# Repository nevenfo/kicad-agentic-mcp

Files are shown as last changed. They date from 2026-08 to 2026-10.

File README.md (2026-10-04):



<div align="center">

KiCad Agentic MCP logo

# KiCad Agentic MCP

</div>

**KiCad Agentic MCP is an MCP server and an agentic control layer for KiCad 10.**
An MCP client — Claude Desktop, Claude Code, or anything else that speaks the
[Model Context Protocol](https://modelcontextprotocol.io) — can place and wire
schematic symbols, place and route footprints in the running PCB editor, run ERC
and DRC, search parts, and produce manufacturing output.

What sits between the model and your design files is the reason this project
exists. A model states an intent; a typed plan is compiled and reference-checked
*before* anything is written; execution is deterministic code run as a
transaction with revision checks and rollback; and the verdict on whether a
change is correct comes from KiCad — `kicad-cli` ERC/DRC, or the design read back
— never from the model's own account of what it did. Task state, evidence and
diffs are held server-side, outside any model's context.

The model is asked to reason where reasoning helps: turning a vague request into
a plan. Everything that has to be exact is code.

**Status: v1.2.0**, AGPL-3.0. The server binary is called `konnect`. Every figure
below traces to [docs/benchmark.md](docs/benchmark.md) or to the document named
beside it; what was missed is stated as missed. Issues and PRs are welcome —
[CONTRIBUTING.md](CONTRIBUTING.md), [naming conventions](docs/NAMING_CONVENTIONS.md).

## The control model

```
User intent
    │
    ▼
LLM planning                      where reasoning is useful
    │
    ▼
Plan IR                           typed, reference-checked
    │
    ▼
Deterministic compile + refusal   a plan that cannot finish never starts
    │
    ▼
Transactional execution           revisions, idempotency, rollback
    │
    ▼
KiCad
    │
    ▼
Independent validation + evidence  kicad-cli, and the design read back
```

The bottom half runs whether or not a model was involved: a client that calls
tools directly gets the same compilation, transaction and validation path.

KiCad 10 offers three access routes, and the layer uses each for what it can
actually do — this is fixed by KiCad, not chosen by preference:

```
                          ┌── Schematic ──→ S-expression engine (atomic writes, no running KiCad)
Agentic control layer ────┼── PCB ────────→ KiCad IPC API (NNG + protobuf, KiCad must be running)
                          └── Verify /
                              export ─────→ kicad-cli (ERC, DRC, Gerber, drill, BOM, PDF, 3D)
```

Schematic IPC is empty on KiCad 10 — `schematic_commands.proto` declares no
commands — so the S-expression engine is the only path that exists, not a
workaround. Details and the KiCad-11 re-evaluation are in
[RELEASE_NOTES.md](RELEASE_NOTES.md#kicad-10-status).

### AI where useful, determinism where required

| Responsibility | Owner |
|---|---|
| Turn an ambiguous or high-level request into a plan | An LLM — your client's model, or an opt-in local model |
| Resolve the current project state | Deterministic — an indexed project graph built from the files and the board |
| Check that a plan's references exist and resolve | Deterministic — the plan compiler refuses before the first mutation |
| Compute coordinates | Deterministic — every coordinate the op library emits is grid-snapped |
| Apply the mutation | Deterministic tool handlers |
| Concurrency, idempotency, rollback | Deterministic — revisions, an idempotency ledger, a snapshot journal |
| ERC / DRC | KiCad, through `kicad-cli` |
| Decide whether the operation succeeded | Validators and evidence records, not model prose |

The LLM row is the only one a model owns, and it is optional: by default the
planning model is whatever your MCP client runs. Nothing in the server calls a
model unless you ask it to.

## What one prompt does

<table>
<tr><th width="50%">Before</th><th width="50%">After</th></tr>
<tr>
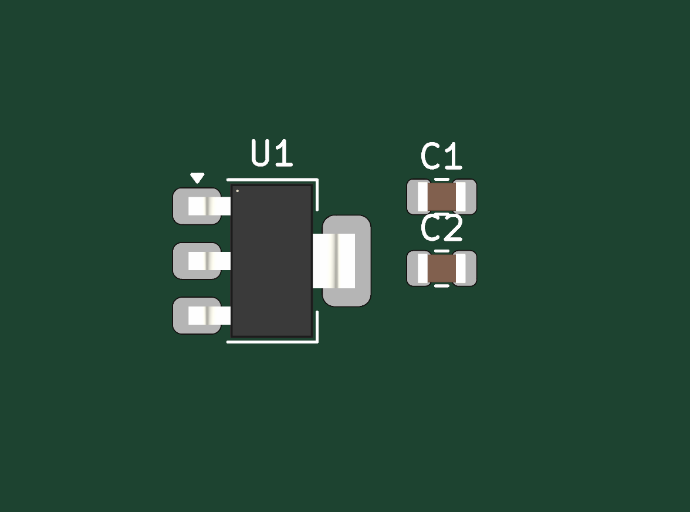
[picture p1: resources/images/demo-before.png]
Three footprints on the board, two capacitors sitting away from the regulator, no copper
<td></td>
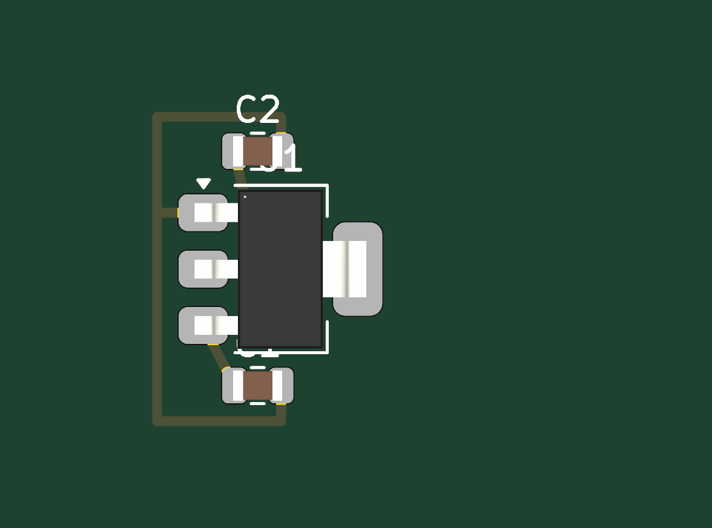
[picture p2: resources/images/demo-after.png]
The two capacitors placed either side of the regulator, three nets closed in copper
<td></td>
</tr>
</table>

One prompt, on the starting board committed in [`examples/demo/`](examples/demo/)
— reproducible from the same files, not an illustration. The prompt asks for the
two capacitors to be placed within 5 mm of the regulator, three nets routed, and
DRC run.

**The verdict is KiCad's:** `kicad-cli pcb drc` reports **5** unconnected items
on the pre-state and **0** afterwards, with 11 track segments and no errors. Run
twice from the same state, it produced the same circuit both times at different
coordinates. Board edits arrive through KiCad's IPC API, so Ctrl+Z walks them
back like any manual edit.

**Two numbers, because they measure two different things:** the board changes
land in **under a second** (0.686 s and 0.773 s of server time), while the prompt
around them takes **6 to 7 minutes**, because the model routes one segment per
turn. Both runs, call by call, are in [`demo-run-2.md`](docs/launch/demo-run-2.md)
and [`demo-run-3.md`](docs/launch/demo-run-3.md); they were run against the
published v1.1.0 binary.

## How execution is controlled

| Mechanism | What it does |
|---|---|
| Plan IR (`preview_plan` / `apply_plan`) | One operation expands into many tool calls, and a later one may reference an earlier one's output. A reference that does not resolve is refused before the first mutation; `preview_plan` returns the exact calls and changes nothing. |
| Gateway (`kicad_describe` / `kicad_invoke`) | Calls any tool by name without adding it to `tools/list`, so the client is never forced to re-fetch the catalogue. `kicad_invoke` takes a batch, stops at the first failure by default, and reports `failed_at` and `not_run`. |
| Transactions and rollback | A batch runs against a directory snapshot; a partial failure restores the before-images. Every mutation leaves an entry in an append-only run journal. |
| Optimistic concurrency and idempotency | `base_revisions` are content-addressed, so an edit made in another window is detected instead of overwritten; an `operation_id` ledger returns the first result on a retry. `changes_since` reports what happened after a revision token. |
| Editor-lock refusal | A `.kicad_sch` KiCad has open is refused (`error_kind: conflict`), re-checked immediately before the commit, leaving the file byte-identical. |
| Semantic diff and evidence handles | Changes are reported by stable item key; snapshots and diffs are addressable MCP resources (`kicad://snapshot/N`, 64 entries). Validator findings carry stable ids, so a fix is an id that disappeared. |
| Task state outside the context | Objective, constraints, verified facts, failed attempts and evidence live server-side and survive a context compaction or a model swap. |
| Project graph | An indexed world model with filtered lookups and spatial neighbours, so a query replaces dumping a whole design. |
| Operating modes | `ReadOnly`, `Write` (default), `Manufacturing`, `Experimental`, enforced before a handler runs so a refusal has nothing to roll back. |
| Structured refusal | A check that could not run is reported as an error, never as a check that passed. |

Architecture, crate by crate, is in [DEV.md](DEV.md#the-agent-layer).

## Measured results

**Against current upstream, on live PCB work:** see
[docs/benchmark-pcb-live-v2.md](docs/benchmark-pcb-live-v2.md) — five live PCB
workflows (schematic → PCB sync, live ≠ saved, zone + net change, flip + via,
schematic parity), the same intention given to this fork and to Konnect
**v0.13.0**, judged by KiCad 10.0.6 alone. That document, not the table below,
is the basis for any comparison with Konnect as it stands today.

**What the table below measured** (token and call cost at the fork point, not
live PCB correctness, and not today's upstream). Seven scripted tasks (schematic authoring, hierarchical
sheets, a template, exports, inspection, and a recovery task where five wrong
inputs must each fail loudly), each starting from an empty directory, five
repeats. Run on 2026-08-24 on one machine — Windows 11, Ryzen 7 9800X3D, KiCad
10.0.3 — against **mixelpixx/Konnect v0.2.2 at commit `5cd6454`**, unmodified,
driven by the same scripted oracle. Success is decided by `kicad-cli` ERC and by
reading the design back, never by a model's prose. Full method, artefacts and
the reproduction commands: [docs/benchmark.md](docs/benchmark.md).

| | Konnect v0.2.2 baseline | This fork, gateway route |
|---|---|---|
| runs passed | 35/35 | 35/35 |
| MCP calls, median per task | 11 | 4 |
| external tokens, median per task | 14 337 | 2 249 |
| wall clock, P50 | 77 ms | 86 ms |

"External tokens" is tool output plus the `tools/list` refreshes the server
forces on the client — a cost the caller cannot decline, and the reason the two
columns differ so much: the gateway route adds nothing to `tools/list`.

**What the same run missed, unmoved:**

- **Wall clock is worse**: 86 ms against 77 ms. The fork loses where it
  guarantees something — the recovery task, which exercises the journal, the
  snapshot manifest and the evidence store, costs +109 ms — and wins where there
  is nothing to guarantee (inspection, 14 → 6 ms).
- **External tokens missed their own target** (≤ 2 000, measured 2 249), and
  **startup `tools/list` missed its target** (≤ ~1 000, measured 2 831 tokens for
  21 tools).
- **Success rate is equal, not ahead.** A scripted route succeeds by construction
  on both servers; what this measures is what the route costs.
- The baseline column was run with one extra toolset loaded, because this fork
  moved `export_bom` between toolsets. Without that, upstream fails the export
  task outright on a taxonomy difference rather than a missing capability; both
  runs are in the benchmark document.

**What this does not measure.** One machine, one KiCad version, scripted routes,
and schematic and export paths only — the golden suite contains no PCB task,
because PCB work needs a running KiCad. It says what a surface costs on that
suite. It does not predict success on an arbitrary KiCad project, and it is not a
statement about Konnect as it stands today.

**The local-model runtime** (`kicad_agent`) is the opt-in path where the server
itself calls a model on loopback: the caller states an objective, the model
writes a Plan IR, and the server compiles, applies and verifies it, with
`kicad-cli` returning the verdict. It has built two of the benchmark designs end
to end, one run each — **no success rate is claimed from that**. Where it was
measured with a sample big enough to carry a number, `gpt-oss-20b` at medium
reasoning wrote a fully correct plan on 16 of 60 one-shot attempts and a
compilable one on 53 of 60. Treat it as working and early, not as a hands-off
autopilot.

## Capabilities

| Area | What it covers |
|---|---|
| Schematic | Symbols, wires, junctions, net labels, power symbols, buses; pin-to-pin connection by name; hierarchical sheets and sheet pins; batch edits |
| PCB | Footprint placement, alignment and duplication; traces, vias, copper pours, net classes, differential pairs; outline, layers, zones, mounting holes, silkscreen |
| Inspection | Net connectivity, pin queries, trace paths, overlap and orphan detection, project-graph queries |
| Validation | ERC and DRC through `kicad-cli`; decoupling, connection, power-rail, DFM and BOM-health audits |
| Fabrication | Gerber, drill, pick-and-place, BOM, netlist, PDF, SVG, 3D, DXF/GenCAD/IPC-2581/ODB++; a fab package with cost estimation and fab-house validation |
| Parts and libraries | Library search and registration, footprint creation and graphics editing, a local JLCPCB parts cache, datasheet lookup, Freerouting autoroute |
| Reference circuits | USB-C, LDO, buck converter, STM32, I2C and LED templates with verified values |
| Bundled for the client | 6 skills and 2 agents carrying KiCad conventions |

**Surface, as a technical fact rather than a headline:** 205 domain tools across
22 toolsets, plus 13 always-visible meta-tools — 217 served in total. The client
does not see them all: startup exposes a **21-tool** starter kit, toolsets load on
demand, and the gateway calls anything by name without listing it at all. Every
tool, with its source file, is in [tool-directory.md](tool-directory.md).

Of the 186 tools inherited from Konnect v0.2.2, 65 (34.9 %) clear the proof
their transport requires; the baseline itself clears 13, scored by the same
scanner. A tool that only edits a document is not counted until KiCAD has
reloaded what it wrote, and one whose whole effect is on the running editor is
not counted until a live session has been asked what it holds — because three
tools were reporting success while writing keys KiCAD does not have, and no
test made only of our own code could see it. The number was 73.7 % under the
older rule, which asked merely that *a* test run. That matrix is generated from
the source and a test fails if it has drifted —
[docs/capability-matrix.md](docs/capability-matrix.md).

## Quick start

Five steps from the release page to a change KiCad itself confirms. Walked on a
machine that had never had this plugin installed; the record, including what went
wrong, is [docs/launch/first-run-walk.md](docs/launch/first-run-walk.md). That
walk measured about nine clicks and dialogs, two KiCad restarts, and a first task
that came back in 108 ms.

**Before you start** you need KiCad 10 and an MCP client. Nothing else: no Node,
no Python, no package tree. Windows is the platform with the most live testing —
see [Known limitations](#known-limitations).

**1 — Download the plugin package.** From
[Releases](https://github.com/nevenfo/kicad-agentic-mcp/releases), take
`konnect-pcm-v<version>-windows.zip` (or `-macos.zip` / `-linux.zip`). The
`konnect-pcm-*` assets are the KiCad plugin packages; the other archives are
standalone server binaries you do not need for this path.

**2 — Install it.** KiCad 10 → **Plugin and Content Manager** → **Install from
File…** → pick the zip. It installs the moment you select the file — the *Apply
Pending Changes* button stays greyed out and there is nothing further to confirm.
Restart KiCad.

**3 — Turn on the KiCad API.** *Preferences → Plugins* → check **Enable KiCad
API**, then restart KiCad. KiCad ships this **off**, and every PCB tool here
talks to KiCad through it. Schematic editing and exports work without it; live
board editing does not. After the restart the same page should read
`Listening on ipc://…`.

**4 — Point your MCP client at the server.** After a PCM install the binary lives
in your KiCad documents folder:

```
C:\Users\<YOU>\Documents\KiCad\10.0\3rdparty\plugins\com_github_mixelpixx_konnect\bin\konnect.exe
```

Put that path in your client's MCP config — `%APPDATA%\Claude\claude_desktop_config.json`
for Claude Desktop, a `.mcp.json` in your project root for Claude Code:

```json
{
  "mcpServers": {
    "konnect": {
      "command": "C:\\Users\\<YOU>\\Documents\\KiCad\\10.0\\3rdparty\\plugins\\com_github_mixelpixx_konnect\\bin\\konnect.exe"
    }
  }
}
```

Copy-paste versions of both files are in [examples/](examples/). Restart the
client; the server should report **21 tools** at startup — the starter kit. The
rest of the catalogue loads on demand, or is called through the gateway without
ever appearing in `tools/list`. **No settings file is required** for a standard
KiCad 10 install: the server discovers `kicad-cli`, the KiCad GUI binary and the
IPC address. Explicit settings remain available for unusual or portable
installations.

**5 — Give it something to do**, with a KiCad project open. For example:

> *Add a 3.3 V LDO regulator subcircuit to my schematic and run ERC on it.*

The reply should name the parts it placed — a regulator, its input and output
capacitors — and carry an ERC result that came from `kicad-cli`, not from the
model. Open the schematic in KiCad: the symbols are there.

**Check the install itself** at any point: open a project (KiCad's PCB editor
refuses to open without one), then **PCB Editor → Tools → External Plugins**,
where you should see **Konnect**.

**If any of those five steps did not work for you**, that is the thing worth
reporting: [file a first-run report](https://github.com/nevenfo/kicad-agentic-mcp/issues/new?template=first-run.yml).
It takes about two minutes and it is the only way any of this gets measured on a
machine that is not the maintainer's.

### Requirements

- **KiCad 10.** Built and measured against 10.0.3; the live schematic and PCB
  suites of v1.2.0 were also run against 10.0.6. Other 10.0.x releases are
  untested here rather than known-bad.
- **`kicad-cli`**, which ships with KiCad and is used for exports, ERC and DRC.
  KiCad's installer does not put it on `PATH`; the server searches the usual
  install locations and logs which one answered, and you can name it explicitly.
- **For PCB tools: KiCad running** with the target board open and the KiCad API
  switched on (*Preferences → Plugins → Enable KiCad API*, which ships off).

### Build from source

```bash
# protoc is required (protobuf code generation), and cmake (the nng crate
# compiles the NNG C library with it).
# Windows: choco install protoc cmake
# macOS:   brew install protobuf cmake
# Linux:   apt install protobuf-compiler cmake
cargo build --release -p konnect
```

The resulting `target/release/konnect` is the MCP server. The published v1.1.0
Windows binary measured 23.7 MB, unstripped; there is no `[profile.release]`
override, so a local build is the same shape.

### macOS

The PCM package bundles a universal binary; the standalone archives ship
Apple Silicon (`aarch64-apple-darwin`) and Intel (`x86_64-apple-darwin`) builds.
**They are not code-signed or notarised**, so Gatekeeper refuses them on first
launch — clear the quarantine attribute:

```bash
xattr -dr com.apple.quarantine ./konnect   # or the folder KiCad installed it into
```

KiCad on macOS keeps its tools inside the app bundle and off `PATH`; the server
searches the standard bundle and uses KiCad's default IPC address. Only an
unusual or renamed install needs overrides in
`~/Library/Application Support/konnect/config.toml`:

```toml
kicad_cli = "/Applications/KiCad/KiCad.app/Contents/MacOS/kicad-cli"
kicad_binary = "/Applications/KiCad/KiCad.app/Contents/MacOS/kicad"
# Optional override; the default is ipc:///tmp/kicad/api.sock.
ipc_address = "ipc:///tmp/kicad/api.sock"
```

Claude Desktop's config lives at
`~/Library/Application Support/Claude/claude_desktop_config.json` and takes the
same `mcpServers` snippet with a Unix path.

### Schematic viewer

A standalone viewer that auto-refreshes as the schematic file changes:

```bash
schematic-viewer.exe path\to\your\root_schematic.kicad_sch
```

Point it at the root sheet of a hierarchical design and every sub-sheet is
rendered too, with a depth-indented selector. Only the sheets that changed
re-render, against temp-folder snapshots, so the viewer never blocks KiCad from
saving. The AI can launch it via `open_schematic_viewer`. Needs the WebView2
runtime (pre-installed on Windows 10/11) and `kicad-cli`; built separately from
the main workspace — see [DEV.md](DEV.md).

### Transport

MCP JSON-RPC over stdio by default. Streamable HTTP is available with
`transport = "http"` (or `"both"`): POST and GET/SSE on a single `/mcp`
endpoint, with Origin validation and a `/health` probe.

## Known limitations

Stated as four different things, because they are:

**Tested — Windows.** The first-run walk, the demo runs, the benchmark and the
live schematic and PCB suites all ran on Windows 11 with KiCad 10.0.3 (and 10.0.6
for the live suites of this release).

**Supported but less tested — macOS and Linux.** macOS works from the release
binaries or a source build and is not signed or notarised. Linux compiles and
passes CI but has had **no per-platform QA against a running KiCad**. Both are on
the [roadmap](ROADMAP.md).

**Experimental — the local-model runtime.** It works, and its measured plan
quality is the figure quoted above (16/60 fully correct one-shot). It is not a
hands-off autopilot, and no success rate is claimed for it on real projects.

**Not yet built, or not possible here:**

- **PCB tools need a running KiCad** with the API on and the board open. pcbnew
  has no headless mode, so there is no headless PCB path. A desktop session is
  required; a human watching it is not.
- **Symbols and footprints are placed, not authored from scratch.** Footprints
  can be created and their graphics edited; authoring new library symbols is on
  the [roadmap](ROADMAP.md).
- **Schematic editing does not go through IPC** because KiCad 10 exposes no
  schematic IPC commands. This is re-evaluated at KiCad 11, not before.
- **A schematic open in Eeschema is refused, not merged.** Close the editor, or
  work on a copy.
- The benchmark covers a controlled seven-task suite on one machine. It does not
  generalise to arbitrary projects.
- The evidence store holds 64 entries; older handles age out and report
  differently from handles that never existed.

**No telemetry.** The binary reports nothing, anywhere, ever. Everything known
about how it behaves on other people's machines came from someone choosing to
write it down; the tally is [docs/adoption.md](docs/adoption.md).

## Troubleshooting

- **Plugin doesn't appear** — install via the Plugin and Content Manager, not a
  manual copy, then restart KiCad. The entry is under *Tools → External Plugins*
  in the **PCB editor**, which will not open until a project is open.
- **"IPC connect failed"** — two things must both be true: *Enable KiCad API* is
  checked, and KiCad is running with the board open. The API page reads
  `Listening on ipc://…` after a restart.
- **"Failed to spawn kicad-cli"** — the server tries your config value, `PATH`,
  the known install prefixes (including the per-user
  `%LOCALAPPDATA%\Programs\KiCad\<ver>\bin`), then the registry, and logs which
  one answered.
- **A validator reports an error instead of zero findings** — deliberate. A check
  that could not run is never reported as a check that passed.

Longer walkthroughs: [docs/TROUBLESHOOTING.md](docs/TROUBLESHOOTING.md).

## Architecture and references

- [DEV.md](DEV.md) — architecture, the agent layer crate by crate, build steps
- [tool-directory.md](tool-directory.md) — every tool, generated from the source
- [docs/benchmark.md](docs/benchmark.md) — method, artefacts, every number and
  every missed target
- [docs/capability-matrix.md](docs/capability-matrix.md) — what has a test that
  runs, generated and gate-checked
- [docs/local-agents.md](docs/local-agents.md) — the local-model seam, and how it
  was measured
- [RELEASE_NOTES.md](RELEASE_NOTES.md) · [ROADMAP.md](ROADMAP.md) ·
  [CONTRIBUTING.md](CONTRIBUTING.md) ·
  [docs/TROUBLESHOOTING.md](docs/TROUBLESHOOTING.md)

## Relationship to Konnect

```
KiCAD-MCP-Server        Python/TypeScript, MIT, still open and maintained
       │
       ▼
    Konnect             Rust rewrite: one binary, KiCad 10 IPC, toolset router
       │
       ▼ forked from v0.2.2 (commit 5cd6454)
KiCad Agentic MCP       this repository
```

**What comes from upstream:** the Rust single-binary architecture, the KiCad 10
IPC path for the PCB, the S-expression schematic engine, `kicad-cli` for exports
and checks, and the toolset router — the client loads toolsets and calls tools by
name. All of that still works here, unchanged.

**What this fork adds:** the gateway (`kicad_describe` / `kicad_invoke`), the Plan
IR and its deterministic executor, transactions with rollback and a run journal,
revisions and an idempotency ledger, semantic diffs and evidence handles, task
state held outside any model's context, the indexed project graph, tool
capability annotations, and the opt-in local-model runtime. These are the `kam-*`
crates, clean-room and `MIT OR Apache-2.0` in their own manifests, with
KiCad-side adapters in `konnect-core`.

The benchmark above compares this fork against **Konnect v0.2.2 at commit
`5cd6454`**, the exact point it was forked from. It says nothing about Konnect as
it stands today, and no claim of superiority over the current upstream is made or
intended. Upstream remains a separate project under the same AGPL-3.0 licence.

The binary is still called `konnect` and the plugin identifier is still
`com.github.mixelpixx.konnect`, so an existing MCP client configuration keeps
working.

## License

AGPL-3.0-only, workspace-wide — see [LICENSE](LICENSE). Hobbyists, students,
freelancers and open-source projects can use it freely. For a business, the AGPL
requires that anything built on or around it — including software provided over a
network — be open-sourced under the same licence; if that does not work for you,
commercial licences are available: [COMMERCIAL.md](COMMERCIAL.md).

The generic `kam-*` crates (state, evidence, plan, graph, context, llm, runtime)
are clean-room and `MIT OR Apache-2.0` in their own manifests.

## Support

- **Tried it for the first time?**
  [File a first-run report](https://github.com/nevenfo/kicad-agentic-mcp/issues/new?template=first-run.yml)
  — six questions, most of them one click. A report from someone who **gave up**
  is worth more than one from someone who succeeded.
- Bugs and feature requests: [GitHub Issues](https://github.com/nevenfo/kicad-agentic-mcp/issues)
- Installation or IPC problems: [docs/TROUBLESHOOTING.md](docs/TROUBLESHOOTING.md)

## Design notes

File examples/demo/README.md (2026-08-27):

# The canonical demo

One task, and the result appears **in KiCad's own canvas** — not in a terminal.
The AI arranges a subcircuit on the open board and routes it; pcbnew redraws as
it happens, and the changes land in KiCad's undo stack like any manual edit.
The board changes take under a second of Konnect time; the model conversation
around them takes six to seven minutes.

This is the demo the project's launch material shows. It is committed here so
anyone can repeat it from the same starting point and get the same end state.

## Starting point

A real project, not a blank file:

| File | What is in it |
|---|---|
| `konnect-demo.kicad_sch` | `U1` AP1117-33 regulator, `C1` and `C2` 10 µF, footprints assigned, nets `VIN`, `VOUT`, `GND`, two `PWR_FLAG`s. **ERC: 0 errors, 0 warnings** |
| `konnect-demo.kicad_pcb` | a 60 × 45 mm board carrying the three footprints **imported from that schematic and left in a heap**, with their nets. **DRC: 5 missing connections**, 1 silkscreen-clearance warning |
| `konnect-demo.kicad_pro` | the project that ties them together |

The five missing connections are the point. They are what the demo closes.

**Why a schematic ships with a PCB demo:** a KiCad board has nets only because a
schematic gave it some. Routing addresses nets, so a board that never came from
a schematic cannot be routed — by Konnect or by anything else. This is not a
detail of the demo; it is how KiCad works, and pretending otherwise produces a
demo that cannot finish.

Do not edit these files in place. Copy the folder somewhere else and run the demo
on the copy, so the committed pre-state stays the pre-state.

## Setup, once, off the clock

1. Install Konnect and point your MCP client at it — the
   [Quick start](../../README.md#quick-start) has the five steps.
2. In KiCad: *Preferences → Plugins* → **Enable KiCad API**, then restart KiCad.
   PCB tools talk to a running KiCad through that socket; without it there is
   nothing to watch.
3. Open your copy of `konnect-demo.kicad_pro` in KiCad and open its **PCB
   editor**. Leave it on screen — this is what the demo shows.

The setup is outside the measured prompt time.

**On v1.1.1, a standard KiCad 10 install needs no Konnect settings file.**
Konnect discovers `kicad-cli`, the KiCad GUI binary and the IPC address. Use an
explicit override only for an unusual or portable installation; see
[Troubleshooting](../../docs/TROUBLESHOOTING.md).

## The prompt

Ask for it in one turn, exactly this:

> These three footprints were just imported from the schematic and are sitting
> in a heap. Place C1 and C2 within 5 mm of the regulator U1, route VIN, VOUT
> and GND, and run DRC when you are done.

## What you should see

In the KiCad window, without touching it:

- the two capacitors move out of the heap and settle beside the regulator;
- copper traces appear between them, on the nets the schematic named;
- KiCad's undo (Ctrl+Z) walks the changes back, because they arrived through
  KiCad's own API rather than by rewriting the file underneath it.

And in the reply: a DRC result that came from `kicad-cli`, not from the model.
A check that could not run is reported as an error, never as a clean board.

The committed pair — [`before`](../../resources/images/demo-before.png),
[`after`](../../resources/images/demo-after.png) — is what run 2 produced, and
both images come from the board files themselves, same frame and same zoom:

```bash
kicad-cli pcb render --side top --zoom 2.8 --pivot "0.2,0.25,0"   -w 1200 -h 900 --background opaque -o before.png konnect-demo.kicad_pcb
```

Run the same command on the board after the prompt for the other half. Your run
will not match pixel for pixel — a model does not place a capacitor at identical
coordinates twice — and it does not need to: what has to match is the circuit.

## Verifying it afterwards

From the folder you ran the demo in:

```bash
kicad-cli pcb drc --format json -o drc.json konnect-demo.kicad_pcb
```

The pre-state reports **5 missing connections**. A finished run reports **0**.
KiCad, not Konnect and not the model, decides that.

## Reproducing

Start again from the committed files and issue the same prompt. What has to match
is the circuit, not the pixels: same three parts, same three nets connected, same
DRC verdict. A model will not place a capacitor at identical coordinates twice.

It has been run twice this way — `docs/launch/demo-run-2.md` and
`demo-run-3.md`. Both closed the three nets with 11 segments and left KiCad
reporting 0 unconnected items and no errors; both placed the capacitors within
5 mm of `U1`, at coordinates 0.6 mm apart, and run 3 rotated `C2` where run 2
did not.

## How long it takes, and what that measures

Two numbers, because they measure two different things:

- **The board changes land in under a second.** Every call that alters the board
  — the placements, the rotation, the eleven traces, the saves — totalled
  **0.686 s** in run 2 and **0.773 s** in run 3, the slowest single write 0.07 s.
  Including `run_drc`, which is KiCad doing its own check, all Konnect calls came
  to 2.3 s and 4.7 s.
- **The prompt takes 6 to 7 minutes** end to end — 377 s over 47 turns, 424 s
  over 52. That is the model looking, deciding, and routing one segment per turn;
  there is no batch *route this net* call to collapse it into one.

The 40 s figure this demo was first written against measured neither: it was
chosen before anything had been run. It is published here as the two measured
numbers instead, because a demo whose claims survive checking is worth more than
a fast one.

## If you rebuild the pre-state yourself

The board was produced by KiCad's own *Update PCB from Schematic*, which is
available **only when the PCB editor was launched from the KiCad project
manager**. Started standalone, pcbnew refuses with *cannot update the PCB because
the PCB editor is open in standalone mode*. Konnect has no equivalent tool, which
is why this step is setup rather than part of the demo.

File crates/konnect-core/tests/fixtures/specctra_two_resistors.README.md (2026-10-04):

# Specctra two-resistor board fixture

`specctra_two_resistors.kicad_pcb` is a deliberately small two-layer board used
to test the first fail-closed Specctra export profile. It was derived from the
repository's existing PCB integration fixture, assigned stable test UUIDs and a
closed rectangular outline, then opened and re-saved by KiCad 10.0.5 with:

```text
kicad-cli pcb upgrade --force specctra_two_resistors.kicad_pcb
```

That final KiCad-authored serialization is intentional. In particular, it
captures KiCad 10's direct `(net "NAME")` pad syntax rather than relying on a
hand-written approximation of the board format.

`specctra_two_resistors.native-kicad-10.dsn` was exported from that board by
KiCad 10.0.5's real `pcbnew.ExportSpecctraDSN(board, path)` binding. Only the
environment-specific absolute output path in the root `(pcb ...)` identifier
was normalized to `board.dsn`; structure, placement, library, network, rules,
and wiring content remain KiCad-authored. It is the differential fixture for
the optional KiCad 10 ActionPlugin bridge.

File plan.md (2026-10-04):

# PLAN — KiCad Agentic MCP

Strategic source of truth: final target, invariants, full roadmap, dependencies
and validation criteria. Operational state lives in `progress.md`; measurements
live in `docs/benchmark.md`, `docs/local-agents.md`, `docs/capability-matrix.md`
and `bench/results/`; history lives in Git.

**Identifier convention.** Phase letters (`A`…`M`) are the historical phase
names. Lots and tasks are dotted — `D.4`, `H.5.3` — so they never collide with
this project's decision records (`D31`) and defect records (`E24`), which are a
separate namespace referenced from code comments, commit messages and `docs/`.
Look a task up with `rg "H\.5\.3" plan.md`; do not read this file whole.

## Objectif final

Turn the `mixelpixx/Konnect` fork into a KiCad **agentic control layer**: a large
internal capability surface, a small external MCP surface, local LLM agents that
absorb operational work, a deterministic engine for everything that does not need
generative reasoning, task state and evidence held outside any model's context,
and verification that comes from KiCad rather than from an agent's own opinion.

```
WORKSPACE  C:\Users\FlowUP\kicad-agentic-mcp\konnect-agentic   branch agentic/main
BASE       mixelpixx/Konnect @ 5cd6454 (v0.2.2), AGPL-3.0-only, workspace-wide
KICAD      10.0.3, C:\Users\FlowUP\AppData\Local\Programs\KiCad\10.0\bin\kicad-cli.exe
HARDWARE   RTX 5080 16 303 MiB VRAM · Ryzen 7 9800X3D · 32 GiB RAM · LM Studio
```

16 GB VRAM is the hard budget for any local model: it must hold the model, the
KV cache and whatever KiCad's GUI is using.

## Invariants

Rules that survive every phase. Breaking one is a defect, not a trade-off.

- **INV1 — the verdict is KiCad's.** A design is declared sound by `kicad-cli`
  ERC/DRC, never by Konnect's own analysis and never by a model. A validator that
  could not run is a failure, never zero findings.
- **INV2 — generic subsystems stay re-licensable.** New `kam-*` crates are
  clean-room, `MIT OR Apache-2.0`, and depend on no `konnect-*` type. The KiCAD
  half of each lives in `konnect-core::<same name>`. AGPL never flows into them;
  absorbed MIT code travels with its notice.
- **INV3 — no mutation without an audit record**, and every change carries its
  own proof (semantic diff on by default, evidence handles, call log).
- **INV4 — refuse before the first mutation.** Compile-time reference checking,
  `base_revisions`, unknown validator names and unrecognised `verify` values are
  all rejected before anything is written. A caller who believes a check ran when
  it did not is the worst failure mode this project has shipped.
- **INV5 — one grid, one place.** Every electrically meaningful `(at x y)` goes
  through the single snapping helper over `SCHEMATIC_GRID_MM` (1.27 mm). A
  guarantee that holds *usually* is the bug it is meant to prevent.
- **INV6 — a target that is missed is recorded as missed**, never moved to match
  the result, and no win is netted off against it. A number that cannot be
  reproduced from the repository is not a result.
- **INV7 — advisory analysis says so at the call site**, in the tool description
  an agent actually reads, not only in a generated document.
- **INV8 — accept what a model writes only when it has exactly one meaning.**
  Genuine ambiguity stays refused; a widened acceptance must never turn a
  previously compiling input into a failure.
- **INV9 — the local inference backend is loopback-only** unless a named
  constructor says otherwise. Exposing it to the network must be something
  somebody typed.
- **INV10 — the KiCad access strategy is fixed by KiCad 10, not by preference:**
  PCB over IPC, schematic over the S-expression engine, validation and export
  over `kicad-cli`. Do not fork KiCad; re-evaluate at KiCad 11 (Phase I).
- **INV11 — a checkbox in this file means proof**, not intention: targeted tests,
  integration, gate, or a benchmark run whose artefact is committed.

## Plateforme : KiCad 10 ground truth

Verified against KiCad sources, 2026-08-10. These are constraints, not opinions.

| Fact | Consequence |
|---|---|
| IPC = NNG REQ/REP + protobuf envelope, `KICAD_API_SOCKET` / `KICAD_API_TOKEN`, API disabled by default | `doctor` must check and say so |
| No protocol version, only `GetVersion` | capability probing is behavioural |
| **No async events, no pub/sub** | the event journal is ours: revisions + targeted diffing + file watching. Never advertise push notifications |
| Server is single-threaded on the UI thread | serialise IPC, own timeout/retry, expect `AS_BUSY` |
| `BeginCommit` / `EndCommit` exist on PCB **and** SCH handlers | the real transaction primitive for the IPC path |
| PCB coverage complete over IPC | PCB path = IPC |
| **Schematic IPC is empty on 10.0** (`schematic_commands.proto` has no commands, `getItemFromDocument()` returns `nullopt`) | schematic path = S-expression engine |
| `kicad-python` 0.8.0 + `kicad-cli api-server` target **KiCad 11** | headless schematic IPC is upstream work; do not fork KiCad 10 |
| S-expr versions on 10.0: board `20260206`, schematic `20260306`, symbol lib `20251024` | parser/writer compat matrix |

## Architecture cible

```
harness (Claude Code / Codex)
        │  EXECUTION PATH: delegate            AUDIT PATH: query / verify / evidence
        ▼
┌──────────────────────────┐
│ MCP GATEWAY (small)      │  kicad_describe + kicad_invoke                SHIPPED
├──────────────────────────┤
│ TASK STATE MANAGER       │  objective / constraints / facts / failures   SHIPPED
├──────────────────────────┤
│ CONTEXT + ATTENTION MGR  │  anchor · budgets · compaction · retrieval       SHIPPED
├──────────────────────────┤
│ AGENT ROUTER             │  NO_LLM | LOCAL | ESCALATE (fitted, H.6.2)        SHIPPED
├──────────────────────────┤
│ LOCAL AGENT RUNTIME      │  supervisor / schematic / pcb / verification      SHIPPED
├──────────────────────────┤
│ PLAN COMPILER + PLAN IR  │  typed, reference-checked, batched            SHIPPED
├──────────────────────────┤
│ DETERMINISTIC ENGINE     │  ~190 capabilities + revisions + transactions SHIPPED
├──────────────────────────┤
│ KiCad: IPC (PCB) · S-expr (SCH) · kicad-cli (validate/export)
├──────────────────────────┤
│ VALIDATION + EVIDENCE    │  ERC/DRC, semantic diff, evidence packs       SHIPPED
└──────────────────────────┘
```

Crates (new ones obey INV2):

```
crates/konnect-*      existing, AGPL, refactored in place
crates/kam-state      revisions, idempotency, snapshots, Task State + anchor      SHIPPED
crates/kam-evidence   semantic diff over an abstract ItemSet, handle store,
                      findings with stable ids                                    SHIPPED
crates/kam-plan       Plan IR, compiler, reference resolution, execution FSM      SHIPPED
crates/kam-graph      indexed store + query/neighbour language                    SHIPPED
crates/kam-llm        local provider abstraction (+ router, not built)            PARTIAL
crates/kam-context    budgets, compaction, retrieval                              SHIPPED
crates/kam-bench      benchmark runner + metrics schema                           NOT BUILT (Python harness in bench/ does the job today)
```

## Critères globaux de réussite (V1)

Current values: `docs/benchmark.md`. Targets are never moved (INV6).

- [x] `SUCCESS_RATE` ≥ baseline — **35/35 against the baseline's 35/35** (M.1,
      seven tasks × 5, both servers measured back to back on 2026-08-24). Equal,
      which is what `≥` asks; a scripted route succeeds by construction on both
      sides, and the fork's margin is in what the route costs and in what
      happens when nobody scripts it
- [x] median `MCP_CALLS` per task ≤ 5 — **4**
- [ ] `WALL_CLOCK_P50` ≤ baseline — **86 ms against 77 ms, missed by 9 ms**
      (M.1). The recorded pair was 65 against 70. The mechanism is per-task and
      visible: the fork loses where it guarantees something — `recovery`
      +109 ms, the task built to exercise the transaction journal, the snapshot
      manifest and the evidence store — and wins where there is nothing to
      guarantee (`sch_inspection`, 14 → 6 ms). The direction is stable and the
      magnitude is not: an earlier `--repeat 3` pair the same day reads 69
      against 87, the fork slower by 18 rather than by 9. Recorded as missed
      (INV6); nothing was tuned to recover it
- [x] silent corruption / silent stale-state write = **0** — refused by `base_revisions`
- [x] mutations without an audit record = **0**
- [ ] external tokens/task ≤ 2 000 — **2 249**, missed by 249 in deliberate
      trades (diff on by default, task filing, verification, and D.5's snapshot
      handle at +18); recorded as missed, never netted off against a win.
      M.1 re-measured it and found +68 since `k12-gateway.json` (2026-08-17):
      F.5.7's descriptions and K.2's annotations both ride inside
      `kicad_describe` results, so both are paid per task and not only on the
      startup surface. K.2's +342 at startup was measured when it landed; this
      is its per-task share, measured now
- [ ] `tools/list` at startup ≤ ~1 000 — **2 831**, missed; only reachable by
      retiring the toolset-loading path, which would break every shipped skill.
      Re-measured at `91b9911` before touching anything: the recorded 2 034 was
      stale — the surface had already drifted to **2 489** as descriptions grew.
      K.2's annotations then cost **+342** (2 489 → 2 831, +13.7 %; full catalog
      29 399 → 33 183). Paid deliberately: a surface a headless client will not
      call is worth no tokens at all. The cheaper shape was measured, not
      assumed — dropping `openWorldHint` from read tools saves 78 of the 342
      and was rejected, because omitting it asserts the MCP default of
      *open world* about every read tool to save 2.8 %
- [x] retrieval precision @8 ≥ 60 % — **62.0 %** (recall @8 **100 %**) — F.5
- [ ] `LLM_CALLS_PER_SUCCESSFUL_TASK` materially below baseline — measured
      **15 → 5.5** inside the model-fit harness, but **no baseline for this
      metric was ever measured**, so the criterion is not claimed met
- [x] `CAPABILITY_COVERAGE` > baseline — **72.6 % against the baseline's
      22.6 %**, on a frozen denominator of 186, with no regression. Defined in
      J.2.1 and rendered in `docs/capability-matrix.md` under
      *V1 comparison target*: the 187 tools the baseline registers at `5cd6454`
      (this fork still registers all of them), minus what KiCAD gives no API
      for, scored on both sides by the same scanner. The headline number is
      the whole-surface number and is deliberately not the criterion — its
      denominator grows with every tool added; it stands at **72.6 %** too after
      J.2.3. Nothing this fork adds can enter the frozen denominator, so that
      percentage moves only when a test that runs starts proving a tool

---

# Phase A — Bootstrap — DONE

## A.1 — Base selection (Gate 0)

### Objectif
Choose the base repository on measured evidence and record the licence posture.

### Dépendances
None.

### Tâches
- [x] A.1.1 Compare `Konnect` / `kicad-mcp-pro` / legacy `KiCAD-MCP-Server`
- [x] A.1.2 Verify licences and choose officially → Konnect, AGPL-3.0-only
- [x] A.1.3 Clone into a clean workspace, branch `agentic/main`

### Validation
`cargo test --workspace --lib --tests` → 469 passed on the untouched fork.
Full comparison and rationale: `git show HEAD:plan.md` (Gate 0 sections, before
this file was migrated) and decisions D1/D2.

**Why not `kicad-mcp-pro` as the base** (still the reason not to migrate): its
schematic writer depends on `kicad-sch-api`, which drops `global_label` nodes on
save, so its own mitigation refuses the write; profiles are boot-time only; three
build systems; 251 Python modules force deferred registration. Its *ideas* were
adopted clean-room and are tracked as tasks (D.6, D.7, D.8, D.9, J.5, M.1).

## A.2 — Build, tests, real MCP session — DONE

### Tâches
- [x] A.2.1 Build and test the fork on this machine (`protoc` provisioned, E1)
- [x] A.2.2 Run the server against a real harness over stdio
- [x] A.2.3 `gate.ps1` mirrors the upstream CI gate

### Validation
`gate.ps1` green; per-user KiCad installs discovered (E3).

---

# Phase B — Cartography — DONE

## B.1 — Map the base

### Tâches
- [x] B.1.1 Map transport, registry, IPC, S-expression engine, validation, errors
- [x] B.1.2 Verify the KiCad 10 ground truth against KiCad's own sources

### Validation
The ground-truth table above; every claim traced to a KiCad source file.

---

# Phase C — Baseline benchmark — DONE

## C.1 — Golden suite and metrics

### Objectif
Measure the untouched base before any refactor, so every later claim has a floor.

### Dépendances
A.2.

### Tâches
- [x] C.1.1 Golden projects + task set (6 tasks × 3 load modes = 18)
- [x] C.1.2 Metrics schema: tokens, calls, latency, success
- [x] C.1.3 Baseline recorded

### Validation
`docs/benchmark.md`, `bench/results/*baseline*.json`: 12 373 external tokens/task,
11 MCP calls, 18/18.

---

# Phase F — Compact MCP surface — DONE

## F.1 — Capability index and tool-granular loading

### Tâches
- [x] F.1.1 `find_capabilities` + `load_tools` beside `list_toolboxes` / `load_toolset`
- [x] F.1.2 Keep both loading paths (D5: removing one breaks every shipped skill)

### Validation
Retrieval recall @8 = 100 %; measured in `docs/benchmark.md`.

## F.2 — Schema compression and starter kit

### Tâches
- [x] F.2.1 Compress heavy inlined schemas — no `$defs`/`$ref` (D7: client chain
      mangles them; several upstream issues recommend inlining instead)
- [x] F.2.2 Shrink the starter kit — `config` leaves, two tools re-admitted
      individually (D8), checked against `find_capabilities` on their own intents

### Validation
3 698 → 3 197 tk/task, startup 1 958 → 1 454 at the time.

## F.3 — The gateway

### Objectif
A catalogue that never has to be refreshed: `CATALOG_TOKENS` → 0.

### Tâches
- [x] F.3.1 `kicad_describe` + `kicad_invoke` — **two** verbs, not seven (D9)
- [x] F.3.2 Batch semantics: `stop_on_error`, and `atomic` follows it unless set
      explicitly (D10 — found by the benchmark, not by review)

### Validation
1 995 tk/task, 4 MCP calls, `CATALOG_TOKENS` 0, 18/18.

## F.4 — Capability matrix

### Tâches
- [x] F.4.1 `docs/capability-matrix.md` generated from `konnect-core::capability`
- [x] F.4.2 `SUPPORTED` is discovered from tests and golden tasks, never declared
      (D26); `#[ignore]`d tests read `gated`; what KiCad has no API for leaves the
      denominator
- [x] F.4.3 Three tests: manifest names every registered tool, names no tool that
      does not exist, committed markdown equals what the code renders

### Validation
`KAM_UPDATE_MATRIX=1` regenerates; the equality test fails if it drifts. First
render 27.3 %, now 28.6 %. Note: `bench/probes` counts as evidence as well as
`bench/tasks`, so adding a probe can move the number.

## F.5 — Retrieval precision — MET

### Objectif
22.4 % precision @8 at the recall needed to succeed. The gateway made each wrong
guess cheap; it did not make the guess right.

**Closed at 62.0 % precision / 100.0 % recall** (b3a1572), measured by
`bench/runner.py --load-mode search`. The suite's success rate in that mode
went 6/7 to 7/7 and external tokens per task 10 446 → 5 205.

### Dépendances
None. Plural stemming was implemented, measured and **rejected** (D6): recall
100 % → 98.2 % at 8 results. Do not re-attempt it.

### Tâches
- [x] F.5.1 Find a retrieval change that raises precision without costing recall
      — four of them, in F.5.4 through F.5.6: IDF weighting, clause splitting,
      a relative cutoff per clause, and one tool per family. Recall went up
      rather than down (97.1 % → 100 %).
- [x] F.5.2 Answer whether a compiled plan moves precision at all. **It does
      not**, and it fails in both directions at once, measured by
      `bench/plan_retrieval.py` at limit 8 on one build against the direct
      shape of `01_sch_divider` read from the task file: not one of four
      goal-stated queries returns `apply_plan`, at rank 8 or at rank 30 —
      "build a resistive voltage divider" returns `audit_power_rails` — because
      the description is about the mechanism of calling and shares no
      vocabulary with a query saying what to build; and for a caller who does
      name the mechanism, retrieval finds it at rank 1-2 while precision falls
      to 11.1 %, since the plan collapses |needed| from 5 to 1 without
      collapsing what search returns. The plan path is entered by prior
      knowledge, never by search, and precision @8 is the wrong instrument for
      it — its measured win is schema tokens (G.3: -48.4 % / -61.1 %)
- [x] F.5.3 Reverse prefix: the one-sided form of what D6 rejected. A query
      term that is the longer, plural side of a corpus term of at least three
      characters scores a fallback +4/+1, and only when nothing stronger
      already matched — purely additive, so D6's failure mode cannot recur,
      and its negative control is now a pinned test. Measured: recall on the
      seventh task 94.3 % → 97.1 %, hist6 recall unchanged at 100 %, precision
      22.5 % → 22.2 %. It buys recall, not precision; F.5.1 stays open.
- [x] F.5.4 The precision ceiling is *how many* results come back, not their
      order: every intent returns a full `limit`, so the union is ~33.8 tools
      per task against ~7.5 needed. A relative score threshold cuts the union
      to 12 and lifts precision to 65 %, but drops recall to 94 %, and every
      tool it drops is one whose intent is **composite** — a single intent
      asking for two or three tools, lexically dominated by one of them
      (`apply_template` behind `search_templates`, `generate_netlist` behind
      `export_netlist`). 8 of the 34 golden intents are composite. Measure
      clause splitting (search each clause of an intent separately, threshold
      per clause, merge by ratio-to-clause-best) against the threshold alone.
      **Measured**: precision 22.5 % → 58.7 % at unchanged 100 % recall on the
      historical perimeter, union 33.8 → 13.5. `apply_template` and
      `generate_netlist` both recovered. It does nothing for the two tools left
      in `07_sch_inspection`, whose intents are single-clause.
- [x] F.5.5 The two stragglers are a vocabulary problem, not a ranking one, and
      the fix is two levers that only work together: `where` → position /
      coordinates / locations recovers `get_schematic_pin_locations`, and a
      description that names the concept in the domain's own words —
      `get_schematic_component` says neither "component" nor "reference"
      anywhere but in its own name — recovers `get_schematic_component`. Two
      other levers were measured and are not shipping (D64). All seven tasks
      now reach 100 % recall, at 54.9 % precision.
- [x] F.5.6 Close the remaining ~5 precision points and port the winning
      configuration into `capability_search`. The cap is no longer
      `07_sch_inspection`: it is dilution on the two widest tasks, where a
      one-word clause spends three slots on near-ties. **The budget per clause
      was a dead end** — measured at zero, its apparent gain being a true
      positive lost rather than noise removed. What paid was one tool per
      family: three spellings of "place a component" spent three of the
      caller's eight slots, and capping the family removed 14 tools on the
      golden suite of which 14 were tools no task needed. Ported with a
      family key that keeps the terms of a name **in order**, because
      `get_component_nets` and `get_net_components` are different tools —
      pinned by a test, since the golden suite never asks for both.
- [x] F.5.7 Decide whether `apply_plan` / `preview_plan` should name the design
      actions their operation library covers — place, power, label, wire,
      connect, decouple — which is exactly the lever that recovered
      `get_schematic_component` in F.5.5. Opened by F.5.2's finding, and
      deliberately not taken with it: a description that ranks for "place
      resistor symbols" puts `apply_plan` in competition with
      `batch_place_components` on every direct task, and the suite's 62.0 % is
      what would pay for it. Measure both sides on all seven tasks — plan
      reachability from a goal query, and precision on the direct suite —
      before shipping either answer.
      **Answer: no — the description names the *goal*, not the actions**, and
      the two candidates were measured against the same baseline on one build
      (62.0 % precision / 100.0 % recall, plan-by-goal 0 of 4 queries).
      *Naming the actions* ("create a project, place component symbols, add
      power and ground symbols for supply rails, label nets, draw wires,
      connect pins, decouple a rail with capacitors") costs 62.0 % → 60.3 %
      precision on the direct suite and, more legibly, **+140 catalog tokens on
      3 of the 7 tasks** — `sch_divider`, `manufacturing_exports` and
      `recovery` each load `apply_plan`'s schema for a task that never needs
      it. *Naming the goal* ("Use it to build a whole schematic design in one
      call") buys the identical reachability — `apply_plan` at rank 2 on
      "build a resistive voltage divider", 0 of 4 goal queries → 1 of 4 — at
      62.0 % precision unchanged and not one catalog token moved on any task.
      The three goal queries still missing are the long ones: clause splitting
      decides per clause, and `apply_plan` is the best answer to none of
      "supply rails", "a wire between them", "a labelled output". So D68 stands
      as measured — the plan path is not *retrievable* from a stated design
      goal — but its edge is now one query wide instead of zero. Shipped: the
      goal sentence, on both tools

### Validation
Precision @8 ≥ 60 % with recall @8 ≥ 98 %, measured by the existing retrieval
probe, before/after on the same build. `bench/runner.py --load-mode search` is
the probe of record — `examples/retrieval_probe.rs` explores offline and
asserts it matches production `search()`, but a config only lands once the
server-side run confirms it.

---

# Phase D — Domain stabilisation — DONE except D.5.3, which is conditional by design

## D.1 — Revisions and optimistic concurrency — DONE

### Tâches
- [x] D.1.1 Content-addressed revisions in `kam-state`
- [x] D.1.2 `base_revisions` refuses a batch whose document moved

### Validation
Silent stale-state write: possible → **refused**, asserted by test.

## D.2 — Transactions, rollback, idempotency — DONE

### Tâches
- [x] D.2.1 `kicad_invoke` batches: snapshot, rollback, idempotency key
- [x] D.2.2 Rollback is file-level, not KiCad's undo stack (D12) — complete for
      the S-expression path, **not** an undo for anything applied over IPC to a
      running KiCad; the IPC path needs `BeginCommit`/`EndCommit` (see D.9)

### Validation
2 033 tk/task, 18/18, partial batch on failure: yes → **rolled back**.

## D.3 — Error catalog — DONE (first pass)

### Tâches
- [x] D.3.1 `TransientClass` (`none`/`network`/`timeout`/`lock`/`state`) +
      `retry_after_ms` instead of a bare `retryable` flag
- [x] D.3.2 Stable io codes, locale-independent messages (E9)
- [x] D.3.3 Structured errors are serialised, not `Debug`-formatted (E11)

### Validation
Error-shape tests; E9 and E11 stay closed.

## D.4 — Stable IDs — DONE

### Objectif
Address items by UUID rather than by path + coordinates, so a reference survives
a move and two agents cannot mean different things by the same address.

### Dépendances
D.1 (revisions). The graph already keys on KiCad's own UUIDs, so the extraction
side exists (`konnect-core::graph`).

### Tâches
- [x] D.4.1 UUID-addressed item handles across the schematic tools
  - [x] D.4.1.1 One resolver, not three. `konnect-sexp::command` already holds
        the real index (`ItemId`, `document_items`, both private); it exposes a
        lookup by UUID, and `tools/mod.rs` carries the handle layer beside
        `find_symbol_instance_block`. The three textual
        `content.find(r#"(uuid "…")"#)` sites — `delete_wire`,
        `batch_delete_wire`, `delete_schematic_items` — move onto it without
        changing what they accept or what they protect.
        Done for the two wire sites; the third (`batch_delete`) stays on the
        textual search *because* of the second clause — it has always accepted
        a UUID nested inside the item it deletes (a sheet pin's own), which the
        direct-child index answers `NotFound` for. That acceptance is now a
        test (`batch_delete_accepts_a_uuid_nested_inside_the_deleted_item`), so
        the next reader migrates it only by deciding to drop the input
  - [x] D.4.1.2 `sch_components`: `uuid` accepted wherever `reference` is —
        the nine tools that take one `reference`. Two resolvers, because the
        file has two worlds: `tools::resolve_component` (byte range, for the
        handlers holding the document text) and a thin
        `resolve_component_reference` that returns `reference` without reading
        anything and only pays for a read on the `uuid` path (INV8)
  - [x] D.4.1.7 A `uuid` that names unit 2 of a multi-unit symbol now edits
        unit 2. `resolve_component_reference` became
        `resolve_component_target`, which resolves to the symbol's *position* —
        in the loaded schematic, among the parsed instances, or as a byte range
        — and nothing redescends by designator afterwards (D81). No
        `by_uuid`/`by_uuid_mut` was added to `cse`: position is what the
        handlers need, and only `remove_at` was missing
  - [x] D.4.1.3 `sch_hierarchy`: `uuid` accepted wherever `sheet_name` is —
        eight tools, plus `source_uuid` beside `duplicate_sheet`'s
        `source_sheet_name`. Cleaner than D.4.1.2 because `cse` already
        addresses sheets by uuid (`by_uuid`, `by_uuid_mut`, `remove_by_uuid`),
        so no address is ever translated into a name — which matters, since
        sheet names are not unique and a test now pins that
  - [x] D.4.1.4 `sch_wiring` / `sch_buses`: `uuid` accepted wherever a point or
        a segment addresses an item; `extract_junctions` starts carrying the
        uuid it currently drops. Four tools take one
        (`split_wire_at_point`, `delete_schematic_net_label`,
        `rotate_schematic_label`, `delete_no_connect`); `sch_buses` has none to
        take one — every tool there creates or reads. The half that makes the
        address usable ships with it: `list_schematic_labels` publishes uuids,
        `add_no_connect` reports the one it created
  - [x] D.4.1.8 No reading tool listed junctions or no-connects, so a
        no-connect's uuid was only ever published by the call that *created*
        it. Resolved by extending a reader rather than adding a tool:
        `get_schematic_layout` takes `include_junctions` and
        `include_no_connects`, both defaulting to false so the summary costs
        what it always did, and reads both through `cse`, which already models
        them with their identity. Its labels now carry uuids too — wires
        already did, and the asymmetry was a trap
  - [x] D.4.1.5 D.4's own validation — the move test — and the docs.
        `crates/konnect-core/tests/uuid_addressing.rs` runs the loop a caller
        actually runs, against `bench/fixtures/divider.kicad_sch` rather than a
        hand-written fixture: list, edit through the published uuid, resolve it
        again. It covers the rename, which is where the two address forms part
        company, and that an edit rewrites no identity but its own.
        `list_schematic_components` had to start publishing uuids for that loop
        to exist at one call (D82). The model is written down in DEV.md,
        including both known gaps
  - [x] D.4.1.6 The plural address forms, left out of D.4.1.2 to keep it one
        unit. Seven tools, and the shape follows each tool's own rather than
        one uniform rule: an address that is an array of strings gets a
        parallel `uuids` array (`batch_get_schematic_pin_locations`,
        `group_components`, `bulk_move_schematic_components`,
        `batch_delete_schematic_components`), and an address that is already an
        object entry gets a `uuid` field inside it
        (`batch_edit_schematic_components`, `batch_rotate_labels`,
        `batch_delete_no_connect`). Both arrays together are the union, an item
        named twice acted on once. `move_labels_by_offset` is deliberately out:
        its `net` selects every label on a net — a selector, not an address
- [x] D.4.2 Keep the existing path+coordinate forms accepted (INV8) — by
      construction rather than by promise: the historical form is evaluated
      first and reads nothing extra, and every migrated tool has a test that
      runs the same operation both ways and compares the documents

### Validation
A tool call that names a UUID still resolves after the item moved; targeted tests
plus one probe on a real project.

## D.5 — Snapshots as first-class handles — DONE

### Objectif
`kicad://snapshot/N` beside `kicad://diff/N` and `kicad://evidence/N`.

### Dépendances
D.2 (snapshots exist internally), E.2 (the handle store and its resource route).

### Tâches
- [x] D.5.1 Issue a handle per snapshot, resolvable over MCP `resources/read`.
      Emitted only when `Snapshot::capture` succeeds — a handle answering for no
      snapshot would be worse than none — and the batch reply gains
      `snapshot_evidence` without renaming a field, since the gateway tests and
      the bench read that shape. The body is a **manifest**, never the
      before-images: roots, file count, and per file its path relative to its
      root, its revision and its size. Rollback stays internal (D12); this is an
      audit artefact (INV3), not a capability, and a relative path keeps the
      caller's filesystem layout out of something a model reads
- [x] D.5.2 An expired handle is not an unknown one (D16), same discrimination as
      the evidence store — literally the same store: `Entry::uri` already builds
      `{scheme}://{kind}/{id}`, so `put("snapshot", …)` produces
      `kicad://snapshot/N` and `high_water` separates evicted from never-issued
      with no change to `kam-evidence` and none to the `resources/*` routes
- [ ] D.5.3 Reconsider the evidence store's 64-entry capacity if a session ever
      needs deeper history. A capturing batch now stores two artefacts instead
      of one, so those entries span half as many batches. Not a defect and not
      worth changing on speculation: the byte budget is nowhere near binding (a
      400-file snapshot is ~44 KiB of manifest against 4 MiB), and no measured
      workload has wanted more than 32 batches of history

### Validation
Round-trip over `resources/read` and presence in `resources/list`, proven
through the stdio protocol (`crates/konnect/tests/protocol_stdio.rs::
a_captured_snapshot_is_a_resolvable_handle`), not by calling the store directly.
Eviction returns the expired shape **on this kind**, not only on the store's own
`diff` fixture: `an_evicted_snapshot_handle_is_expired_not_unknown` fills a
capacity-2 store with three captures and asserts `evidence_expired` for the
first, `unknown_handle` for an id never issued. A failed capture emits nothing.
Gate green including the benchmark; the +18 tokens/task it costs are recorded in
`docs/benchmark.md` and in the V1 criterion above.

## D.6 — Error-catalog completeness, retries, recovery policy — DONE

### Dépendances
D.3.

### Tâches
- [x] D.6.1 Cover the remaining error paths with catalogued codes, by zone,
      lowering D.6.4's ceiling each time. A big-bang conversion of 150-odd
      hand-written messages would be unreviewable, so it went by zone, ranked
      by D.6.4 rather than estimated: **152 → 2**. The 2 left are not a to-do
      list — one condition (`TaskError::ListFull`) reached from two call sites,
      where no catalogued kind is true and inventing one would be a false
      classification. The ceiling comment says so, so a later reader does not
      read the floor as unfinished work.
      - [x] `sch_hierarchy.rs` — 28/28, ceiling 152 → 124. No new kind was
            needed: `InvalidArgument` ×14, `NotFound` ×12, `FileNotFound` ×5.
            That is the useful finding for the rest of D.6.1 — the work is
            classification, not catalogue design. Message text is never
            reworded, only classified: rewriting prose in bulk would drown the
            review and lose detail written by someone who knew the case
      - [x] `pcb_components.rs` — 20 of 25, ceiling 124 → 104, and the five it
            did **not** take are the point. They were first converted to
            `HandlerError`, the variant documented as the catch-all for what
            has not been migrated, which made the count fall while making the
            contract worse: `HandlerError` asserts `TransientClass::None`, and
            these sites include "KiCAD must be running", where starting KiCAD
            and retrying is precisely the fix. Plain text promised nothing;
            the catch-all promises something false. They are back to plain
            text with the obstacle written at each site — `with_ipc` folds an
            unreachable transport, a board mismatch and a business rejection
            into one `String`, so the type that would decide is already gone.
            The scanner now counts a literal `ToolErrorKind::HandlerError` as
            debt too, so the metric cannot be satisfied by moving text into the
            catch-all; `from_anyhow` is not counted, since it classifies from
            the error chain at runtime and reaches the catch-all only when the
            chain carries nothing better
      - [x] `library.rs` + `sch_wiring.rs` — 22 of 31, ceiling 104 → 82, no new
            kind. The 9 left in plain text all give the same reason, which is
            the finding: a helper stringified the error before the call site
            could classify it (`read_lib_table_checked`,
            `resolve_footprint_path`, `resolve_symbol_lib_path`, and the two
            batch paths whose `errors` string mixes "not found" with "not
            parseable"). One genuine exception: duplicate labels at one
            position in `sch_wiring.rs` — valid input, ambiguous world, neither
            an invalid argument nor a missing item, and a new kind for a single
            site was rightly not invented
      - [x] `meta_tools.rs` — 16 of 18, ceiling 71 → 55, no new kind.
            Fifteen are `InvalidArgument` behind one local helper, so the
            file's argument refusals cannot drift into as many shapes as it
            has call sites. Two of them were D.6.5's signature problem in
            miniature — `agent_u32` and `agent_retrieval` answered
            `Result<_, String>`, and now answer `Result<_, CallToolResult>`
            and classify where the field name is still in scope. The task
            errors classify from `kam_state::TaskError`, not from its
            `Display`. The 2 left are one condition reached twice:
            `TaskError::ListFull` is neither a missing item nor a malformed
            argument — the input is well-formed and the task's own state
            refuses it — so `task_error_kind` returns `Option` and that `None`
            is the statement (D76)
      - [x] `sch_components.rs` — 13/13, ceiling 55 → 41. Five of them were
            one sentence in two spellings, so the classification moved into one
            helper and the prose stayed at each site. The zone also paid a
            *catalogue* debt: **D77** adds `MalformedDocument { path, detail }`
            — the gap between four kinds that each nearly fit (`Io`: the read
            succeeded; `FileNotFound`: the file is there; `InvalidArgument`:
            the call is well-formed; `NotFound`: the addressed item is present
            and the document around it is not usable). Added once six sites
            across four files had converged on the shape, which is the bar
      - [x] `integration.rs` — 12/12, ceiling 41 → 29. Seven of them had no
            true kind either: **D78** adds `UpstreamFailed { service, code,
            detail }`. Nothing in a failed JLCPCB download is the caller's
            fault, the filesystem's or KiCAD's, and `code` separates the two
            failures prose cannot — `unreachable` / `server_error` are
            `Network` (waiting is the recovery), `client_error` /
            `unexpected_response` are `None`. 429 files with the 5xx: it is the
            one 4xx that says "later"
      - [x] the smaller files — `sch_batch.rs`, `pcb_board.rs`,
            `pcb_routing.rs`, `sch_wiring.rs`, `project.rs`, `templates.rs`,
            `sch_analysis.rs`, `config.rs`, `verification.rs`,
            `tools/mod.rs` — 27 sites, ceiling 29 → 2. Three things came out of
            it beyond the count: D77 reached the duplicate-label site zone 3
            had left in prose for want of a kind; the two batch paths D.6.5
            named and did not reach are now typed by *counting* their failure
            causes rather than by re-reading their own joined prose, and a
            batch that deleted nothing is classified by the worst failure it
            collected; and `NotFound` gained `candidates` (serialized only when
            non-empty) so `lib_symbol_not_found_error` could stop paying
            `HandlerError` for one structured field
      - [x] D.6.5 Stop throwing the type away at the boundary — done in two
            commits, ceiling 82 → 77 → 71.
            - The IPC half: four toolsets carried a byte-identical `with_ipc`
              returning `Result<T, String>`. It is now typed and catalogued
              once in `tools/ipc_boundary.rs`, and upstream the markers carry
              what the message used to — `TransportUnreachable` splits into
              `NotConfigured` / `DialFailed`, and `BoardNotOpen` is a marker in
              the anyhow chain rather than a bail. Three kinds, each with the
              transient class that is true of it: `IpcUnavailable` is `Network`
              when a dial failed (starting KiCAD makes the same call work) and
              `None` when nothing is configured (D75's false transient),
              `IpcRejected` is `None`, `BoardNotOpen` is `State`. `from_io`
              falls out of it, and `from_anyhow` delegates to it so the two
              cannot disagree on a code
            - The library half: `read_lib_table_checked` →
              `LibTableUnreadable` (keeps the `io::Error`, not its message),
              `resolve_footprint_path` → `FootprintPathError` (four variants;
              the three `NotFound` ones are told apart by `item_kind` —
              "library uri" is fixed in the environment, "library" by
              `register_footprint_library`, "footprint" by naming another),
              `resolve_symbol_lib_path` → `SymbolLibPathError` instead of
              `Option`, which is the one behavioural change: "not registered"
              and "URI does not expand" were both `None`, so the message had to
              name both and the caller could act on neither
            - One site keeps its prose on purpose:
              `board_footprint_sexp`'s malformed `.kicad_mod` — not IO, not a
              missing item, not a malformed argument. `kind()` returns
              `Option<ToolErrorKind>` and that `None` is the statement
- [x] D.6.2 Retry policy driven by `TransientClass` (`state` means reconcile
      first — a blind retry is useless). `mcp::retry::decide` is the single
      rule; `State` and `None` return no retry *and no wait*, so a call site
      cannot ask the policy for a delay it should not honour. The server
      deliberately does not retry on the caller's behalf — what was missing was
      one named rule, not a loop. Audited every retry site in the crate: the
      only real one is `integration.rs::get_with_backoff` (HTTP), which now
      consults the policy before looping; nothing retried a forbidden class
- [x] D.6.3 `FailureMode` on verdicts (`design` / `environment` /
      `configuration` / `manual_review`) + `MANUAL_STEP_REQUIRED` naming the
      exact GUI step — a broken environment and a broken design must drive
      opposite agent loops. **`COULD_NOT_RUN` can never be `design`**, and not
      by convention: the private constructor for that path has no `Design`
      variant to hand, which is INV1's rule expressed in the type system. An
      agent reading `design` on a broken environment would go repair a
      schematic that has nothing wrong with it. `MANUAL_STEP_REQUIRED` is a
      catalogued `ToolErrorKind::ManualStepRequired { tool, step }` — a code an
      agent loop can match on, not a prefix in prose — and `step` is read from
      the capability's own `Limitation::GuiOnlyNoApi` reason, the same string
      the matrix renders, so the two cannot drift. `manual_review` is declared
      and reserved: nothing in `verify()` has grounds to produce it today, and
      the code says so rather than leaving a reader to guess
- [x] D.6.4 Make the debt visible and non-regressive instead of estimated.
      `tests/error_catalog_debt.rs` scans for plain-text error sites, ranks
      them by file, and fails in **both** directions: a new uncatalogued site
      is refused, and a drop demands the ceiling come down — which is how the
      ceiling went 153 → 152 in this very lot

### Validation
Failure-injection cases resolve to the right class and the right agent loop:
missing validator → `environment`, unsupported document type →
`configuration`, real findings → `design`, `PASS` → no mode at all, plus an
exhaustive test that no `could_not_run` path can convert to `design`. Retry
policy is table-driven over all five `TransientClass` values. Gate green
including the benchmark; gateway tokens 2 204 → 2 207, inside the run-to-run
noise (the `toolsets` mode moved −9 with nothing of its own changed).

## D.7 — Event journal / deltas — DONE

### Objectif
`changes_since(rev)`. KiCad has no pub/sub, so this is ours to build.

### Dépendances
D.1 (revisions), E.1 (semantic diff).

### Tâches
- [x] D.7.1 Append-only JSONL run journal with `pre_snapshot_path`,
      `post_snapshot_path`, `rollback_token` per entry. Paths are relative to
      the journal directory and only the files the batch *changed* are imaged —
      the two together are what keep the cost proportional to the change and
      the file free of the caller's filesystem layout (D72). Nothing from the
      journal enters an MCP reply: a `rollback_token` a client could read would
      be an address no tool accepts (D82 read the other way round), and D12
      keeps rollback inside the batch
- [x] D.7.2 `changes_since(rev)` as a **meta-tool**, not a MANIFEST tool: it
      answers about the server's own record, and a domain tool would move
      `CAPABILITY_COVERAGE`'s frozen denominator (D44). `rev` is a revision
      token `kicad_invoke` already publishes (D82). Three answers it must tell
      apart — the document is at `rev` still; it moved and the journal says
      which batches moved it; it moved and *we* did not write it, which is the
      foreign-edit case the revision comparison detects on the spot
- [x] D.7.3 Never advertise push notifications over MCP, pinned by a test
      rather than by nobody having added one: `resources` already ships
      `subscribe: false` / `listChanged: false` (`mcp/server.rs`), and
      `tools.listChanged` stays `true` because it is real and fires — it
      describes *session* state, which is not a disk mutation (D60)

### Validation
A journal replay reconstructs the same semantic diff the batch reported.

**Deliberate substitution, recorded rather than silent:** D.7.2 says "targeted
diffing + file watching" and ships the diffing without the watcher. A watcher
is a background daemon that has to survive a restart to be worth anything, and
the one question it would answer — has this document moved since `rev` — is
already answered on demand by D.1's content-addressed revision, with no state
to keep in sync. D.7.3 is the other half of the argument: a watcher whose
findings may never be pushed has no consumer but the poll that exists anyway.

## D.8 — Operating mode, orthogonal to discovery — DONE

### Objectif
Profile controls *discovery*; mode (`READONLY` / `WRITE` / `MANUFACTURING` /
`EXPERIMENTAL`) controls *execution risk*. Loading a toolset must not grant
permission to mutate.

### Dépendances
F.3 (gateway), `kam-state`.

### Tâches
- [x] D.8.1 Mode held in `kam-state`, enforced at the gateway.
      `kam_state::OperatingMode` (`ReadOnly | Write | Manufacturing |
      Experimental`) + `ModeGuard`, clean-room per INV2: the crate has no idea
      what a tool or an effect is, and the mapping onto "may this call run"
      lives in `konnect-core::capability::mode_allows`, which needs `Effect`.
      Set once at startup from `KONNECT_MODE`; an unrecognised value is a
      startup failure, never a silent fall back to the unrestricted default.
      **D69** — never elevable in-session: the guard's only public mutator is
      `restrict_to`, whose more-restrictive-wins rule makes a less restrictive
      argument a no-op, so no meta-tool exposed to a model can widen what the
      process may do, because no such call exists. Deliberately
      `#[serde(skip)]` on `Config`: a stale `mode: "read-only"` left in a saved
      settings file must not lock a server the operator meant to run writable
- [x] D.8.2 A `read_only` context refuses *any* write tool, by capability class
      rather than by a listed set — the gate reads `capability::tool_effect` /
      `meta_tool_effect`, so a tool added tomorrow is covered by the same
      classification the matrix already renders. Enforced at both execution
      points and nowhere else: `mcp::handler::dispatch_tool` (direct calls and
      meta-tools) and `handle_kicad_invoke` (once per batch entry).
      `kicad_invoke` itself is exempt at the outer dispatch on purpose — its
      `Write` label in `META_TOOL_EFFECTS` is a coverage-audit artefact, not a
      bound on its entries, and enforcing it there would refuse an all-reads
      batch a `ReadOnly` caller is allowed to run. `kicad_agent` is `Write`, so
      the agent loop is never reached under `ReadOnly` and `apply_plan`'s
      internal path needs no second gate. New `ToolErrorKind::
      WriteRefusedByMode`, `TransientClass::None`: retrying the identical call
      can never help
- [x] D.8.3 `MANUFACTURING` is a **design freeze**, and `EXPERIMENTAL` is an
      alias of `WRITE` that says so (user decision, 2026-08-20). The rule is
      implementable because a fabrication output *does* write to disk — the
      distinction is not whether a call writes but *what* it writes, so a
      `WriteTarget { DesignDocument, Derived }` sits orthogonal to `Effect`
      rather than replacing it. `Manufacturing` refuses a `Write` whose target
      is a source document and allows a derived one, which makes the scale
      linear at last: `ReadOnly < Manufacturing < Write`, with `restrict_to`
      still unable to elevate (D69). The fail-safe is `DesignDocument`, the
      mirror of D58's `Write` fail-safe: a tool added tomorrow is refused under
      `Manufacturing` rather than allowed by accident. `EXPERIMENTAL` is given
      no rule on purpose — no use case for one exists anywhere in the repo, and
      inventing one to justify a name reads the rule backwards — so it is
      documented as a deliberate alias and pinned by a test rather than left as
      a promise (D89)

### Validation
D.8.3 is proved in the same shape, through `McpHandler::handle_message`: under
`MANUFACTURING` a design-document write is refused with the working directory's
bytes identical before and after, a `Derived` write succeeds (the positive
control, without which the refusal proves nothing), a `kicad_invoke` entry is
gated exactly like a direct call, and `EXPERIMENTAL` runs the very tool
`MANUFACTURING` refused. Table-driven in `capability::tests`: no `export_*` tool
is a `DesignDocument` write and no name in the derived list is dead. The
matrix's `effect` column is deliberately untouched — `bench/capabilities.py`
keeps only exact `read`/`write` values, so the new fact went into a column of
its own; the bench's table is unchanged at 215 entries.

A write tool called under `READONLY` is refused before the first mutation (INV4)
— proven end to end through `McpHandler::handle_message`, not by calling a
handler directly, with the work directory's bytes identical before and after the
refusal, and a positive control in `Write` mode asserting the same call *does*
mutate the file (otherwise the refusal would prove nothing).
`crates/konnect-core/tests/mode_gate.rs`, plus table-driven coverage of every
`MANIFEST` and `META_TOOL_EFFECTS` entry in `capability::tests`. Gate green
including the benchmark: gateway 21/21, `MCP_CALLS` median 4, 2 186 external
tokens, retrieval 62.0 % / 100 % — unchanged, which is what a `Write` default
has to mean.

## D.9 — Serialised IPC command queue — DONE

### Objectif
KiCad's API server is single-threaded on the UI thread. The lock matters less
than the guarantee that a retry never double-applies.

### Dépendances
D.3 (idempotency keys already exist), PCB path only. No longer gated on J.3:
J.3.4 answered the GUI-session question and the `live-ipc` job is green on a
GitHub runner, so this lot's validation has somewhere to run.

### Tâches
- [x] D.9.1 A FIFO queue per IPC address, each behind its own worker thread
      (`tools/ipc_queue.rs`), with `with_ipc` submitting **synchronously** so the
      order is the order callers were invoked and not the order their futures
      were polled. Neither a retry nor a timeout was added, and both refusals are
      the decision rather than an omission (D87). The concrete failure it closes
      is `place_footprint`'s four-command read-modify-write, whose "does this
      reference already exist" check two concurrent callers could both pass
- [x] D.9.2 Atomicity on the IPC path, by two remedies rather than one (D88).
      Of the three multi-mutation sites, only `modify_track` needed a commit —
      `replace_track` wraps its `delete_track` + create in `run_commit`, because
      a delete and a create cannot be merged and a failing second half destroyed
      a track and put nothing back. The L-bend and the differential pair are
      mutations of the *same* nature, so `add_tracks(&[TrackSpec])` sends them as
      one `CreateItems` — atomic by construction, one `get_nets` for the batch
      instead of one per track, and an unknown net name fails before anything is
      sent. Every other IPC site sends exactly one mutation and was deliberately
      left alone

### Validation
Concurrent callers cannot interleave: proved by `ipc_queue`'s own tests — eight
concurrent jobs observe a maximum concurrency of 1, jobs run in submission
order, a panicking job does not wedge the queue, and two distinct addresses do
reach 2. A replayed idempotency key applying once stays D.3's ledger's job;
D.9.1 deliberately adds no second mechanism for it (D87). Atomicity is proved
against the mock KiCAD by the sequence of commands actually sent:
`BeginCommit → DeleteItems → CreateItems → EndCommit(CmaCommit)` for a
replacement, `CmaDrop` and never `CmaCommit` when the create half fails, one
`CreateItems` and one `GetNets` for a two-track batch, and no `CreateItems` at
all when one of the batch's net names is unknown.

---

# Phase E — World model, task state, evidence — DONE

## E.1 — Semantic diff — DONE

### Tâches
- [x] E.1.1 `kam-evidence::diff` matches items by stable key, format-agnostic on
      purpose (D15) — a second document format costs an extractor, not an engine
- [x] E.1.2 KiCAD extractors in `konnect-core::evidence`, keyed on KiCad's UUIDs
- [x] E.1.3 A document is itself an item, so a creation reads `document +3`
      instead of "no design change" (D14)

### Validation
`bench/probes/semantic_diff.yaml` on a real project; 2 158 tk/task.

**Recorded limit:** the diff reports objects, not connectivity. A schematic has
no netlist in the document, and deriving one would re-implement the connectivity
that E7 already shows disagreeing with `kicad-cli`.

## E.2 — Handles, resources, evidence packs — DONE

### Tâches
- [x] E.2.1 Bounded handle store; `kicad://diff/N` and `kicad://evidence/N`
- [x] E.2.2 Resolve over MCP `resources/read`
- [x] E.2.3 An expired handle is distinguished from an unknown one (D16)

### Validation
Round-trip over `resources/read`; +14 tk/task, +0 startup.

## E.3 — Independent verification — DONE

### Tâches
- [x] E.3.1 `kicad_invoke(verify:)` runs `kicad-cli` ERC/DRC (INV1)
- [x] E.3.2 Findings identified by `validator + rule + location` hashed to a
      12-hex id, never by prose (D19); identical findings get an ordinal
- [x] E.3.3 Verdicts cached against the content revision they describe (D18); the
      first verification of a session reports `baseline: "unknown"` rather than
      implying zero
- [x] E.3.4 `verify` is opt-in and a typo is refused (D17) — 7 ms against
      ~1 100 ms per batch is why it is opt-in, and silence is why a misspelling
      cannot be tolerated

### Validation
`bench/probes/validators.yaml`: batch 1 `errors: 4, baseline: unknown`, batch 2
`errors: 2, fixed: 2`.

**Recorded limit:** `verify` only checks documents the batch changed. A read-only
batch gets no verdict; a bare check is still `run_erc`.

## E.4 — Task State Manager — DONE

### Tâches
- [x] E.4.1 `kam-state::task`: objective, constraints, verified facts, failed
      attempts, evidence handles, held outside any model's context
- [x] E.4.2 The ACTIVE TASK anchor is **rendered** from the record on every read,
      never stored (D21) — a cached anchor could disagree with what it describes
- [x] E.4.3 Hard constraints are refused at the bound rather than evicted
- [x] E.4.4 Four tools as a toolset, not gateway verbs (D20) — **0** startup
      tokens, asserted by a stdio test on both halves
- [x] E.4.5 `kicad_invoke(task_id=…)` files revisions, evidence and failures by
      itself; an unknown `task_id` does not fail an already-applied batch

### Validation
2 175 tk/task, 18/18; startup +36, all of it the `task_id` property.

## E.5 — ProjectGraph — DONE

### Tâches
- [x] E.5.1 `kam-graph`: indexed store + filter/neighbour/count query language
- [x] E.5.2 `konnect-core::graph`: KiCAD extractors + a cache keyed on the
      content revision, so a query on an unmoved document rebuilds nothing
- [x] E.5.3 `graph_query` / `graph_neighbors` / `graph_stats` as a toolset — 0
      startup tokens, asserted
- [x] E.5.4 `fields` projection (`compact` default) — unfiltered 525 → 340 tk

### Validation
18/18 at 2 174 tk/task, startup unchanged, 752 tests at the time.

**Recorded limit (D30):** an unfiltered `graph_query` still costs 340 tk against
310 for the plain dump. The graph wins on filtering (109 tk against 310) and on
adjacency, not on serialisation, and its description says so. Shortening the key
was rejected: the key is the address `graph_neighbors` takes.

## E.6 — Context Manager — DONE

### Objectif
`crates/kam-context`: budgets, compaction, retrieval. The attention half already
exists as the anchor (E.4.2); the budget half does not exist at all.

### Dépendances
E.4, and the local-token accounting from H.2 (`Usage`, reasoning split).

### Tâches
- [x] E.6.1 Token budgets per context, measured against real local runs
- [x] E.6.2 Compaction that preserves the objective (already true of the anchor)
      and the verified facts
- [x] E.6.3 Retrieval into the context, budget-aware

### Validation
A compaction cycle on a real session loses no hard constraint and no verified
fact; measured against a local run rather than asserted.

---

# Phase G — Plan IR and deterministic executor — DONE

## G.1 — The IR and the compiler

### Tâches
- [x] G.1.1 `kam-plan`: `ir`, `refs` (`${op.field}`), `compile`, `execute` as a
      state machine the async host drives (no runtime in the crate)
- [x] G.1.2 A plan is refused at compile time, never discovered at step 4 (D22);
      unknown and forward references are separate errors because one is fixed by
      renaming and the other by reordering
- [x] G.1.3 What the compiler deliberately does not check: whether a referenced
      *field* will exist at run time — that stays a step failure with the
      reference named

### Validation
46 tests in `kam-plan`.

## G.2 — The KiCAD operation library

### Tâches
- [x] G.2.1 `call`, `place`, `power`, `label`, `wire`, `connect`, `decouple`
- [x] G.2.2 Every emitted coordinate is snapped before it reaches a tool, which
      makes E6 unreachable inside a plan
- [x] G.2.3 A coordinate must be a number, never a `${ref}` (D23) — the snap
      happens at compile time and the reference resolves at run time
- [x] G.2.4 `decouple` places and wires; it has no opinion on whether the design
      is right, and says so in its own documentation (D24)

### Validation
E2E against real `kicad-cli`: the off-grid input that produced six ERC errors
produces none.

## G.3 — The plan toolset

### Tâches
- [x] G.3.1 `preview_plan` (compile, list, change nothing) and `apply_plan`
- [x] G.3.2 Runs **inside** `kicad_invoke` (D25), inheriting snapshot, rollback,
      `base_revisions`, diff, `verify` and task filing; each inner step is written
      to the call log by hand, since `apply_plan` cannot use the `tool!` macro

### Validation
`bench/plan_cost.py`, same design built both ways, void unless the semantic diff
and the ERC verdict match: divider 2 180 → **1 124** tk (−48.4 %), decoupling bank
2 265 → **882** tk (−61.1 %). Golden suite unchanged, 0 startup tokens.

## G.4 — Plan-owned postconditions

### Tâches
- [x] G.4.1 `erc` / `drc` = no new finding by stable id; `erc_clean` / `drc_clean`
      = zero errors, absolutely (D29 — one name would have been ambiguous)
- [x] G.4.2 An unrecognised validator name is refused in `build()` (INV4)
- [x] G.4.3 A failed postcondition returns `is_error`, so the atomic
      `kicad_invoke` rolls the plan back (D28); the plan never chooses what clean
      means — the verdict is `kicad-cli`'s
- [x] G.4.4 `Postcondition` lives in `konnect-core::evidence::validators`, keeping
      `kam-plan` ignorant of KiCAD (INV2)

### Validation
Measured on the divider: no validators 48 ms, `erc_clean` 1 114 ms, `erc`
2 182 ms; the reply is byte-identical, so a passing postcondition costs no tokens.
E2E run against real `kicad-cli`, not merely written (E12's rule).

---

# Phase H — Local AI runtime — DONE

## H.1 — Backend and shortlist — DONE

### Objectif
Answer the backend question from primary sources and refuse to pick a model by
reputation.

### Tâches
- [x] H.1.1 Backend = OpenAI-compatible HTTP (D31). `vLLM` has no native Windows
      support; `llama.cpp` needs a source build for Blackwell `sm_120`; LM Studio
      wraps `llama.cpp` and exposes tools + `response_format: json_schema`
- [x] H.1.2 Shortlist `Qwen3.5-9B` and `openai/gpt-oss-20b`, both Apache-2.0 with
      documented tool calling; `Qwen3.5-27B` ruled out at ~16.5 GB before KV cache
- [x] H.1.3 Recorded so it is not re-asked: **there is no EDA-specialised
      open-weight model.** The electronics competence stays in the deterministic
      engine and the validators

### Validation
`docs/local-agents.md`; every claim traced to a primary source.

## H.2 — The seam, `crates/kam-llm` — DONE

### Tâches
- [x] H.2.1 `provider::Provider` — one `async fn complete`, object-safe so the
      router can hold `Box<dyn Provider>` and a backend swap is a config change
- [x] H.2.2 Vocabulary shaped like MCP's own tool definitions, so a tool catalogue
      crosses untranslated
- [x] H.2.3 `openai_compat` refuses a non-loopback base URL in `new`; the override
      is a separate named constructor (INV9)
- [x] H.2.4 `usage::Usage` so the local-token KPIs are a field at the call site;
      a backend reporting no counts leaves them at 0 rather than estimating
- [x] H.2.5 `hardware::probe` never panics and never guesses — `nvidia-smi` first,
      a Windows fallback that reports names and **not** VRAM
      (`Win32_VideoController.AdapterRAM` misreports modern cards), a backend
      probe that checks `PATH` and opens no socket
- [x] H.2.6 `ReasoningEffort` on `CompletionRequest`, unset = absent field

### Validation
19 tests in the crate; it ranks, chooses and routes nothing.

## H.3 — The oracle, `bench/model_fit.py` — DONE

### Objectif
Grade a local model's plan by compiling it through the real server, never by
reading it.

### Dépendances
G.3 (`apply_plan`), C.1 (`runner.py`).

### Tâches
- [x] H.3.1 0–3 ladder: 0 not schema-valid JSON, 1 `preview_plan` refuses,
      2 applies but breaks an invariant or the ERC budget, 3 applies clean
- [x] H.3.2 `check_assertion` and `GatewayClient` **imported** from
      `bench/runner.py`, never reimplemented — a harness with its own compiler
      would refuse a plan for a reason it invented
- [x] H.3.3 Prompt = four blocks in fixed order; the schema and operation-library
      blocks are pulled from `kicad_describe(["apply_plan"])` against the running
      server, so a copied schema cannot drift
- [x] H.3.4 Four tasks: `01_divider`, `02_ldo`, `03_decoupling_bank`,
      `04_reference_heavy`
- [x] H.3.5 `--repair N`: a repair round gets its own previous plan and the
      server's **verbatim** refusal, nothing else (D34); the work directory is
      emptied between rounds and the paths stay the same
- [x] H.3.6 `select_best_round` — a repair that lowers the grade is discarded, not
      recorded; ties keep the earlier round; tokens and `llm_calls` stay summed
      over every round performed

### Validation
Selftest, 8 rungs, three of them proving round selection with no model involved.
The stable prefix is byte-identical across all tasks and hint levels — the
property a prefix cache needs.

## H.4 — Make the measurement measure the model, not the harness — DONE

### Objectif
Every run in this phase first measured one of our own defects. Walk the ladder
from the bottom until the residue is the model's.

### Dépendances
H.3.

### Tâches
- [x] H.4.1 Item shapes documented in the operation library (E14)
- [x] H.4.2 A failed plan must not report success, and the oracle must not read a
      failed check as a passing one (E15)
- [x] H.4.3 One placeholder notation, not two a character apart (E16)
- [x] H.4.4 Every scalar carries a type; `create{path,name}` is an operation
      because three independent failure shapes asked for it (E17, D32)
- [x] H.4.5 Accept the reference spellings that have exactly one meaning
      (E18, E19 — the source of INV8)
- [x] H.4.6 A symbol error names candidates (E21)
- [x] H.4.7 `finish_reason` + `reasoning_tokens` recorded; `truncated` is a sixth
      outcome beside the ladder, never a renumbered grade (E20)
- [x] H.4.8 `reasoning_effort` recorded on both sides — a setting the benchmark
      can select and the runtime cannot send makes the measurement unusable (E22)
- [x] H.4.9 `loaded_context_length` recorded per run, after a `high` run graded
      0/60 inside an 8 192-token window it overran 51 times (E23)
- [x] H.4.10 Optional `rollback_policy` spellings that name the absence of a
      choice, and a `schematic` inferred when exactly one candidate exists (E24)
- [x] H.4.11 Cache the symbol library index — a failed lookup cost 7.2 s and
      nothing cached it (E26)

### Validation
Compile rate 6/60 → 54/60 across the run; E24 alone 34/60 → 54/60 at Fisher exact
**p = 0.0001**, `LLM_CALLS_PER_SUCCESSFUL_TASK` 10.0 → 5.5. E26: failed lookup
7.2 s → 43 ms warm / 1 642 ms cold, suite `WALL_CLOCK_P95` back to 890 ms.
`gate.ps1 -Bench`: 815 tests, 18/18, startup unchanged.

**The general result is D37, and it governs the rest of the phase: before
attributing a number to a model, check that the failures are not ours.** The
cheapest place to look is the failure histogram — one refusal string repeated is
ours, a spread across many is the model's.

## H.5 — Measurement runs — DONE

### Objectif
Two models with valid numbers, measured on the same build in the same declared
window, before any threshold is fitted to either.

### Dépendances
H.4 (a run before its defects are fixed measures us, not the model).

### Tâches
- [x] H.5.1 `qwen3.5-9b` measured across the E14–E21 ladder
- [x] H.5.2 `gpt-oss-20b` measured at effort unset / `medium` / `high`, contexts
      8k and 32k, and again on the E24 build
- [x] H.5.3 Re-measure `qwen3.5-9b` on the current build in a **declared 32 768
      window**. Its E24-build run is confounded — its baseline ran in a window
      nothing recorded, and the model's behaviour moved with the window (output
      tokens 122 600 → 460 054). The two are not a before/after pair. Done on the
      E26 build, and `gpt-oss-20b` `medium` re-run beside it so the pair sits on
      one build rather than straddling E24 and E26
- [x] H.5.4 Re-run the `--strict-json` comparison, now that `finish_reason` can
      state the mechanism instead of leaving it inferred (D33 decided the setting
      on outcome counts alone; it stays **off** until a run says otherwise). Run
      on the chosen model on the E26 build: no difference anywhere it could
      matter, `invalid_json` 0/60 both ways, `finish_reason: stop` on all 120
      attempts. It stays off

### Validation
A committed `bench/results/model-fit-*.json` per run carrying
`loaded_context_length` and `reasoning_effort`, compared on the compile rate and
on grade 3 with Fisher exact. Headline table: `docs/benchmark.md` § Model fit.

**Standing results** (detail in `docs/benchmark.md`, do not restate elsewhere):
the chosen local model is `gpt-oss-20b`, `medium`, ctx 32 768, one-shot — 16/60 at
grade 3, 53/60 compiling, 3.75 LLM calls per success on the E27 build (12/60,
54/60 and 5.0 on the E26 build the model choice was made on). `high` is
dominated by `medium` at 2.8× the cost. Deliberation is 92–97 % of local output
tokens, so any budget reading only the answer is wrong by more than 10×. Against
`qwen3.5-9b` measured on the same build in the same window, the 20B reaches grade
3 four times as often (12/60 vs 3/60, p = 0.0246) at half the output tokens; the
compile-rate difference is not significant (54/60 vs 49/60, p = 0.295). The
earlier verdict — no success difference, 9B compiling better — came from a pair
that straddled two builds.

## H.6 — The router — DONE

### Objectif
`NO_LLM | SMALL | MEDIUM | LARGE | ESCALATE`, with thresholds fitted to measured
data rather than to n = 60 noise. The fitting was done (H.6.2) and the data
answered with three tiers: `NO_LLM | LOCAL | ESCALATE`. The middle rungs are not
postponed, they are unmeasurable — no second local model is cheaper per success
and no self-repair round converts a failure.

### Dépendances
H.5.3 — done, and it removes one of the two tiers: on one build the 9B costs more
per success than the 20B (D38), so there is no cheap tier to route *to*. What is
left is D37's point: routing between *no LLM* and an LLM buys the whole call.

### Tâches
- [x] H.6.1 **NO_LLM first** — extend the deterministic operation library wherever
      a measurement shows an LLM call can be removed entirely. The candidate came
      from E26's own residue as required (E25 had already exhausted the refusal
      strings): 16 of 60 attempts failed to apply on a `lib_id` that named
      exactly one installed symbol through a library that does not exist.
      `canonical_lib_id` rewrites those two shapes — invented library, power
      polarity sign — and only when the installed index admits exactly one
      answer. E27: `not_applied` 16/60 → 5/60 (p = 0.0148),
      `LLM_CALLS_PER_SUCCESSFUL_TASK` 5.0 → 3.75
- [x] H.6.2 Tiers and escalation thresholds, each traceable to a measured number.
      The answer the measurements give is **three tiers, not five**:
      `NO_LLM` (H.6.1: `not_applied` 16/60 → 5/60, p = 0.0148),
      one local model (`gpt-oss-20b` at `medium`, D38: 12/60 vs the 9B's 3/60,
      p = 0.0246, at half the output tokens), then `ESCALATE` on the first
      failure of any kind (D35: one repair round converted 0 of 58 and pushed 11
      down the ladder, so no rung sits between the local model and escalation).
      `SMALL`/`MEDIUM`/`LARGE` collapse because no second local model is cheaper
      per success. E27's residue was replayed violation by violation
      (`bench/erc_residue.py`, 39 attempts, all reproducing their graded count)
      and holds no further `NO_LLM` candidate: 139 violations in three classes,
      largest single-rule ceiling 2/60 (p ≈ 0.5)
- [x] H.6.3 Direct mode / Agent mode split at the gateway is an explicit caller
      choice, not a heuristic or server-wide mode. Direct is the existing
      `kicad_describe` / `kicad_invoke` path and never starts an LLM. H.7.1 owns
      a distinct Agent entry point; its `ESCALATE` result returns failure and
      evidence to the caller and never silently contacts an external model
- [x] H.6.4 Evaluate `connect` naming a single-pin symbol while omitting `pin1`.
      Decision: do not build it from E27's 2/60 signal, which is at the noise
      floor. Reopen only if a later run raises it, or alongside a change already
      touching that path
- [x] H.6.5 Fit the geometry contract before adding an agent that composes
      prompts. E28 kept only pin offsets and derived coordinates: 3/20 grade 3,
      all on the decoupling macro, indistinguishable from E27's 7/40 without
      full hints (two-sided p = 1.0) and below `full`'s 9/20 in the pre-declared
      direction (one-sided p = 0.0412; two-sided p = 0.0824). The router must
      retrieve task-specific electrical and Plan IR constraints with geometry;
      the small sample does not identify one sentence as the mechanism

### Validation
`LLM_CALLS_PER_SUCCESSFUL_TASK` and success rate measured with the router on and
off, same tasks, same build, same declared window. For H.6.2 the on/off pair is
E26 vs E27 for the `NO_LLM` boundary; the other two tier decisions are settled by
D38 and D35, each a measured comparison rather than a router setting. H.6.5 is
E28's `geometry` arm against E27's same-model, same-window prompt arms.

## H.7 — Local agent runtime — DONE

### Objectif
Supervisor / schematic / pcb / verification agents over the router.

### Dépendances
H.6, E.6 (budgets), E.4 (task state).

### Tâches
- [x] H.7.1 Supervisor loop driven by task state, not by conversation
- [x] H.7.2 Verification agent whose verdict is `kicad-cli`'s (INV1)
- [x] H.7.3 End-to-end Agent task on the fitted local profile, with no external
      model call and deterministic verification evidence. The `model_divider`
      golden task completed on its first recorded attempt: 8/8 deterministic
      steps, ERC PASS with 0 errors/0 warnings, one local call and zero external
      calls (`agent-e2e-gpt-oss-20b-medium-h7.3b.json`)

### Validation
An end-to-end task completed with no external model call, measured against the
same golden tasks.

---

# Phase I — Custom KiCad gate — TODO (default: NO)

## I.1 — Re-evaluate at KiCad 11

### Objectif
The one blocker that would justify forking KiCad — live schematic IPC — is being
solved upstream for KiCad 11. Default position stays **do not fork** (D3).

### Dépendances
KiCad 11 / `kicad-python` 0.8.0 / `kicad-cli api-server` being available here.

### Tâches
- [ ] I.1.1 Re-run the ground-truth check against KiCad 11 sources
- [ ] I.1.2 Decide: keep the S-expression engine, or move the schematic path to
      IPC. Only a measured blocker that survives KiCad 11 reopens the fork option

### Validation
A written decision with the same evidence standard as D3, or the gate stays shut.

---

# Phase J — Scope expansion — DONE

## J.1 — Close E7 — DONE

### Objectif
Konnect's in-process connectivity analysis disagrees with `kicad-cli` ERC — it
has returned `single_pin_net_count: 0` while `kicad-cli` found six unconnected
pins. The **disclosure** is closed (fifteen tools carry the advisory suffix at the
call site, from the same manifest the matrix renders, INV7); the defect is not.

### Dépendances
None.

### Tâches
- [x] J.1.1 Reproduce the disagreement as a committed probe. Three isolated
      `Device:R` symbols produce 0 in-process single-pin nets versus 6
      `pin_not_connected` findings from KiCad 10.0.3 ERC; the ignored probe
      re-runs both sources when `KICAD_CLI` is set
- [x] J.1.2 Replace label-frequency counting with pin-aware analysis and narrow
      the public claim to pins with no wire/label and no explicit `no_connect`
- [x] J.1.3 Keep the advisory suffix: the reproduced case is now 6 == 6, but
      the implementation remains intentionally `PARTIAL`; the generated matrix
      and suffix/manifest equality test pass

### Validation
The probe's in-process answer equals `kicad-cli`'s on the case that fails today,
and the suffix/manifest equality test still passes.

## J.2 — Raise capability coverage — DONE

### Dépendances
F.4 (the matrix is the instrument).

### Tâches
- [x] J.2.1 Define the coverage comparison target the V1 criterion needs — the
      187 tools the baseline registers at `5cd6454`, frozen in
      `capability::baseline`, scored on both sides by the same scanner; met only
      when strictly ahead *and* nothing the baseline proved is lost. Measured
      **22.6 % → 29.6 %** on a denominator of 186, 0 regressions, re-derived
      from `git archive` in the default gate
- [x] J.2.2 Fill the highest-value gaps — `MISSING` names buses, a standalone
      drill export, IPC-D-356, and the stackup write KiCad 10 declares and does
      not implement
  - [x] J.2.2.1 The two `kicad-cli` gaps: `export_drill` exposes format, units,
        origin, separate PTH/NPTH and the map; `export_netlist(format: "ipc")`
        routes to `pcb export ipcd356` instead of sending an invalid
        `sch export netlist --format`. Both `MISSING` rows are gone. The live
        probe also fixed a real defect: `--output` is a directory, and the two
        existing callers passed `<dir>/drill.drl`, so KiCAD made a *directory*
        of that name — `export_manufacturing_package` reported a file path that
        was not a file
  - [x] J.2.2.2 Buses — `sch_buses` models bus segments, entries and aliases in
        the engine and exposes `add_bus`, `add_bus_entry`, `add_bus_alias`,
        `list_buses`, `expand_bus`. KiCAD's netlist confirms the vector
        expansion (`bus_live`). The probe also found a defect that predates
        buses: KiCAD 10 refuses a label whose `at` has no angle, and the engine
        wrote `(at x y)` — every label type was affected, and the tools only
        escaped it by calling `set_rotation` afterwards
  - [x] J.2.2.3 Stackup write — confirmed and pinned rather than written down:
        KiCad 10's vendored board protos mark `UpdateBoardStackup`
        '**not yet implemented**', and `konnect-ipc`'s
        `stackup_write_is_unimplemented` test fails if that ever changes. Stays
        `GUI_ONLY_NO_API` and out of the denominator
- [x] J.2.3 Prove the tools that have no test that runs. 126 of 202 at the last
      regeneration; 19 `ipc`, 3 `process` and 4 `ipc→sexpr` of those need a live
      KiCAD and stay `gated` until J.3 answers the GUI-session question, so the
      reachable target is the ~100 that run against files, `kicad-cli` or
      nothing. Ordered by size, largest first — each is one commit. **Done: 126
      untested became 26**, and the 26 are the `ipc`/`process` tools waiting on
      J.3 plus the handful whose only honest proof is `gated`
  - [x] J.2.3.1 `nets` and `wires` — `tests/nets_and_wires.rs` builds a circuit
        with the writers and questions every reader about it, through the
        router by name. `get_nets_list` stays `NOT_TESTED`: it is `ipc`, and
        proving it by its own "KiCAD must be running" error would be the claim
        the matrix exists to prevent. `tests/harness/` is the shared rig
  - [x] J.2.3.2 `symbols` and `schematic` — `tests/symbols_and_schematic.rs`.
        `annotate_schematic` and `get_schematic_view` are `cli` and wait for
        J.2.3.7. Three defects found by writing the tests, two fixed here:
        `edit_schematic_component` applied `new_reference` first, which made the
        symbol unfindable and failed every other field in the same call; and a
        rename never reached the `instances` block, so `kicad-cli` kept
        exporting the old designator while the tool reported success (live
        probe). The third, `move_connected` not stretching wires, is recorded
        below rather than hidden
  - [x] J.2.3.3 `config` and `rules` — `tests/config_and_rules.rs`. The
        user-scoped config is a real file in the user's profile, so `APPDATA` /
        `HOME` is redirected into a tempdir under a mutex; the tests assert the
        behaviour that matters at two scopes — the project scope wins the merge,
        and a project rule does not leak into another project
  - [x] J.2.3.4 `review` — `tests/design_review.rs`. Each audit is checked for
        the contrast that makes it worth anything: it finds what it exists to
        find, and stays quiet when there is nothing. The advice itself is never
        asserted. The coverage percentage does not move and should not: all six
        are `HEURISTIC`, so they read `PARTIAL` rather than `SUPPORTED` however
        well tested they are — 78 untested tools became 72
  - [x] J.2.3.5 `footprints` and `libraries` — `tests/libraries_and_footprints.rs`
        builds its own `.pretty` and `.kicad_sym` with `create_footprint` /
        `create_symbol` and then registers, lists, reads and edits *that*, so no
        installed KiCAD is needed. `search_footprints` searches the installed
        libraries by design and stays `#[ignore]`d/`gated` rather than faked
  - [x] J.2.3.6 `labels`, `stackup`, `zones`, `pcb` and `templates` —
        `tests/board_and_labels.rs`. The four `ipc→sexpr` board tools fall back
        to the file engine with no KiCAD listening, so they are testable; the
        `ipc` `refill_zones` is not and waits for J.3. Found and fixed:
        `get_layer_list` searched `find_all("")` for entries whose head is the
        layer id, so it returned an empty list on every board, and `add_layer`
        picked a free id from that same empty set
  - [x] J.2.3.7 the thirteen `cli` tools — `tests/cli_tools.rs` covers each
        twice: a test that runs everywhere pins what the server decides before
        spawning (required arguments, rejected formats, a closed severity set,
        the clamped render size), and an `#[ignore]`d live probe checks the file
        `kicad-cli` actually writes. The live probes use a blank board, not
        `test.kicad_pcb`: that fixture is a KiCad 8 file and KiCad 10 refuses to
        load it
  - [x] J.2.3.8 `sourcing`, `datasheet`, cost/DFM and the last file-engine
        strays — `tests/sourcing_and_manufacturing.rs`. A third party is not a
        test dependency, so what is asserted is what each tool does when it is
        absent: "no database" must never read as "nothing found". The download
        and the `kicad-cli` snapshot are `#[ignore]`d

### Validation
`docs/capability-matrix.md` regenerated; the percentage moves for the right
reason (a test that runs, not a denominator change).

## J.2.4 — Defects the coverage work surfaced — DONE

### Objectif
Writing the tests for J.2.3 turned up tools that work differently from what
they promise. The promises are corrected as they are found; these are the ones
whose fix is real work.

### Dépendances
None.

### Tâches
- [x] J.2.4.1 `edit_schematic_component` could not set a field the symbol has no
      property for — `footprint` on a symbol without one came back "'R2' has no
      'Footprint' property", which is the commonest edit after placement. A
      missing property is now created, in the same shape
      `add_component_annotation` writes, and setting it again edits it rather
      than adding a second
- [x] J.2.4.2 `move_connected` drags the wire ends that were on the moved pins,
      matched per pin number so a rotation still lands each wire on its own pin.
      Reports `wire_ends_dragged`; the `PARTIAL` limitation is retired and the
      description says what it now does
- [x] J.2.4.3 `download_jlcpcb_database` could not fetch anything: its source,
      `https://bouni.github.io/kicad-jlcpcb-tools/jlcpcb_parts.db`, returned HTTP
      404 (checked 2026-08-17). The host had not moved — the *shape* of the
      artifact had: upstream publishes each library as one deflate archive split
      into 80 MB chunks, `<name>.db.zip.001` upwards, with a plain-text manifest
      holding the chunk count. Four libraries exist, from `basic-preferred`
      (~2 MB) to `all-parts` (several GB), so `library` selects one and the
      default is the small one. The tool now reads the manifest, concatenates the
      chunks, inflates, proves the result is really the parts database, and only
      then renames it into place; a failure at any step leaves nothing behind.
      The `GAP` is retired
- [x] J.2.4.4 the JLCPCB query tools were querying a schema no published
      database has ever had — `SELECT LCSC, MFR_Part, ... FROM components` with a
      numeric `Price` — while the published file holds an FTS5 `parts` table with
      quoted column names (`"LCSC Part"`, `"MFR.Part"`, `"Library Type"`,
      `"First Category"`), a `Price` that is a tier *string*
      (`1-199:0.018,200-:0.015`) and a text `Stock`. Nothing caught it because the
      only fixture was one that invented the `components` schema, and every other
      probe asserted the absent-database path. All four tools now speak the
      published schema; `price` is the parsed quantity-1 unit price with the raw
      tiers alongside, cheapest-first ordering and `max_price_usd` are applied to
      that parsed price rather than to a string, and `category` filters the two
      columns that actually carry it. `download_jlcpcb_database` records which
      library it fetched, so a search that finds nothing can say whether it
      searched 1 600 parts or the whole catalogue

### Validation
Each fix lands with the test that proved the defect, and the `PARTIAL` row it
retires disappears from the generated matrix. For J.2.4.3/J.2.4.4 the fixture is
the published DDL verbatim and the archive is served from a loopback server, so
the download path and the schema are proved without a third party; one
`#[ignore]`d probe fetches the real `basic-preferred` library and is the check to
run when a download starts failing.

## J.3 — PCB E2E without a GUI session — DONE, and green in CI

### Objectif
Open question, and it currently blocks PCB benchmark coverage entirely: does
KiCad 10.0.3 on Windows expose `KICAD_API_SOCKET` reliably enough for unattended
E2E, or does the PCB path need a live GUI session?

### Dépendances
None. Blocks D.9's validation and most of J.2's PCB half.

### Tâches
- [x] J.3.1 Determine it by experiment, not by reading — done, and the answer is
      *both*: an unattended PCB E2E is possible, and a desktop session is still
      required. `KICAD_API_SOCKET` is never handed to a process KiCad did not
      spawn, but it does not have to be: the server listens on the deterministic
      `%LOCALAPPDATA%\Temp\kicad\api.sock`, exposed as a named pipe, with an
      empty `KICAD_API_TOKEN` accepted. `scripts/live-pcb-e2e.ps1` is the
      experiment made repeatable — it starts pcbnew, runs both live suites and
      stops pcbnew, with no window ever touched. Three cold runs, 3/3 tests, exit 0.
- [x] J.3.2 If a GUI session is required, record it as a platform constraint and
      keep the `#[ignore]`d tests reading `gated` in the matrix (D26) — a
      *desktop session* is required (pcbnew has no headless mode) while a human
      is not. Recorded in DEV.md, "Driving the PCB path unattended", with the
      three findings that cost a run each: `api.enable_server` must be true
      before KiCad starts and cannot be set over IPC; PowerShell's `Test-Path`
      is blind to the live pipe; the pipe appears before KiCad will answer on
      it. The tests keep their `#[ignore]` and stay `gated` — D26 is unchanged,
      since the matrix scores what the default suite proves.
- [x] J.3.3 Give the answer a gate: `live-ipc` job in `.github/workflows/e2e-kicad.yml`,
      separate from `e2e` so an IPC failure and a kicad-cli failure stay
      distinguishable. The runner-shaped risk — a KiCad profile that has never
      been written — was rehearsed locally by pointing `APPDATA` at an empty
      directory: the script writes the minimal `kicad_common.json`, KiCad
      accepts it, and the suites pass 3/3, exit 0. What no local run can settle
      is whether `windows-latest` gives pcbnew a usable window station.
- [x] J.3.4 Make the gate actually run on a GitHub runner. It does, and it is
      green: run 32026731031, `live-ipc` 3/3, exit 0. `windows-latest` gives
      pcbnew a usable window station after all — the answer to J.3.3's open
      question is yes. Six failures stood between the job existing and the job
      passing, and every one was named by a measurement rather than guessed:
      Actions had never registered the workflows (no push had ever touched
      `.github/workflows/`); KiCad opened its pipe under the 8.3 short name
      (`RUNNER~1`) while the harness waited for the long spelling, and a pipe name
      is a literal with no path resolution; then three modal dialogs, each served
      *before* the API and so indistinguishable from a hung KiCad — no OpenGL 2.1
      on the runner, the first-run wizard's library page, and its Updates &
      Privacy page; and finally a genuine test failure, because
      `live_ipc.kicad_pcb`'s named net had never been committed. The harness now
      matches the pipe by shape and exports the name that exists, writes the three
      library tables and answers the privacy prompts in profiles it creates, asks
      for software rendering there, and — when it does give up — enumerates
      pcbnew's windows and their child controls, which is what turned each of
      those dialogs from a timeout into a sentence

### Validation
Either an unattended PCB E2E in the gate, or a written constraint with evidence.
Both, as it turned out — and the gate is green on a runner, not only locally.

## J.4 — Adapter matrix — DONE

### Objectif
For each capability, which concrete backend actually runs (`ipc` / `cli` /
`sexpr-file`), so fallbacks are observable instead of implicit.

### Dépendances
F.4.

### Tâches
- [x] J.4.1 Generate it from the same manifest the capability matrix uses —
      it is *in* `docs/capability-matrix.md` rather than beside it: an `adapter`
      column on every tool row, an Adapters summary counting them and saying
      which need a running KiCAD, and the same equality test guarding both. A
      separate document would be a second thing to drift.
- [x] J.4.2 Make the fallback observable at run time too, not only in the
      document: an `ipc→sexpr` tool reports which backend answered
      (`"source": "file"` with no KiCAD listening), pinned by
      `board_and_labels.rs`

### Validation
Generated, committed, and equality-tested like the capability matrix.

---

# Phase K — Multi-harness — DONE

## K.1 — Claude Code and Codex (AGY dropped, D70) — DONE

### Objectif
The handoff must be harness-agnostic: another agent, notably Codex, resumes from
`plan.md`, `progress.md`, Git and the tests without any Claude transcript.

### Dépendances
F.3 (the gateway is the whole external surface).
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

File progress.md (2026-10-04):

# PROGRESS

## Phase actuelle

**Z — Benchmark PCB live V2 contre Konnect v0.13.0 : terminée**, mergée dans
`agentic/main` (`bc3a815`, PR #22). Y4 (reprise Hi-Fi, autre dépôt) reste la
seule unité ouverte.

## Tâche actuelle

Aucune dans ce dépôt.

## Dernière tâche validée

**Z6 — rejeu, docs, PR.**

Validation :
- `bench/results/pcb_live_v2-after-z7-20261004.json` : fork A–E fonctionnels
  3/3, 0 faux succès ; upstream v0.13.0 : A, B, D, E 3/3, C refus à tort 3/3.
- CI PR #22 verte (fmt, clippy, tests 3 OS, PCM) ; `gate.ps1` PASSED sur Z5.
- Rapport : `docs/benchmark-pcb-live-v2.md` ; README et `docs/benchmark.md` ne
  présentent plus v0.2.2 comme comparaison avec l'upstream actuel.

## Décisions actives

- La comparaison fork/upstream se fonde sur `docs/benchmark-pcb-live-v2.md`
  (KiCad 10.0.6, upstream tag `v0.13.0`), jamais sur le benchmark v0.2.2.
- Arbitres du bench : `kipy` 0.8.0 (venv `../_bench-venv`) et `kicad-cli` ; un
  succès MCP n'est jamais une preuve ; tout oracle a deux contrôles.
- Upstream = réservoir de primitives, import sélectif seulement sur cellule
  mesurée perdante. Restent volontairement non importés : `FlipItems` live (D :
  état final déjà correct, coût = un redémarrage éditeur).
- `update_pcb_from_schematic` est `UNPROVEN` dans la matrice : la règle exige un
  test live Rust (`kicad_reads_back`) ; le bench Python ne compte pas.
- Le flake `kam-llm openai_compat::absent_backend_is_unreachable_not_a_panic`
  (port éphémère) peut arrêter `gate.ps1` ; il passe isolé.
- `scripts/*.ps1` et `gate.ps1` se lancent avec `pwsh`.
- Convention : une branche `ai/<phase>`, une PR par phase, merge commit.

## Blocage actif

Aucun.

## Fichiers / zones utiles

- Bench : `bench/pcb_live_v2/{run.py,kicad_session.py,report.py,fixtures/}` ;
  lancer `../_bench-venv/Scripts/python.exe bench/pcb_live_v2/run.py
  --scenario A B C D E --runs 3` (upstream : worktree `../_upstream-v0.13.0`,
  binaire `../_upstream-target/release/konnect.exe`).
- Sync : `crates/konnect-core/src/tools/pcb_sync.rs` (`record_zone_nets` = #779).
- Projet Hi-Fi : `~/Documents/Etabli/Projets/Chaine Hifi`.

## Préconditions de tout test live

1. Aucune autre instance KiCad ouverte (le harness refuse sinon).
2. Aucun dialogue modal (profil dédié, `pcb upgrade` des copies).
3. Toolsets opt-in : `load_toolset` avant l'appel.

## NEXT ACTION

Y4.1 — sur le projet Hi-Fi (dépôt et continuité distincts), reprendre sa
`NEXT ACTION` F1.2-b1 avec un binaire contenant Z (`route_pad_to_pad` live,
parité réelle, sync) ; une release v1.3.0 préalable relève d'une décision de
l'utilisateur.

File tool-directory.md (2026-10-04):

# Konnect — Tool Directory

Canonical reference for every MCP tool exposed by Konnect. Generated from the Rust source (not from hand-maintained prose), so it reflects what the binary actually serves.

**Source of truth**
- Toolset metadata + declared counts: `crates/konnect-core/src/router/registry.rs` (`ALL_TOOLSETS`)
- Meta-tool definitions: `crates/konnect-core/src/router/meta_tools.rs` (`meta_tool_descriptions()`)
- Per-tool names + descriptions: `crates/konnect-core/src/tools/<toolset>.rs` (each `tool!(…)` in the `tools()` vec)

## Overview

- **22 toolsets** organized into 13 categories
- **205 registered tools** + **13 always-visible meta-tools** = **218 total**
- **Four ways to reach a tool**, cheapest last:
  1. **Toolset loading** — `list_toolboxes` → `load_toolset(name)` exposes a whole domain in `tools/list`; `unload_toolset(name)` prunes it. Coarse, and every load makes the client re-fetch the entire catalogue.
  2. **Tool loading** — `find_capabilities(intent)` → `load_tools([names])` exposes exactly the tools named. Same refresh, far less of it.
  3. **The gateway** — `kicad_describe([names])` → `kicad_invoke([calls])` calls tools *without* exposing them at all. The catalogue never changes, so no refresh happens, and a whole sequence fits in one round trip. Measured on the golden suite at Phase F: 2 171 external tokens per task and 4 MCP calls, against 3 770 / 10 for path 2 and 10 912 / 11 for path 1 — the three routes of this same server, which is what that comparison isolates. The gateway route has since drifted to **2 249** as tool descriptions and MCP annotations grew (M.1, 2026-08-24); `docs/benchmark.md` records where the +78 went.
  4. **A plan** — `kicad_invoke([{tool: "apply_plan", …}])` describes the change once instead of enumerating it, and one operation may expand to many calls. Measured on the same divider: 1 124 external tokens against the batch's 2 180; on a four-capacitor decoupling bank, 882 against 2 265. See `docs/benchmark.md`, "Phase G".
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

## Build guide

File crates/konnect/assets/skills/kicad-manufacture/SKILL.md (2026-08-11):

---
name: kicad-manufacture
description: |
  Manufacturing and fabrication workflow for KiCAD projects via MCP tools. Triggers on: "send to fab",
  "order boards", "gerbers", "JLCPCB", "manufacturing", "export for production", "pick and place",
  "assembly files", "generate fabrication outputs", "BOM for fab", "production files", "fab house".
argument-hint: "[fab house or export task]"
---

# KiCAD Manufacturing & Fabrication Workflow

This skill guides Claude through preparing a KiCAD design for manufacturing using Konnect MCP tools.
ALL modifications go through MCP tools — never edit project files directly.

---

## Toolset Loading

Before any manufacturing work, load the required toolsets:

```
load_toolset('pcb_export')       # export_gerber, export_position_file, get_drc_violations
load_toolset('sch_export')       # export_bom (reads the schematic, not the board)
load_toolset('manufacturing')    # export_manufacturing_package, validate_for_manufacturing, estimate_cost
```

Load additional toolsets as needed:

```
load_toolset('sch_analysis')     # inspect nets, verify footprints assigned
load_toolset('integration')      # search_jlcpcb_parts, suggest_jlcpcb_alternatives
load_toolset('pcb_export')       # export_3d for visual verification
```

Always call `get_active_toolsets()` first to see what is already loaded.

---

## Pre-Flight Checklist

Run these checks BEFORE generating any manufacturing outputs. Stop and fix issues at each stage.

### 1. DRC — Zero Errors Required

```
get_drc_violations()
```

- All errors must be resolved. Warnings should be reviewed but may be waived.
- Common blockers: unrouted nets, clearance violations, minimum width violations.
- Do NOT proceed to export if any DRC errors remain.

### 2. Manufacturing Validation

```
validate_for_manufacturing()
```

- Checks board outline is closed
- Checks all pads have copper
- Checks drill sizes are within fabrication limits
- Checks silkscreen does not overlap pads

### 3. Verify Footprints Assigned

Every schematic symbol must have a footprint assigned. Check for:
- Missing footprint assignments (shows as empty Footprint field)
- Mismatched footprints (wrong pad count for the symbol)
- Non-existent footprint references (library not found)

---

## Export Workflow

### One-Shot Export (Recommended)

```
export_manufacturing_package(output_dir, format)
```

Generates all manufacturing files in one call:
- Gerbers (all copper layers + mask + silkscreen + edge cuts)
- Drill files (Excellon format)
- BOM (CSV)
- Pick-and-place / component position file (CPL)
- Job file (optional, fab-house specific)

### Manual Export (When You Need Control)

Use individual tools when you need specific settings per file:

#### Step 1: Gerbers

```
export_gerber(output_dir, layers, options)
```

Standard layers to export:
- F.Cu, B.Cu (and inner layers if present)
- F.Mask, B.Mask
- F.SilkS, B.SilkS
- F.Paste, B.Paste (for stencils)
- Edge.Cuts (board outline)

#### Step 2: Bill of Materials

```
export_bom(output_path, format, fields)
```

Include fields: Reference, Value, Footprint, LCSC (if targeting JLCPCB).

#### Step 3: Component Position File

```
export_position_file(output_path, format, side)
```

Required for SMT assembly. Contains X/Y/Rotation for each component.
Export separately for top and bottom if double-sided assembly.

---

## JLCPCB-Specific Guidance

### Part Sourcing

```
search_jlcpcb_parts(query)           # Find LCSC part numbers
suggest_jlcpcb_alternatives(lcsc_no) # Find alternatives for OOS parts
```

### Part Categories

| Category | Description | Extra Cost |
|---|---|---|
| **Basic** | ~700 common parts, pre-loaded on machine | None |
| **Preferred Ext.** | Popular extended parts | No feeder loading fee  |
| **Extended** | 300k+ parts, loaded on demand | $3 per unique part |

**Strategy**: Use basic parts wherever possible. Every extended part adds $3 to assembly cost.
Search with `search_jlcpcb_parts` and filter by `basic: true` when looking for alternatives.

### Minimum Design Rules (JLCPCB Standard Process)

| Parameter | Minimum Value |
|---|---|
| Trace width | 0.127mm (5mil)  |
| Trace spacing | 0.127mm (5mil)  |
| Via drill | 0.3mm |
| Via annular ring | 0.15mm (6mil) |
| Min hole size | 0.3mm |
| Pad-to-pad clearance | 0.254mm (10mil) |
| Silkscreen line width  | 0.15mm |
| Board thickness | 0.8-2.0mm (1.6 default) |
| Min board size | 10x10mm |

Use `add_design_rule` or `list_design_rules` to configure project rules to match.

### JLCPCB BOM Requirements

- Column headers must be exactly: `Designator`, `Comment`, `Footprint`, `LCSC Part #`
- LCSC Part # format: `Cxxxxxx` (e.g., C14663)
- Group identical parts on one row with comma-separated designators

### JLCPCB CPL (Position File) Requirements

- Columns: `Designator`, `Mid X`, `Mid Y`, `Layer`, `Rotation`
- Coordinates in millimeters
- Rotation in degrees (0-360)
- Layer values: `Top` or `Bottom`

---

## Cost Estimation

```
estimate_cost(quantity, fab_options)
```

Factors that increase cost:
- Layer count (2 vs 4 vs 6+)
- Board size
- Number of unique extended parts
- Double-sided assembly
- Special finishes (ENIG vs HASL)
- Tight tolerances below standard minimums
- Expedited turnaround

---

## 3D Verification

Before submitting to fab, always generate a 3D view:

```
export_3d(output_path, format)
```

Visual checks:
- Component clearance (tall parts near board edges)
- Connector accessibility and orientation
- Mounting hole alignment
- Heatsink/thermal pad clearance
- Enclosure fit (if applicable)

---

## Common Mistakes

1. **Exporting with DRC errors** — Always run DRC first. A clearance violation can short traces on the fab board.
2. **Wrong drill file format** — JLCPCB expects Excellon format. PTH and NPTH in separate files.
3. **Missing board outline** — Edge.Cuts layer must be a closed polygon. Open outlines cause fab rejection.
4. **Silkscreen on pads** — Silkscreen ink on exposed copper pads prevents soldering. Remove overlaps.
5. **Wrong position file origin** — CPL origin must match board origin. Use board center or bottom-left corner consistently.
6. **Forgetting paste layer** — If ordering stencils, F.Paste/B.Paste must be exported.
7. **Out-of-stock parts in BOM** — Always verify availability with `search_jlcpcb_parts` before ordering.
8. **Rotation offsets** — JLCPCB may apply rotation corrections. Review their orientation guide for ICs and polarized components.
9. **Panelization not accounted for** — If panelizing, export from the panel file, not the individual board.
10. **Missing fiducials** — SMT assembly with fine-pitch parts requires at least 2 fiducial marks on each assembly side.

---

## Rules

1. **Never export without passing DRC** — zero errors required
2. **Never skip validate_for_manufacturing** — catches issues DRC misses
3. **Always verify part availability** before finalizing BOM for assembly
4. **Export 3D model** before submitting order — visual sanity check
5. **Save project before export** — ensures exported files match current state
6. **Load toolsets first** — check `get_active_toolsets()` and load what you need
7. **Use one-shot export when possible** — `export_manufacturing_package` ensures consistency
8. **Double-check fab house requirements** — each house has slightly different file format expectations

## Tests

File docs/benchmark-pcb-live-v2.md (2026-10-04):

# PCB live benchmark V2 — fork against Konnect v0.13.0

Five live PCB workflows, the same intention given to both servers, **KiCad as the
referee**. It replaces the August comparison against Konnect v0.2.2 as the basis
for any claim about this fork versus upstream: that one measured token cost on
scripted schematic tasks, at the fork point, and contains no live PCB workload.

Harness: `bench/pcb_live_v2/` (`run.py`, `kicad_session.py`, `report.py`,
fixtures and their generators). Raw results: `bench/results/pcb_live_v2-*.json`.

## Environment

| | |
|---|---|
| KiCad | 10.0.6 (latest stable on 2026-10-04; 10.0.7 is at RC2) |
| OS | Windows 11 Pro 26200 |
| fork | branch `ai/pcb-live-bench-v2`; baseline binary built from v1.2.0 sources (`48465f1`), later runs from the changes below; SHA-256 of each binary is in every result file |
| upstream | `mixelpixx/Konnect` tag **v0.13.0**, commit `6bbe3e4f890ba1d37c0e5d5f38ccd03d90958c9e` (release 2026-10-02), built unmodified |
| live oracle | `kicad-python` (`kipy`) 0.8.0 — KiCad's official IPC binding, shared with neither server |
| saved oracle | `kicad-cli` 10.0.6 (`pcb drc`, `--schematic-parity`), plus the board file as KiCad wrote it |

Upstream `main` moved after the tag (`3ad01f8`, 2026-10-04: e.g. #805 closing
#791, project-file writers vs a running KiCad). None of those commits touches
the five workflows below; the baseline stays the tag.

## Method

* Each run copies a fixture into a fresh directory, starts `pcbnew` on it with a
  private profile, lets **one** server carry out the intention by whatever calls
  it needs, then judges the final KiCad state. Servers may use different call
  sequences; what is compared is *intention → observable KiCad state*.
* Edits that stand in for a GUI user (a footprint moved and not saved, a value
  changed) are made by the oracle side through `kipy`, never by the server.
* `success: true` is never evidence. A run is **functional** only if the live
  read-back and the saved-file checks agree with the intention. A server that
  claimed success on a non-functional run scores a **false success**; one that
  refused, or has no tool for the intention, made no claim.
* **Every oracle has two controls**, injected by the oracle side: the correct
  end state (must pass) and a known-wrong one (must fail). A scenario whose
  controls do not separate is reported invalid and not scored. All five
  separated on every run.
* 3 runs per scenario per implementation.

| | Intention | Oracle | Wrong-result control |
|---|---|---|---|
| A | schematic changed (R2 10k→4.7k, new unconnected R3): bring the open board up to date | `kipy`: R1/R2/H1/H2 positions and layer, tracks identical, R2 = 4.7k, R3 present; `kicad-cli` parity = 0 | naive sync that applies the value and drops board-only H1 |
| B | R2 moved live, not saved: route GND R1.2 → R2.1 | `kipy`: copper chain to R2.1's **live** pad, R2 left where moved; saved DRC: 1 unconnected, no `track_dangling`/`shorting_items` | track drawn to R2.1's saved position |
| C | GND copper zone present; supply renamed +5V in the schematic, so unrouted pad R1.1 changes net | `kipy`: R1.1 on +5V, zone and tracks unchanged, placement kept; parity = 0 | nothing applied |
| D | C310/C311 to B.Cu in place, then C310.1 → via → U1.1 (PVDD) | `kipy`: layer, XY kept, pads mirrored (top/bottom or left/right); pad copper side read from the file KiCad saved; PVDD chain pad → via → pad; DRC: 3 unconnected, no dangling/short/clearance | copper started at C310.1's pre-flip position |
| E | is the board in parity with its schematic? asked diverged, then restored | `kicad-cli pcb drc --schematic-parity` run by the oracle: 1 then 0; server must report >0 then a measured 0 | a reporter that always answers 0 |

## Results — baseline (fork v1.2.0 vs upstream v0.13.0)

`bench/results/pcb_live_v2-baseline-20261004.json`. Every cell was identical on
all three runs; no harness error.

| | fork: functional | fork: false success | upstream: functional | upstream: false success | notes |
|---|---|---|---|---|---|
| A | 0/3 | 0/3 | **3/3** | 0/3 | fork has no sync tool. Upstream applies the delta and keeps placement, copper and H1/H2; it places the new R3 at (5.93, 0.5), outside the board outline |
| B | 0/3 | **3/3** | **3/3** | 0/3 | fork reads pad positions from the saved file and draws to R2's old place, answering `routed: true`; upstream reads the live board (`source: ipc`) |
| C | 0/3 | 0/3 | 0/3 | 0/3 | fork has no sync tool. Upstream **refuses** (`routed_pad_net_change`: "routed copper uses that net") although +3V3 carries no copper: the GND zone makes every net look routed — upstream issue #779, open |
| D | **3/3** | 0/3 | **3/3** | 0/3 | same correct end state. Fork refuses the flip while KiCad holds the board, so the editor must be closed and reopened (3/3 runs); its message said KiCad has no IPC flip, which is false on 10.0.6. Upstream flips over IPC |
| E | 0/3 | **3/3** | **3/3** | 0/3 | fork's `run_drc` never passes `--schematic-parity`; KiCad 10 then writes an empty array and the fork reports 0 while the referee finds 1. Upstream reports 1, then 0 |

MCP tool calls per run (same on all runs): A fork 1 / upstream 3; B 2 / 2;
C 1 / 2; D 10 / 9; E 3 / 3. Median wall clock 5–9 s per run, dominated by
starting `pcbnew`; D costs the fork +3.7 s for the editor restart. External
tokens were not compared: the scripted calls are fixed, so the bytes reflect
response verbosity, not an agent's cost.

## Classification

| capability | verdict | basis |
|---|---|---|
| route between pads with an unsaved live edit (B) | **upstream better — critical fork defect** | false success 3/3, = upstream #700, fixed upstream before v0.13.0 |
| schematic-parity check (E) | **upstream better — critical fork defect** | false green 3/3 |
| schematic → PCB sync, additions/updates (A) | **upstream better** | fork has no capability |
| sync with a net change on a zoned board (C) | **neither — upstream defect (fail-closed)** | upstream refuses wrongly, no corruption; fork absent |
| flip + via layer change (D) | **equivalent end state; upstream better on intervention** | both functional 3/3; fork needs an editor restart |

**Facts** are the table above. **Interpretations**: the two fork defects are
the same class the Hi-Fi stress test met — an answer computed from the saved
file or from a check that never ran, presented as a live truth. Upstream's C
failure is the safe direction: it refuses rather than corrupting.
**Uncertainties**: one machine, one KiCad version, two-to-five-part fixtures;
the scripted agent picks a fixed via location and fixed call sequences, so this
measures primitives, not planning; nothing here measures the 77 `UNPROVEN`
capabilities outside these five workflows.

## Decisions taken from these results

* **B** — backport: `route_pad_to_pad` reads both pads from the board KiCad has
  open, in the same guarded IPC call that writes the tracks; no silent file
  fallback.
* **E** — backport: `run_drc` always requests `--schematic-parity`, and a parity
  test KiCad says it could not run is reported as unchecked (`null` plus a
  diagnostic), never as 0.
* **D** — the false message is corrected. Driving KiCad's `FlipItems` needs a
  newer vendored proto; not done in this change, because the end state is
  already correct and the cost is one editor restart.
* **A / C** — `update_pcb_from_schematic` ported from v0.13.0 (selective import,
  no rebase): the prerequisite phase X9 named — a live suite to prove it — now
  exists, A and C. While porting, upstream #779 is fixed in the fork: a copper
  zone's net is readable (`Zone.settings.copper_settings.net`), so only that net
  counts as routed; a zone whose net cannot be read keeps the fail-closed
  fallback. Its capability-matrix row stays `UNPROVEN` — the proof rule wants a
  live read-back test inside the Rust suite, and this Python benchmark does not
  count toward it.
* Everything else upstream adds was left out: these five workflows give no
  measured reason to import it.

## Results — after the changes

`bench/results/pcb_live_v2-after-z5-20261004.json` (B, D, E after the two
backports) and `bench/results/pcb_live_v2-after-z7-20261004.json` (all five,
after the sync port; the fork binary's SHA-256 is in the file — it was built
from the working tree on top of `48a19d6`). Controls separated on every
scenario; every cell identical on its three runs.

| | fork: functional | fork: false success | upstream v0.13.0: functional | notes |
|---|---|---|---|---|
| A | **3/3** | 0/3 | 3/3 | both place the new R3 outside the board outline, at (5.93, 0.5) |
| B | **3/3** | 0/3 | 3/3 | |
| C | **3/3** | 0/3 | 0/3 (refused) | fork better: #779 fixed |
| D | 3/3 | 0/3 | 3/3 | fork still needs an editor restart for the flip |
| E | **3/3** | 0/3 | 3/3 | |

So, on these five live PCB workflows with KiCad as the referee: the fork now
matches upstream v0.13.0 on A, B and E, is ahead on C, and behind on D's
manual step. Before these changes it had two false successes (B, E) and two
missing capabilities (A, C). Nothing measured here covers the rest of either
surface.

No general superiority is claimed in either direction: on these five workflows,
at these versions, the tables say where each wins, loses or fails.

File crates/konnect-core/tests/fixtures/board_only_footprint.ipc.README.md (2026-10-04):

# `board_only_footprint.ipc.bin`

A single `kiapi.board.types.FootprintInstance`, serialised exactly as KiCad's
IPC API sent it, for a **board-only footprint** — one placed directly on the
board with no schematic symbol behind it.

Decoded by `pcb_sync`'s regression tests for issue #452, where the defect was
the reader turning the *absence* of a schematic identity into the shared
identity `/`.

## Provenance

| | |
|---|---|
| KiCad | 10.0.6, macOS (Apple Silicon) |
| Source board | `crates/konnect-ipc/tests/fixtures/live_ipc.kicad_pcb` — KiCad's own GPL EuroCard160mmX100mm template |
| Item | `MH1`, one of the template's four `MountingHole:MountingHole_2.7mm_M2.5_DIN965` holes, none of which carries a `(path ...)` line |
| Transport | `GetItems` over the running editor's IPC socket |
| Captured | 2026-09-08 |
| Size | 1797 bytes |

## Regenerating it

Set `KONNECT_CAPTURE_IPC_FIXTURE=1` when running the ignored live test
`kicad_reports_an_empty_sheet_path_for_a_board_only_footprint` in
`crates/konnect-ipc/tests/live_kicad_test.rs`. That test also *verifies* the
property this capture exists to encode, so a regeneration that changes the
answer fails rather than silently rewriting the fixture.

The live test needs a running KiCad with its API enabled, the board above open,
and `KICAD_API_SOCKET` pointing at the **PCB editor's** socket. Resolve that by
matching `api-<pid>.sock` to a live `pcbnew` process: a stale socket from a
closed session can be newer by mtime than the live one.

## Redaction

Nothing was removed. The message was checked for filesystem paths, usernames,
hostnames and the board filename before being committed; it contains only
KiCad's stock `MountingHole` library strings, standard field names, protobuf
type URLs and KIIDs from the template board. `symbol_sheet_name` and
`symbol_sheet_filename` — the two fields that could carry a path — are empty
strings on a board-only footprint, which is why there is nothing to redact.

## What it records that a hand-written fixture got wrong

Two things, both corrected by this capture:

1. `symbol_path` is **present and empty** — `Some(SheetPath { path: [] })`,
   with `path_human_readable: ""`, not `"/"` and not `None`. The whole #452 fix
   rests on that distinction.
2. `not_in_schematic` is **false**. KiCad marks a board-only mounting hole
   `exclude_from_position_files` and `exclude_from_bill_of_materials` instead.
   The hand-written fixture this replaced set that flag true, which made the
   planner's rename-ambiguity branch unreachable from the tests written to
   cover it.

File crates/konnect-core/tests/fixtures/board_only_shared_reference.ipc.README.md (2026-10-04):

# `board_only_shared_reference.ipc.bin`

A single `kiapi.board.types.FootprintInstance`, serialised exactly as KiCad's
IPC API sent it, for a **board-only footprint carrying the reference `REF**`** —
one of two such footprints on the same board.

Decoded by `pcb_sync`'s regression tests for issue #452, where the remaining
defect was `duplicate_board_reference` refusing to sync a board whose
unannotated graphics all share KiCad's default reference. The sibling capture
[`board_only_footprint.ipc.bin`](board_only_footprint.ipc.README.md) cannot
witness that case: its mounting hole is annotated `MH1`.

## Provenance

| | |
|---|---|
| KiCad | 10.0.6, macOS (Apple Silicon) |
| Source board | `crates/konnect-ipc/tests/fixtures/board_only_shared_reference.kicad_pcb` |
| Item | one of the board's two `MountingHole:MountingHole_2.7mm_M2.5_DIN965` instances, neither of which carries a `(path ...)` line and both of which are named `REF**` |
| Transport | `GetItems` over the running editor's IPC socket |
| Captured | 2026-09-09 |
| Size | 2063 bytes |

The source board was written by KiCad itself, through the PCB editor's own
scripting API: `NewBoard`, then `FootprintLoad` against the stock
`MountingHole.pretty` twice, then `SaveBoard`. Nothing about it is
hand-authored — KiCad's parser read its own `.kicad_mod`, KiCad's writer wrote
the board, and `REF**` is the reference string that library file already
carries. That is also the point the fixture exists to record: a board can hold
two board-only footprints with the same reference without anything being wrong
with it, because the library's own default is what put it there.

It is a new board rather than two more footprints on `live_ipc.kicad_pcb`,
which is deliberately still in the legacy KiCad 9 format (`version 20241229`,
against this board's `20260206`). Saving that fixture from KiCad 10 upgrades it
in place and destroys the legacy-format coverage it exists to provide.

## Regenerating it

Set `KONNECT_CAPTURE_IPC_FIXTURE=1` when running the ignored live test
`kicad_reports_the_same_reference_for_two_board_only_footprints` in
`crates/konnect-ipc/tests/live_kicad_test.rs`. That test also *verifies* the
properties this capture exists to encode — that the shared reference is
`REF**`, that IPC returns as many footprints under it as the file carries, and
that each arrives with a present-but-empty `SheetPath` — so a regeneration that
changes the answer fails rather than silently rewriting the fixture.

The live test needs a running KiCad with its API enabled, a **copy** of the
board above open, and `KICAD_API_SOCKET` pointing at the PCB editor's socket.
Resolve that by matching `api-<pid>.sock` to a live `pcbnew` process: a stale
socket from a closed session can be newer by mtime than the live one.

`the_shared_reference_fixture_still_carries_a_duplicate_board_only_reference`
checks the board's side of this without KiCad and is **not** `#[ignore]`d, so CI
runs it. It is what lets the unit tests build their duplicate pair by varying
only the KIID: that the board really carries two `REF**` footprints is checked,
not assumed.

## The KIID variation, stated plainly

`pcb_sync`'s tests decode this one message twice and give the second copy a
different KIID, because the planner keys on KIID and a board needs two distinct
objects. **Nothing else is varied — in particular not the reference**, which is
the shared value the tests are about and is exactly what KiCad sent.

An undocumented variation is a hand-built fixture wearing a capture's name, so:
one field, named here and in the helper's doc comment, backed by the guard test
above.

## Redaction

Nothing was removed. The message was checked for filesystem paths, usernames,
hostnames and the board filename before being committed; it contains only
KiCad's stock `MountingHole` library strings, standard field names, protobuf
type URLs and KIIDs generated by KiCad for this board. `symbol_sheet_name` and
`symbol_sheet_filename` — the two fields that could carry a path — are empty
strings on a board-only footprint, which is why there is nothing to redact.

## On `ki_fp_filters`, which a reviewer will ask about

CONTRIBUTING requires real-KiCad fixtures and names a specific failure: a
hand-written footprint missing `(property ki_fp_filters "…")`. The source board
here has none — and neither does `live_ipc.kicad_pcb`, the board upstream ships
and the source of the capture accepted in #504.

Across the tracked `.kicad_pcb` fixtures, `ki_fp_filters` appears **only on
boards whose footprints carry `(path ...)`** — `pic_programmer` (49),
`ecc83-pp` (6), `RoyalBlue54L-NFC-Antenna` (1). Every board with no pathed
footprint has zero, this one and `live_ipc.kicad_pcb` included. The property
comes from the schematic symbol a footprint was placed for, so its absence on a
board-only mounting hole is correct rather than a sign of a synthetic file.

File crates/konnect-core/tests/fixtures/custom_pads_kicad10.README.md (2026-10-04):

# Custom-shape pad footprints

`custom_pads_texas_rje0020a_kicad10.kicad_mod` and
`custom_pads_vqfn20_kicad10.kicad_mod` are two stock KiCad footprints whose
corner pads are `smd custom`. Konnect's typed placement path cannot carry a
custom-shape pad, so `update_pcb_from_schematic` refuses a plan that needs one.
These are the two footprints that refusal met on a real board, where it named
neither of them (#657).

## Provenance

Copied byte for byte from the KiCad 10.0.5 standard library on Windows 11.
Nothing was edited, and the repository stores the directory `-text`, so the
bytes are KiCad's.

| Fixture | Library file | SHA-256 (first 16) |
|---|---|---|
| `custom_pads_texas_rje0020a_kicad10.kicad_mod` | `Package_DFN_QFN.pretty/Texas_RJE0020A_VQFN-20-1EP_3x3mm_P0.45mm_EP0.675x0.76mm.kicad_mod` | `e4aad731d0feb660` |
| `custom_pads_vqfn20_kicad10.kicad_mod` | `Package_DFN_QFN.pretty/VQFN-20-1EP_3x3mm_P0.45mm_EP1.55x1.55mm.kicad_mod` | `2be5b256050d408f` |

Both carry `(generator "kicad-footprint-generator")`. The file name inside a
`.pretty` directory has to equal the footprint name, so a test that resolves
them through a library table writes them out under their library names.

## What they contain

Both are 20-pin VQFNs with a rectangular exposed pad numbered 21. In each, the
eight corner pads (1, 5, 6, 10, 11, 15, 16 and 20) are `smd custom` with a
`primitives` polygon, and the other twelve signal pads are `smd roundrect`.
Unnumbered `F.Paste`-only pads sit under the exposed pad: one in the Texas
footprint, four in the generic one.

The first is the footprint the schematic symbol names; the second is what a
designer substitutes when the first is refused. Both are refused for the same
reason, which is why a diagnostic that names nothing sends the designer round
twice.

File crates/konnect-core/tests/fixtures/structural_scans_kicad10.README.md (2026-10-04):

# Structural schematic scan fixture

`structural_scans_kicad10.kicad_sch` is Eeschema-authored evidence for the
three saved-schematic paths repaired by issue #84:

- wire endpoint repair sees a loose wire at `(190.54, 193.04)` and one
  geometric destination at `(190.5, 193.04)`, represented by both R3 pin 1
  and the `SNAP` label;
- datasheet enrichment sees R1's placed-instance `LCSC` property (`C25804`)
  and empty `Datasheet` property;
- `SchematicBuilder` sees the complete top-level KiCad section ordering and
  full library/symbol records.

The seed was the existing `junction_reconcile.kicad_sch` fixture, which was
built through Konnect against KiCad's stock `Device:R` library. The deliberate
wire, label, and custom-property cases were added, then the whole document was
parsed and force-resaved by KiCad 10.0.5:

```text
kicad-cli sch upgrade --force structural_scans_kicad10.kicad_sch
```

That final Eeschema serialization is committed here. It was reload-checked
with KiCad 10.0.5's netlist exporter:

```text
kicad-cli sch export netlist --output structural_scans.net structural_scans_kicad10.kicad_sch
```

The ignored real-KiCad E2E regression repeats the force-resave and netlist
export. The three focused module tests copy this same fixture, exercise their
respective mutation/serialization paths, and verify committed readback.

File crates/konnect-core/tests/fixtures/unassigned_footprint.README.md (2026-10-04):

# `unassigned_footprint.net`

A real `kicad-cli sch export netlist --format kicadsexpr` export (Eeschema
10.0.0-rc2, 2026-09-11) of a one-sheet schematic with three components:

| Reference | Symbol | Footprint field | `(footprint …)` node in the export |
|---|---|---|---|
| `C1` | `Device:C` | `Capacitor_SMD:C_0603_1608Metric` | present |
| `R1` | `Device:R` | *(empty — never assigned)* | **absent** |
| `R2` | `Device:R` | `Resistor_SMD:R_0603_1608Metric` | present |

`R1` pin 1 is wired to `C1` pin 1, so the unassigned component also appears
in the `nets` section (`Net-(C1-Pad1)`), which is the case #507 is about: a
sync must keep the other components and report `R1`, not fail on it.

Recipe: `create_project`, three `add_schematic_component` calls,
`edit_schematic_component … footprint=` for `C1` and `R2` only, one
`add_wire`, then the kicad-cli export above. The only edit to the export is
the `(source …)` path, replaced by the bare file name. Line endings are the
export's own (CRLF); the directory is `-text` in `.gitattributes`.

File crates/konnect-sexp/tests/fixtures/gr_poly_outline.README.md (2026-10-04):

# gr_poly outline fixture provenance

`gr_poly_outline.kicad_pcb` is a minimal KiCad-authored board for the
`gr_poly`-recognition regression covered by #593. It exists so that
`board_outline_bbox` (`crates/konnect-sexp/src/board.rs`) and its placement
consumer are exercised against a real `gr_poly` Edge.Cuts outline as pcbnew
actually serializes one, rather than only against a rectangle produced by
string surgery on another fixture.

## Source and reduction

The outline is a real Edge.Cuts shape copied out of a large user project
board on which Konnect's placement scoring hit the bug this fixture
regression-tests (outline recognized only for `gr_line`/`gr_rect`/`gr_arc`/
`gr_circle`/`gr_curve`, so a `gr_poly`-outlined board was treated as having
no outline at all). The outline was pasted into a brand-new, otherwise-empty
PCB and the file was saved by KiCad's own `pcbnew`; no board content besides
that one outline and KiCad's standard board scaffolding (layer table, `setup`
block, `pcbplotparams`) was added.

- Board format version: `20260206`
- Generator / version: `pcbnew` / `10.0`
- SHA-256:
  `92c849c90a2c57293c75605d92b60275e617c552c6b395ccc68ba2d10c455f07`

## Shape

A single 12-vertex, non-rectangular (concave/notched) `gr_poly` on
`Edge.Cuts`, UUID `5702b6a5-7ccf-410a-9402-7e25b4e3fb76`. Its exact bbox,
computed by hand from the vertex list, is:

```
(103.42, 78.96) .. (154.48, 116.96)
```

This shape choice is deliberate: the concavity means the vertex-hull bbox is
still exact (straight edges), but the fixture is not reducible to a simple
rectangle-of-four-corners the way the earlier string-surgery test was —
catching mistakes that only show up on a real, irregular outline.

The committed file is therefore KiCad-authored serialization (copy-outline +
new board + KiCad save), not a hand-written test wrapper.

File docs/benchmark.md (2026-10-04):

# Benchmark

> **Scope.** This document compares the fork with Konnect **v0.2.2** — the fork
> point, August 2026 — on schematic tasks and context cost. It is not evidence
> about today's upstream nor about live PCB work. For that, see
> [benchmark-pcb-live-v2.md](benchmark-pcb-live-v2.md) (fork vs Konnect
> v0.13.0, KiCad 10.0.6 as referee).

Everything in this document is measured on this machine with the harness in
`bench/`. Nothing here is estimated. Where a target was not reached, it says so.

**Machine** — Windows 11 Pro 26200, AMD Ryzen 7 9800X3D (8C/16T), 32 GiB RAM,
RTX 5080 (16 303 MiB VRAM), KiCad 10.0.3 per-user install, protoc 35.1,
rustc 1.96.0 (pinned).

**Baseline** — `mixelpixx/Konnect` v0.2.2 at commit `5cd6454`, unmodified.

---

## What is measured, and why it is measured this way

Three numbers matter and only one of them is obvious:

* `RESPONSE_TOKENS` — the text tool results push into the caller's context.
* `CATALOG_TOKENS` — `tools/list` payloads the client re-fetches because the
  server sent `notifications/tools/list_changed`. **The caller cannot decline
  this.** A harness that ignores the notification would be broken, so the cost
  is real even though no tool call appears to have caused it.
* `EXTERNAL_TOKENS` = the two added together. This is what a harness actually
  eats per task, and it is the number the project is judged on.

Early runs of this harness undercounted by 8 000 tokens per task because the
bench client ignored `list_changed`. It now re-fetches like a real client does
(`bench/mcp_client.py`, `auto_refresh_tools`).

Success is never judged from a model's prose. Assertions run KiCad's own ERC
through `kicad-cli`, or read the design back through the server's query tools.
A task passes only if every step succeeded *and* every assertion held.

## Golden tasks

Seven tasks in `bench/tasks/`, each starting from an empty temp directory:

| id | category | what it exercises |
|---|---|---|
| `sch_divider` | schematic_simple | placement, power symbols, pin-to-pin wiring, net label, ERC=0 |
| `sch_ldo` | schematic_simple | AMS1117 + input/output caps, batched wires and junctions, ERC=0 |
| `sch_template_stm32` | schematic_complex | reference-circuit template instantiation |
| `sch_hierarchy` | schematic_complex | hierarchical sheet, sheet pins, sheet duplication, page renumbering |
| `manufacturing_exports` | manufacturing | BOM, netlist, schematic SVG through `kicad-cli` |
| `recovery` | recovery | five wrong inputs must each fail loudly, then the session must still build a correct ERC-clean design |
| `sch_inspection` | inspection | reads a fixture design back and must not change a byte of it |

Coordinates in the task specs are exact 1.27 mm grid multiples and the pin
offsets are the ones `get_symbol_info` actually reports, so a run is
reproducible rather than approximately right.

### Task schema — what a task may declare about itself

Beyond `steps` and `assert`, every field below is optional and defaults to the
permissive answer, so an undeclared task is scored exactly as it was before.

| field | default | meaning |
|---|---|---|
| `fixture: <name>` | none | copy `bench/fixtures/<name>.kicad_*` into `$WORK` as `<project_name>.kicad_*` **in Python, before the server starts** |
| `safety: read_only \| mutating` | `mutating` | the tier the run is held to |
| `expected_tools: [..]` | `[]` | every name must have been called |
| `allowed_tools: [..]` | unset | if declared, a domain tool outside `allowed_tools ∪ expected_tools` is an unnecessary call |
| `forbidden_tools: [..]` | `[]` | any call is a violation |
| `max_calls: N` | unset | MCP call budget |

`fixture` exists because `sch_inspection` could not otherwise have a subject: a
task that builds its own design is not read-only, and asking it to build one
with a write tool would make the tier untestable. The fixture is a real
`create_project` + `batch_place_components` output kept with `--keep`, so its
`lib_symbols` are embedded and no installed library is needed to read it.

**What is judged is the setup and the steps, never the assertions.** The
assertions are the harness's oracle, not something an agent did:
`components_present` reads the design back, and charging a task for the read
that proves it succeeded would make its budget depend on how thoroughly it is
checked. The call index and the disk fingerprint are both taken after the last
step and before the first assertion.

What the audit judges is the **executed** path, not the task file. Judging the
YAML against the YAML would make `forbidden_tools` and `missing_expected`
unfalsifiable — a task cannot call a tool its own step list never named. In the
direct load modes the name is the `tools/call` that went on the wire; in
`gateway` mode the whole path travels inside one `kicad_invoke`, and the name
comes back out of the server's own per-entry `tool` field, so the audit reads
the gateway's answer about what it ran rather than the request that asked for
it. An entry the batch never produced is not counted as called. The meta-tools — `load_tools`,
`load_toolset`, `list_toolboxes`, `kicad_describe`, `find_capabilities`,
`kicad_invoke` — count against `max_calls`, because a round trip is a round
trip, but they are subject to neither `allowed_tools`, `forbidden_tools` nor the
`safety` tier. Judging the door instead of what went through it would mark every
gateway run as a write.

`max_calls` is measured rather than guessed: each task's budget is its call
count in `search`, the costliest load mode, plus two. The YAML comment on each
one records the number and the mode it came from.

### `read_only` is checked twice, and the second check does not trust the first

| violation | what it means |
|---|---|
| `forbidden` | a `forbidden_tools` entry was called |
| `safety` | a `read_only` task called a tool the capability registry classifies as `write` |
| `disk_mutation` | a `read_only` task's `$WORK` fingerprint changed |
| `not_allowed` | a domain tool outside `allowed_tools ∪ expected_tools` was called |
| `missing_expected` | an `expected_tools` entry was never called |
| `max_calls` | the budget was exceeded |

The first three are the **safety violations** and the gate allows zero. Any
violation of any kind fails the run.

`safety` is declarative: it reads `docs/capability-matrix.md`, which is
generated from `konnect_core::capability::tool_effect` by a test that fails if
the document has drifted. An unknown tool is a write, exactly as on the Rust
side. `disk_mutation` is the check that believes none of that — a
`{relative path: (size, sha256)}` map over the whole of `$WORK`, taken before
the first step and after the last. **If the Rust classification lies, the
read-only task still fails.** That independence is the reason the field exists,
and it is verified rather than asserted: with `capabilities.is_write`
monkeypatched to return `False` for everything, a write step added to
`sch_inspection` still produces `disk_mutation` as the only violation.

### Unnecessary calls, and instability

`UNNECESSARY_CALL_RATE` = executed invocations outside `allowed_tools ∪
expected_tools`, over all scored calls in the run set. Only `recovery` declares
`allowed_tools`, and only because recovery is where an agent is most tempted to
flail: the reads a recovering caller may legitimately use to find out what state
it is in are named, and anything else is flailing rather than diagnosis.

`INSTABILITY_RATE` needs repeats. A run's issue signature is
`(success, tuple(tools_used))`; a task's rate is
`1 - modal_signature_runs / runs_of_that_task`, and the suite's rate is the mean
of the per-task rates. With `--repeat 1` it prints `n/a` and, under `--enforce`,
is skipped rather than passed — one run per task cannot disagree with itself,
and scoring that as stable would be a claim nothing measured.

### The gate

`--enforce` turns the four thresholds into an exit code. Without it they are
printed and nothing more, because `--load-mode search` has a known and intended
failure rate and is a measurement of retrieval, not a gate.

| threshold | limit |
|---|---|
| `min_pass_rate` | 0.95 |
| `max_safety_violations` | 0 |
| `max_unnecessary_call_rate` | 0.05 |
| `max_instability_rate` | 0.05 |

```powershell
python bench\runner.py --server .\target\release\konnect.exe `
    --load-mode gateway --repeat 3 --enforce
```

21 runs (7 tasks × 3), all four thresholds PASS, exit 0, in both `gateway` and
`toolsets`.

### Load modes

The same seven tasks run under four loading strategies:

* **`toolsets`** — `list_toolboxes` then `load_toolset([...])`. What upstream
  Konnect offers, and what its skills tell an agent to do.
* **`tools`** — `load_tools([exact names])`. Fine-grained loading with oracle
  knowledge of the tool names. The floor for anything that still goes through
  `tools/list`.
* **`search`** — `find_capabilities(intent)` on the task's plain-language
  intents, load whatever comes back. No oracle. Scores retrieval, not the
  server.
* **`gateway`** — `kicad_describe([exact names])` then one batched
  `kicad_invoke`. Same oracle as `tools`, so the comparison isolates *how the
  schemas arrive* and nothing else. Assertions run through the gateway too: a
  `run_erc` called directly would be a tool the gateway never had to expose,
  and the number would be a lie.

`toolsets`, `tools` and `gateway` all get oracle knowledge, so differences
between them are loading mechanics, never search quality.

---

## Results

### MCP surface cost (`bench/surface.py`, tiktoken `o200k_base`)

| | tools | tokens |
|---|---|---|
| baseline `tools/list` at startup — Konnect v0.2.2 | 19 | 1 680 |
| baseline `tools/list` at startup — fork, step 1 | 21 | 1 958 |
| baseline `tools/list` at startup — fork, step 2 | 16 | **1 454** |
| baseline `tools/list` at startup — fork, gateway | 18 | 1 725 |
| baseline `tools/list` at startup — fork, Phase D | 18 | 1 912 |
| baseline `tools/list` at startup — fork, Phase E | 18 | 1 952 |
| baseline `tools/list` at startup — fork, Phase E + validators | 18 | 1 998 |
| full catalogue, all 18 toolsets loaded | 193 / 195 / 197 | 22 329 / 22 190 / 22 648 |

Step 1 made the startup surface **278 tokens larger** — the price of the two new
meta-tools (`find_capabilities`, `load_tools`) — and that regression is what
bought the per-task reduction below. Step 2 paid it back and more: **1 958 →
1 454**, which is also 13.5 % under upstream's own 1 680 with the meta-tools
still in place.

Heaviest single tools before compression: `create_symbol` **1 448 tk**,
`create_footprint` 530, `add_hierarchical_sheet` 318. `create_symbol` alone was
6.4 % of the whole catalogue.

### Step 2 — where the 504 startup tokens came from

Two changes, both measured with `bench/surface.py`:

1. **Schema compression on the three heaviest tools.** `create_symbol`
   **1 448 → 1 077** (−25.6 %), `add_hierarchical_sheet` 318 → 285,
   `create_footprint` 530 → 519. No property, enum value or default was
   removed. The win is structural: `create_symbol` inlines the same pin-item
   object **three times** (`pins`, `units[].pins`, `power_pins`), so every word
   in it was billed three times. Dropping the two self-evident per-field
   descriptions there (the `type` and `style` enums document themselves) and
   stating the one fact they carried — NC is spelled `no_connect` — once in the
   tool description took the pin item from 219 to 118 tokens per copy.
   `create_footprint`'s prose value lists (`"'smd', 'thru_hole',
   'np_thru_hole'"`) became real `enum`s: nearly the same token count, but now
   validated, and `shape` gained the two KiCad values the prose had omitted.
   Catalogue effect: 22 799 → 22 384 (−1.8 %). It does **not** move the golden
   suite, because no golden task loads the `library` toolset — stated here
   rather than quietly folded into the headline.
2. **`config` left the starter kit.** It was 7 tools and **625 tokens** in every
   single `tools/list`, and the golden suite calls **zero** of them. The two
   read paths a session actually opens with (`load_user_config`,
   `get_effective_config`, 118 tk) are now admitted individually through a new
   `STARTER_TOOLS` list; the five write / design-rule tools cost 507 tokens per
   refresh and are one `find_capabilities` call away. Verified before shipping:
   `find_capabilities` ranks the removed tools **first** on their own intents —
   "remember that I always use JLCPCB" → `save_user_config`, "add a design rule
   for decoupling" → `add_design_rule`, "list my design rules" →
   `list_design_rules`. Discoverability is preserved; only the permanent cost is
   gone.

### Golden suite

18 runs (6 tasks × 3 repeats) per column, except `search` (1 repeat, deterministic).

| Metric | Konnect baseline | Fork `toolsets` | Fork `tools` | Fork `search` | Fork `gateway` |
|---|---|---|---|---|---|
| SUCCESS_RATE | 18/18 (100 %) | 18/18 (100 %) | 18/18 (100 %) | 6/6 (100 %) | **18/18 (100 %)** |
| MCP_CALLS median/task | 11 | 11 | 10 | 16 | **4** |
| WALL_CLOCK_P50 (ms) | 70 | 71 | 64 | 69 | 72 |
| WALL_CLOCK_P95 (ms) | 888 | 902 | 1 183 | 333 | 916 |
| RESPONSE_TOKENS/task | 3 984 | 2 056 | 964 | 2 765 | 1 995 |
| CATALOG_TOKENS/task | 8 389 | 8 163 | 2 281 | 7 103 | **0** |
| **EXTERNAL_TOKENS/task** | **12 373** | 10 220 | 3 197 | 9 868 | **1 995** |
| RETRY_RATE | 0 | 0 | 0 | 0 | 0 |
| ROLLBACK_RATE | 0 | 0 | 0 | 0 | 0 |

**Headline: 12 373 → 1 995 external tokens per task, −83.9 %, with success rate
unchanged and MCP calls down from 11 to 4.**

Both V1 surface targets are met in the `gateway` column: `EXTERNAL_TOKENS/task`
≤ 2 000 and median `MCP_CALLS` ≤ 5.

That column is the Phase F measurement, kept as the reference point for the
surface work. Phase D then added the transaction guarantees and moved it to
2 033 — 33 tokens over the target, for reasons and numbers in "Phase D" below.

### The gateway — where the last 1 200 tokens went

`kicad_describe` + `kicad_invoke` (`crates/konnect-core/src/router/meta_tools.rs`)
call any registered tool without exposing it. Two costs vanish:

* **`CATALOG_TOKENS` → 0.** Nothing is added to `tools/list`, so no
  `notifications/tools/list_changed` fires and the client never re-fetches. In
  `tools` mode that refresh was 2 281 tokens per task — more than twice the
  964 tokens of actual tool output it accompanied. A stdio test asserts the
  catalogue is byte-identical before and after a `kicad_invoke` that runs an
  unloaded tool, so this cannot silently regress.
* **Round trips collapse.** A task's whole scripted path is one batched call:
  median MCP calls 10 → **4** (describe, the batch, and the assertions' own
  reads — which also go through the gateway, so nothing is measured through a
  cheaper door than the one being sold).

The trade is stated rather than hidden: `RESPONSE_TOKENS` rises from 964 to
1 995 because the schemas now arrive inside a `kicad_describe` result instead of
a catalogue refresh. That is the point — the caller asked for exactly those
schemas, once, instead of being handed the whole list including tools it already
had. Net per task: −1 202 tokens.

The two new meta-tools cost 271 tokens on the startup surface (1 454 → 1 725),
paid **once per session** rather than per task. Upstream's own startup is 1 680,
so the fork now sits 45 tokens above it while carrying four extra meta-tools.

Batching does not buy anonymity: every inner call is recorded with the shared
observer under its own tool name, asserted by a test that reads
`get_recent_calls` after a batch.

Progression across the three steps:

| | baseline | step 1 (`tools`) | step 2 (`tools`) | step 3 (`gateway`) |
|---|---|---|---|---|
| EXTERNAL_TOKENS/task | 12 373 | 3 698 | 3 197 | **1 995** |
| CATALOG_TOKENS/task | 8 389 | 2 785 | 2 281 | **0** |
| MCP_CALLS median/task | 11 | 10 | 10 | **4** |
| `tools/list` at startup | 1 680 | 1 958 | 1 454 | 1 725 |

Step 2 moves every load mode, because the startup surface is re-sent in every
catalogue refresh regardless of how tools are loaded: `toolsets` 10 725 →
10 220, `search` 10 394 → 9 868. Step 3 makes that irrelevant for callers that
use the gateway, and adds 271 tokens to startup for callers that do not.

P95 in the `tools` column moved 900 → 1 183 ms. That is `kicad-cli` spawn
variance on `manufacturing_exports`, not server work: P50 went *down* (72 → 64
ms) and no code on that path changed. It is recorded rather than smoothed.

P95 is dominated by `run_erc`, which spawns `kicad-cli` (1 086 ms mean). Nothing
in this work touched that, and nothing should: it is KiCad doing real work.
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

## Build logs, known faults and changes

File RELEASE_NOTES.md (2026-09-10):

# KiCad Agentic MCP v1.2.0

Proof release, and a deliberately uncomfortable one. Until now a mutation could
be published `SUPPORTED` because our own code and our own tests said so. For a
KiCad mutation that is not evidence: the document belongs to KiCad, and only
KiCad can say whether it still reads it. This release makes the level of proof a
**property of the capability**, applies it, and publishes the result — including
a headline coverage figure that falls by two thirds.

Three mutations turned out to write where KiCad does not read. All three
answered `success`. One tool is added, so the surface is now **204 tools across
22 toolsets**. No tool signature changes and no parameter is removed.

The minor version marks what an integrator actually sees: the published
capability matrix is not comparable to v1.1.4's, because it is measured against
a stricter rule.

The benchmark and model-fit figures further down were taken on 2026-08-24 for
v1.0.0, on the machine named at the top of
[docs/benchmark.md](docs/benchmark.md), from artefacts committed under
`bench/results/`. This release did not re-run them, so those numbers describe
v1.0.0 and are reproduced unchanged. The separate Windows binary-size figure was
measured on v1.1.0 and is labelled as such. Where a target was missed, it says
so and the target is not moved.

## What changed in v1.2.0

- **The proof a capability needs is now derived from what it can damage.**
  `Capability::required_proof` reads (effect, domain, write target, adapter): a
  read or a non-KiCad write settles internally; a written design document needs
  KiCad to load it back; a live-editor operation needs the running session to be
  asked what it now holds. Anything proved more weakly than its own bar
  publishes `UNPROVEN`. Previously nothing said how strong a proof had to be, so
  a unit test — our code agreeing with our code — sufficed for any claim.

- **Published coverage of the KiCad domains falls from 74.5 % to 28.9 %, with 77
  entries `UNPROVEN`.** Nothing regressed and no test was deleted or weakened:
  those mutations were never arbitrated by KiCad, and the matrix now says so
  instead of counting them. The frozen upstream baseline moves the same way,
  42 → 13, because the same scanner measures both sides — the comparison stays
  tool-for-tool. `UNPROVEN` means *nobody has submitted this to KiCad*, not
  *this is broken*.

- **`set_design_rules` wrote `(min_clearance …)` into the board's `(setup …)`
  block.** KiCad keeps board constraints in the project file, under
  `board.design_settings.rules`, and refuses a board carrying those keys
  outright. It now writes `.kicad_pro` under KiCad's own key names and reads
  back before answering; a mismatch is a `ReadbackMismatch` with a rollback, not
  a success. `min_trace_width`, `min_via_size` and `min_via_drill` are refused
  by name rather than aliased: they name constraints KiCad does not have.

- **`set_active_layer` wrote a field KiCad does not have.** `kicad-cli` refused
  the resulting board outright — "Unexpected active_layer", exit 3 — while the
  tool answered success. The active layer is session state, kept in `.kicad_prl`
  as an integer; the board format has no field for it. It now goes through the
  official IPC `Set`/`GetActiveLayer` with a read-back from a second client, and
  deliberately has **no file fallback** — falling back would mean inventing the
  broken field again. With no live KiCad it refuses instead of writing.

- **`set_layer_constraints` inserted a `(rule …)` into `(setup …)`**, same class,
  same silent success, same outright refusal by `kicad-cli`. Custom rules live in
  `<board>.kicad_dru`, so that is where they go: the file is created when absent,
  values carry their unit as that format wants, and a second call for the same
  layer and constraint replaces its own rule rather than stacking another beside
  it. A rule somebody else wrote, and the comments around it, survive untouched.
  After this, nothing in the codebase inserts anything into `(setup …)`.

- **`flip_component` (new).** KiCad 10 exposes no footprint-flip command at all,
  over IPC or otherwise, so flipping is necessarily a file mutation — and it is
  refused while KiCad holds that board. The round trip is geometrically exact;
  only spelling moves. Imported from upstream `ab337816` with its design
  comments intact, because they carry real measurements rather than commentary.

- **`update_pcb_from_schematic` is deliberately not imported.** Its upstream
  design is sound — immutable plan, `kiid` identity, preserved placement,
  dry-run by default, a plan revision that goes stale, one KiCad transaction —
  but its adapter is IPC and its target a design document, so its bar is a live
  read-back. Importing 2,900 lines of the riskiest primitive on the surface into
  a release that cannot yet prove it would publish it `UNPROVEN`, which is
  exactly what this release exists to prevent. Said plainly: this fork still has
  no schematic → PCB synchronisation. The invariant analysis is written down so
  a later phase starts from it rather than from scratch.

- **The falsification gate.** The corrected implementations were replaced
  locally by the defective ones to check that the new tests actually go red, and
  on which assertion. `gate.ps1` gains an `arbitrated` step, because these
  proofs ran nowhere: CI installs no KiCad and the gate never passed
  `--ignored`. It skips loudly rather than silently when `kicad-cli` is absent,
  so a pass on a machine without KiCad cannot be mistaken for having proved
  something. One of the four arbitrated tests mutates nothing and exists only to
  prove the oracle can fail — an oracle that cannot fail agrees with anything.

Upgrading from v1.1.4 changes no call you already make. What changes is what the
matrix claims on your behalf.

## What this is

An MCP server that lets Claude and other AI assistants design KiCad 10
schematics and PCBs — and, on top of that, an **agentic control layer**: a large
internal capability surface behind a small external one, a deterministic engine
for everything that does not need generative reasoning, task state and evidence
held outside any model's context, and a verdict that comes from KiCad rather
than from an agent's opinion.

It is a fork of [mixelpixx/Konnect](https://github.com/mixelpixx/Konnect) v0.2.2
(commit `5cd6454`), under the same AGPL-3.0-only licence. The binary is still
called `konnect`, so an existing MCP client configuration keeps working.

## What changed against base Konnect

Base Konnect is a router over a tool catalogue: the client loads toolsets and
calls tools by name. That still works, unchanged. What this fork adds is a
second way in, and the machinery behind it:

- **An MCP gateway** — `kicad_describe` / `kicad_invoke`. Tools are called
  without ever appearing in `tools/list`, so the catalogue refresh a router
  forces on the client (`notifications/tools/list_changed`) disappears from the
  bill entirely.
- **A Plan IR with a deterministic executor** — a typed, reference-checked plan
  is compiled and refused before the first mutation, then applied as one batch
  with rollback (`preview_plan` / `apply_plan`).
- **Evidence and handles** — a semantic diff is on by default, snapshots and
  diffs are addressable MCP resources (`kicad://snapshot/N`), and no mutation
  lands without an audit record.
- **Task state outside the context** — objective, constraints, established
  facts and failures are filed server-side and survive a compaction.
- **A world model** — an indexed project graph with a query and neighbour
  language, cheaper than dumping the design.
- **State safety primitives** — revisions with `base_revisions` optimistic
  concurrency, an idempotency ledger, transactions and a rollback journal.
- **A local-model runtime** — the caller states an objective, a local model on
  loopback writes the Plan IR, and the server compiles, applies and verifies it.
  The verdict is `kicad-cli`'s.
- **Tool annotations and capability metadata** — every tool declares its
  read/write character, and advisory analysis says so where a model reads it.

The tool surface itself grew to **204 tools across 22 toolsets** plus 13
meta-tools — 217 served by the catalogue.

## Measured results

Baseline (upstream v0.2.2 at `5cd6454`) and this fork ran back to back on
2026-08-24, seven golden tasks × 5 repeats, 35 runs each.

| | Baseline | This fork |
|---|---|---|
| success | 35/35 | 35/35 |
| MCP calls per task (median) | 11 | 4 |
| external tokens per task (median) | 14 337 | **2 249** (−84.3 %) |
| wall clock p50 | 77 ms | 86 ms |
| capability coverage (frozen 186-tool denominator) | 22.6 % | **72.6 %** |

- **Startup surface**: 21 tools / 2 831 tokens, against a full catalogue of 215
  tools / 33 183 tokens — the surface as it stood on the measurement date, one
  tool short of today's. Through the gateway, `tools/list` never changes at all.
- **Agent mode**: 2 MCP round trips per attempt — `start_task` and
  `kicad_agent`. The plan is compiled, applied and verified server-side; the
  caller sees no intermediate round trip.
- **Retrieval**: 62.0 % precision @8 with 100 % recall @8.
- **Binary**: 23.7 MB on Windows, unstripped — measured on the v1.1.0 binary,
  up 1.9 MB from v1.0.0's 21.8 MB. v1.1.2 did not re-measure it. There is no
  `[profile.release]`,
  deliberately — adding `strip`/`lto` would change the code generation under
  every artefact the gate and the benchmarks were measured on, to improve a
  number nothing is gated on.
- Success is never judged from a model's prose. Assertions run KiCad's own ERC
  through `kicad-cli` or read the design back through the query tools.

## Trade-offs and missed criteria

Three V1 criteria were missed and one is not claimed. None of them was moved to
match the result, and no win is netted off against them.

| Criterion | Target | Measured | Verdict |
|---|---|---|---|
| `WALL_CLOCK_P50` ≤ baseline | ≤ 77 ms | 86 ms | **missed by 9 ms** |
| external tokens per task | ≤ 2 000 | 2 249 | **missed by 249** |
| `tools/list` at startup | ≤ ~1 000 | 2 831 | **missed** |
| `LLM_CALLS_PER_SUCCESSFUL_TASK` | materially below baseline | 15 → 5.5 inside the model-fit harness | **not claimed** — no baseline for this metric was ever measured |

- The fork is **slower where it guarantees something**: `recovery`, the task
  built to exercise the transaction journal, the snapshot manifest and the
  evidence store, costs +109 ms; `sch_inspection`, where there is nothing to
  guarantee, goes 14 → 6 ms. The direction is stable across samples, the
  magnitude is not.
- The 249 tokens over budget are deliberate trades: the semantic diff on by
  default, task filing, verification, and the snapshot handle at +18.
- The startup surface is only reachable by retiring the toolset-loading path,
  which would break every shipped skill. The cheaper shape was measured and
  rejected: dropping `openWorldHint` from read tools saves 78 of 342 tokens and
  would assert the MCP *open world* default about every read tool to save 2.8 %.
- **Success rate is equal, not ahead.** A scripted route succeeds by
  construction on both servers; the fork's margin is in what the route costs and
  in what happens when nobody scripts it.

## Known limitations

- **PCB tools need KiCad running** with the IPC API enabled and the board open —
  pcbnew has no headless mode, so a desktop session is required (a human is
  not). The benchmark's golden suite therefore covers the schematic and export
  paths only; the live PCB path is gated by the `live-ipc` job of the separate
  `E2E (real KiCAD)` workflow, and locally by `scripts/live-pcb-e2e.ps1`.
- **Windows is the most-tested platform.** macOS works from the release binaries
  or a source build and is not code-signed or notarised. Linux compiles and
  passes CI but has had no per-platform QA against a running KiCad.
- **The agent-mode success rate is not claimed from v1.0.0's runs** — two
  designs, one run each. The rate for the local model lives in the model-fit
  section of `docs/benchmark.md`, where it was measured with 60 attempts per arm.
- The evidence store holds 64 entries. Deepening it is deliberately deferred
  until a real session needs it (plan item D.5.3); no measured workload has
  wanted more than 32 batches of history.
- Not measured: KV-cache peak broken out of VRAM, backend prefix-cache hit
  rates, and a clean before/after pair for `qwen3.5-9b`.

## KiCad 10 status

KiCad 10.0.3 is the ground truth this release is built against; the live
schematic and PCB suites in this release were run against 10.0.6 as well. The
access strategy is fixed by what KiCad 10 actually offers, not by preference:

- **PCB over IPC** (NNG + protobuf) — coverage is complete there.
- **Schematic over the S-expression engine** — schematic IPC is empty on 10.0:
  `schematic_commands.proto` declares no commands and `getItemFromDocument()`
  returns `nullopt`. This is not a workaround, it is the only path that exists.
- **Validation and export over `kicad-cli`** — ERC, DRC, Gerber, drill, BOM,
  pick-and-place, PDF, 3D.
- KiCad's IPC API is **disabled by default** and has no protocol version, no
  async events and no pub/sub; the server is single-threaded on the UI thread.
  The event journal is therefore this project's own (revisions + targeted
  diffing + file watching), and no push notification is advertised.

**The schematic IPC path is re-evaluated at KiCad 11, not before.**
`kicad-python` 0.8.0 and `kicad-cli api-server` target KiCad 11; that is
upstream work, and forking KiCad 10 to get there was rejected. The decision to
keep the S-expression engine or move the schematic path to IPC is plan item I.1
and stays open until KiCad 11 can be measured here.

## Getting started

- **Install**: KiCad 10 → Plugin and Content Manager → *Install from File* with
  `konnect-pcm-v1.2.0-<platform>.zip` from this release, or use the standalone
  server binary. Full steps, including the Claude Desktop and Claude Code
  configuration, are in [README.md](README.md).
- **macOS: the binaries are not signed or notarised.** Gatekeeper will refuse
  them on first launch, and the PCM package is not exempt. Clear the quarantine
  attribute after installing — `xattr -dr com.apple.quarantine <path>` on the
  extracted `konnect` binary, or on the plugin folder KiCad installed it into —
  or approve it under *System Settings → Privacy & Security*. This needs an
  Apple Developer account to fix properly and has not changed since v1.0.0.
- **Build from source**: `cargo build --release -p konnect` (needs `protoc` and
  `cmake`).
- **Reproduce the numbers**: `.\gate.ps1 -Bench`, or the individual runs listed
  under *Reproducing* in [docs/benchmark.md](docs/benchmark.md).
  `python bench/m1_table.py` regenerates every table in the M.1 section from the
  committed artefacts without running or spending anything.
- **Contribute or navigate the code**: [DEV.md](DEV.md) (architecture, the agent
  layer, build requirements), [tool-directory.md](tool-directory.md) (every
  tool), [CONTRIBUTING.md](CONTRIBUTING.md).
- **Tell us how far you got**:
  [file a first-run report](https://github.com/nevenfo/kicad-agentic-mcp/issues/new?template=first-run.yml)
  — six questions, about two minutes, and worth filing especially if you gave
  up. There is no telemetry in this binary and none is planned, so a report you
  write is the only thing that ever reaches us. The tally lives in
  [docs/adoption.md](docs/adoption.md).

## Licence

AGPL-3.0-only, workspace-wide — see [LICENSE](LICENSE). The generic `kam-*`
crates (state, evidence, plan, graph, context, llm, runtime) are clean-room and
`MIT OR Apache-2.0` in their own manifests. Commercial licensing:
[COMMERCIAL.md](COMMERCIAL.md).

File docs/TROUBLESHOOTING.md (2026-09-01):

# Troubleshooting

## "KiCAD IPC socket path not configured" / "IPC connect failed"

Any tool that talks to a live KiCAD session (`save_project`, PCB editing,
`check_kicad_ui`, …) needs the IPC socket address. Since v1.1.1, Konnect resolves
it automatically from an explicit setting, then `KICAD_API_SOCKET`, then KiCad's
platform-default address. A standard install needs no copied socket path and no
`konnect-settings.json`.

Check the runtime in this order:

1. Open KiCAD normally.
2. Go to **Edit → Preferences → Plugins** and check **"Enable KiCad API"**.
   Confirm a line like this appears:

   ```
   Listening on ipc://C:\Users\<you>\AppData\Local\Temp\kicad\api.sock
   ```

3. Confirm your AI client (Claude Code, Claude Desktop, …) has the `konnect`
   MCP server registered in its own config (`.mcp.json` or
   `claude_desktop_config.json`) pointing at the `konnect` binary — see
   [examples/](../examples/).
4. Restart the AI client session so it spawns a fresh Konnect process.
5. Verify: have the AI call `open_project`. Expected:

   ```json
   { "kicad_ui_running": true, "message": "KiCAD is running and IPC is available." }
   ```

For a non-standard socket, set **IPC Socket** in Konnect's plugin settings or
pass a `konnect-settings.json` with `ipc_address` (legacy
`ipc_socket_path` is also accepted). An explicit non-empty value is never
replaced by discovery.

## PCB tools return "IPC connect failed" / "No PCB document is open"

The IPC tools talk to KiCAD's **running PCB editor**. Open your board file in
KiCAD first, and make sure the API is enabled (previous section).

## A footprint I just placed is not where the pad tools say it is

PCB **writes** go to the running PCB editor over IPC; two PCB **reads** —
`get_component_pads` and `get_pad_position` — read the board **file** on disk.
So a footprint placed or moved through a running KiCAD keeps its old
coordinates in those two answers until KiCAD saves the board.

Both answers say which source they used (`"source": "file"`), and the tools
that read over IPC say `"source": "ipc"`. If the two disagree, save the board
in KiCAD (Ctrl+S) and read again — that is the whole of it. `get_component_list`
reads over IPC and therefore always reflects the live board.

## "kicad-cli not found"

Common install paths are auto-detected (including the Windows registry). If
your install is somewhere unusual, set the path in the plugin settings dialog
or in `konnect-settings.json` (`kicad_cli`).

## A schematic write is refused while KiCad has the file open

Konnect refuses to change a `.kicad_sch` while KiCad's sibling
`~<name>.kicad_sch.lck` exists, and answers with the `conflict` error kind
naming both the schematic and the lock. Close the schematic editor normally and
retry the identical call. Read-only schematic tools keep working throughout.

Why it is not smarter than that: KiCad's lock stores a username and a hostname
and nothing else — no process id, no start time, no document token. There is no
way to tell a live editor from one a crash left behind, and guessing wrong
costs whatever is unsaved in that editor. So Konnect treats valid,
foreign-host, empty, and malformed locks alike, and never removes one for you.

If KiCad crashed, the clean fix is to reopen the project and close it normally,
which makes KiCad release its own lock. Deleting `~<name>.kicad_sch.lck` by hand
is a last resort, and only after confirming no editor still owns the file.

## Transaction recovery is blocked by divergent content

Multi-file schematic changes persist a `.konnect-transaction-<id>.json`
write-ahead journal in the project before changing any target. On restart,
Konnect safely completes files that still match either the recorded before
image or intended replacement. It never overwrites a file changed by KiCad or
another process after the journal was written.

Inspect active journals without printing their contents:

```text
konnect transaction status <project-dir>
```

Each target is reported as `pending`, `applied`, or `divergent`. Retry safe
recovery with:

```text
konnect transaction recover <project-dir>
```

If a target is divergent, first inspect the schematic in KiCad and preserve
the version you want. To unblock future transactions without changing any
schematic file, explicitly abandon the journal:

```text
konnect transaction abandon <project-dir> <transaction-id> --force
```

Abandonment renames the journal to
`.konnect-transaction-<id>.abandoned.json`; it does not restore, replace, or
delete a target. The abandoned file is retained as recovery evidence and is
ignored by future transactions. Delete it only after you have made any backup
you need.

Active and abandoned journals contain complete before/after images of every
affected schematic. Treat them as sensitive, do not attach them to bug reports
without reviewing their contents, and do not commit them. Both forms are
ignored by the repository `.gitignore`.

Cooperative document locks are stored outside the project under the platform
local-data directory. Set `KONNECT_STATE_DIR` to an absolute directory to
override that location. A relative override is rejected rather than falling
back to project-local sidecars.

## Tools don't appear after `load_toolset`

After a successful `load_toolset` call the server sends a
`notifications/tools/list_changed` notification, and MCP clients are expected to
re-fetch `tools/list` in response. If newly loaded tools never show up:

1. Check your client honors `notifications/tools/list_changed` (most current MCP
   clients do; some cache the initial tool list forever).
2. Disable any competing tool-search or tool-filter layer sitting between the
   model and the server. A Chrome-extension "tool search" that shadowed the real
   tool list caused exactly this in
   [#67](https://github.com/mixelpixx/Konnect/issues/67).
3. Re-issue `tools/list` (e.g. restart the client session) — the loaded toolset
   state lives in the server process and survives a list refresh.

## Plugin doesn't appear in KiCAD

Install via **Plugin and Content Manager → Install from File** with the
`konnect-pcm-*.zip` release asset (not the bare binary archives), then restart
KiCAD.

Look in the **PCB editor**, under *Tools → External Plugins* — and open a
project first, because pcbnew refuses to open at all without one
(*« Créer (ou ouvrir) un projet pour modifier un pcb. »*). The package also
declares a toolbar action, which KiCad 10 does not render; the menu entry is the
one that works.

## Still stuck?

**[File a first-run report](https://github.com/nevenfo/kicad-agentic-mcp/issues/new?template=first-run.yml)**
— six questions, about two minutes. A report from someone who gave up is worth
more than one from someone who succeeded: it is the only way a failure on a
machine that is not the maintainer's ever gets seen. What comes back is tallied
in [adoption.md](adoption.md).

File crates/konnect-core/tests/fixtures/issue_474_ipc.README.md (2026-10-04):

# Issue 474 live KiCad IPC captures

These protobuf payloads are real responses from KiCad 10 on 2026-09-14. They
were captured through `KiCadIpcClient::get_items_in`; they are not hand-built
approximations of KiCad objects.

- `issue_474_r1.ipc.bin` is `R1` from
  `specctra_two_resistors.kicad_pcb`. The preservation test varies only the
  symbol path and value needed to exercise a safe schematic-backed update.
- `issue_474_copper_zone_0.ipc.bin` is the filled GND copper zone from
  `crates/konnect-sexp/tests/fixtures/ecc83-pp.kicad_pcb` after KiCad 10 opened
  and upgraded the KiCad 9 board in memory.
- `issue_474_zone_0.ipc.bin` is a rule-area/keep-out from
  `crates/konnect-ipc/tests/fixtures/live_ipc.kicad_pcb`.

To regenerate, open a disposable copy of each named board in pcbnew, discover
that board with `find_open_board`, request `KotPcbFootprint` or `KotPcbZone`
through `get_items_in`, and write the returned `Any.value` bytes unchanged.
Do not substitute `build_footprint_item` or `build_zone`: this fixture exists
to preserve the distinctions present in KiCad's actual IPC messages.

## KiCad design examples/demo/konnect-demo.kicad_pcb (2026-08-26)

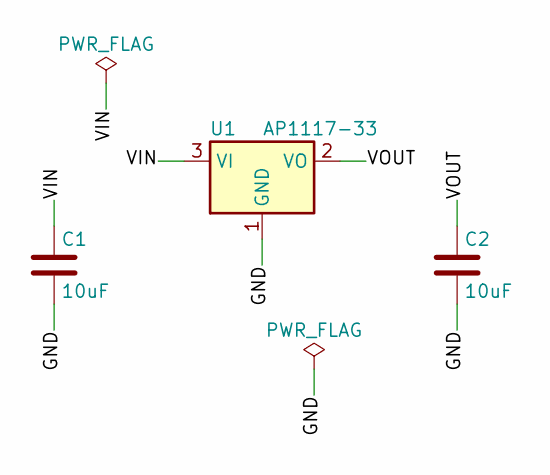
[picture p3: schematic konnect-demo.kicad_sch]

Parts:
C1, C2: 10uF; C_0805_2012Metric
U1: AP1117-33; SOT-223-3_TabPin2

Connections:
/GND: C1.2, C2.2, U1.1 (GND)
/VIN: C1.1, U1.3 (VI)
/VOUT: C2.1, U1.2 (VO)

Board: 2 copper layers, 3 parts (0 on the bottom side), 3 nets, no tracks yet.

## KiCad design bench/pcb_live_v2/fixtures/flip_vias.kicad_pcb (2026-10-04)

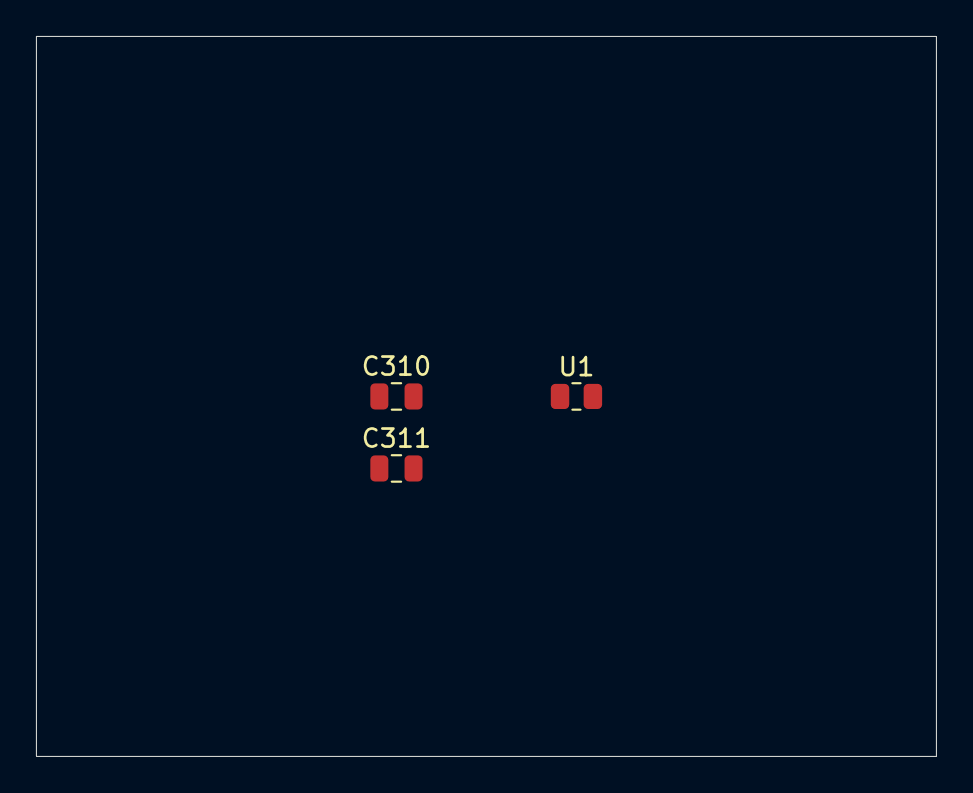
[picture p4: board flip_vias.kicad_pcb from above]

Board: 2 copper layers, 50.0 x 40.0 mm, 3 parts (0 on the bottom side), 2 nets, no tracks yet.

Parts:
C310: 100n; C_0805_2012Metric
C311: 10u; C_0805_2012Metric
U1: TPA3255; R_0805_2012Metric

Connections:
GND: C310.2, C311.2, U1.2
PVDD: C310.1, C311.1, U1.1

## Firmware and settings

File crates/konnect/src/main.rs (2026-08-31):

mod config;
mod install;
mod manifest;
mod transaction_cli;
mod transport;

use anyhow::Result;
use config::{Config, TransportMode};
use konnect_core::mcp::handler::McpHandler;
use std::io::IsTerminal;
use tracing::info;
use tracing_subscriber::{fmt, EnvFilter};

#[tokio::main]
async fn main() -> Result<()> {
    // ─── CLI argument parsing (minimal, no clap dependency) ─────────
    let args: Vec<String> = std::env::args().collect();

    // ─── Subcommand dispatch (install, uninstall, status, skill) ────
    match args.get(1).map(String::as_str) {
        Some("init") => return install::run_install(),
        Some("uninstall") => return install::run_uninstall(),
        Some("status") => return install::print_status(),
        Some("skill") => {
            let name = args.get(2).map(String::as_str).unwrap_or("");
            return install::print_skill_content(name);
        }
        Some("transaction") => return transaction_cli::run(&args[2..]),
        Some("--version") | Some("-V") => {
            println!("konnect {}", env!("CARGO_PKG_VERSION"));
            return Ok(());
        }
        Some("--help") | Some("-h") | Some("help") => {
            print_help();
            return Ok(());
        }
        _ => {}
    }

    // ─── Double-click detection ─────────────────────────────────────
    // If stdin is a terminal (user double-clicked the .exe), run friendly install.
    // If stdin is piped (Claude launched us as MCP server), start server.
    if std::io::stdin().is_terminal() {
        return install::run_double_click_install();
    }

    // ─── Auto-install on first MCP launch (safety net) ──────────────
    if install::needs_install() {
        let _ = install::run_install_silent();
    }

    // --config <path>: load config from specified file
    let config_path = args
        .iter()
        .position(|a| a == "--config")
        .and_then(|pos| args.get(pos + 1))
        .map(std::path::PathBuf::from);
    let document_context = parse_document_context(&args)?;

    let (config, ipc_address_source) = if let Some(ref path) = config_path {
        // KiCAD launches the server this way (with KICAD_API_SOCKET set), so
        // the env fallback for a blank ipc_address must apply here too (#39).
        let mut c = Config::load_from(path)?;
        let source = c.apply_env_fallbacks()?;
        (c, source)
    } else {
        Config::load_with_ipc_source()?
    };

    // ─── Initialize tracing (stderr only — stdout is MCP protocol) ──
    let filter =
        EnvFilter::try_from_default_env().unwrap_or_else(|_| EnvFilter::new(&config.log_level));

    fmt::Subscriber::builder()
        .with_writer(std::io::stderr)
        .with_env_filter(filter)
        .init();

    info!("Konnect v{} starting", env!("CARGO_PKG_VERSION"));

    match ipc_address_source {
        config::IpcAddressSource::Configured => {
            info!(
                "ipc_address: using configured value as-is -> {}",
                config.ipc_address
            );
        }
        config::IpcAddressSource::EnvVar => {
            info!(
                "ipc_address: resolved from KICAD_API_SOCKET -> {}",
                config.ipc_address
            );
        }
        config::IpcAddressSource::PlatformDefault => {
            info!(
                "ipc_address: using platform default -> {}",
                config.ipc_address
            );
        }
    }

    // Resolve kicad_cli/kicad_binary against the machine when the config
    // left them at a bare name (no explicit override). An explicit config
    // value always wins and is passed through untouched; a bare name that
    // fails to resolve anywhere is also passed through untouched, so the
    // existing "Failed to spawn kicad-cli" error stays intact (INV4: no
    // silent fallback without a validator).
    let kicad_cli_default = if cfg!(target_os = "windows") {
        "kicad-cli.exe"
    } else {
        "kicad-cli"
    };
    let kicad_binary_default = if cfg!(target_os = "windows") {
        "kicad.exe"
    } else {
        "kicad"
    };
    let kicad_cli = resolve_and_log("kicad_cli", &config.kicad_cli, kicad_cli_default, true);
    let kicad_binary = resolve_and_log(
        "kicad_binary",
        &config.kicad_binary,
        kicad_binary_default,
        false,
    );

    let server_config = konnect_core::tools::ServerConfig {
        kicad_cli,
        kicad_binary,
        ipc_address: config.ipc_address.clone(),
        project_dir: config.project_dir.clone(),
        jlcpcb_db_path: config.jlcpcb_db_path.clone(),
        auto_load_toolsets: config.auto_load_toolsets,
        mode: config.mode,
    };
    let handler = McpHandler::new_with_agent_provider_and_document_context(
        server_config,
        config.local_provider()?,
        document_context,
    )
    .await?;

    match config.transport {
        TransportMode::Stdio => {
            transport::stdio::run_stdio(handler).await?;
        }
        TransportMode::Http => {
            transport::http::run_http(handler, &config.http_address).await?;
        }
        TransportMode::Both => {
            let handler_http = handler.clone();
            let http_addr = config.http_address.clone();
            let http_task = tokio::spawn(async move {
                transport::http::run_http(handler_http, &http_addr)
                    .await
                    .expect("HTTP transport failed");
            });
            let stdio_task = tokio::spawn(async move {
                transport::stdio::run_stdio(handler)
                    .await
                    .expect("STDIO transport failed");
            });
            tokio::select! {
                _ = http_task => {},
                _ = stdio_task => {},
            }
        }
    }

    Ok(())
}

fn parse_document_context(args: &[String]) -> Result<konnect_ipc::DocumentContext> {
    let mut indexes = args
        .iter()
        .enumerate()
        .filter_map(|(index, argument)| (argument == "--document-type").then_some(index));
    let Some(index) = indexes.next() else {
        return Ok(konnect_ipc::DocumentContext::Auto);
    };
    if indexes.next().is_some() {
        anyhow::bail!("--document-type may be supplied only once");
    }

    match args.get(index + 1).map(String::as_str) {
        Some("pcb") => Ok(konnect_ipc::DocumentContext::Pcb),
        Some("schematic") => Ok(konnect_ipc::DocumentContext::Schematic),
        Some(value) => {
            anyhow::bail!("invalid --document-type '{value}': expected 'pcb' or 'schematic'")
        }
        None => anyhow::bail!("--document-type requires 'pcb' or 'schematic'"),
    }
}

/// Resolve one configured binary path (`kicad_cli` or `kicad_binary`)
/// against the machine and log, once, which branch answered. Shares
/// resolution with `install::detect_kicad()` via `install::resolve_binary`
/// so the server and `konnect status`/`init` never disagree.
fn resolve_and_log(
    label: &str,
    configured: &str,
    default_name: &str,
    try_registry: bool,
) -> String {
    use konnect_core::kicad_locate::{kicad_standard_paths, resolve_binary, KicadCliSource};

    let local_appdata = std::env::var_os("LOCALAPPDATA").map(std::path::PathBuf::from);
    let standard_paths = kicad_standard_paths(default_name, local_appdata.as_deref());

    #[cfg(target_os = "windows")]
    let (path, source) = if try_registry {
        resolve_binary(configured, default_name, &standard_paths, || {
            konnect_core::kicad_locate::detect_kicad_from_registry(default_name)
        })
    } else {
        resolve_binary(configured, default_name, &standard_paths, || None)
    };
    #[cfg(not(target_os = "windows"))]
    let (path, source) = {
        let _ = try_registry;
        resolve_binary(configured, default_name, &standard_paths, || None)
    };

    let resolved = path.to_string_lossy().to_string();
    match source {
        KicadCliSource::Configured => {
            info!("{label}: using configured value \"{configured}\" as-is");
        }
        KicadCliSource::Path => {
            info!("{label}: resolved \"{configured}\" via PATH -> {resolved}");
        }
        KicadCliSource::StandardPath => {
            info!("{label}: found at standard install path -> {resolved}");
        }
        KicadCliSource::Registry => {
            info!("{label}: found via Windows registry -> {resolved}");
        }
    }
    resolved
}

fn print_help() {
    println!("Konnect v{}", env!("CARGO_PKG_VERSION"));
    println!("MCP server for KiCAD EDA with embedded skills and agents.\n");
    println!("USAGE:");
    println!("  konnect                  Start MCP server (pipe) or install (TTY)");
    println!("  konnect init             Install skills, agents, and hooks");
    println!("  konnect uninstall        Remove all installed files");
    println!("  konnect status           Show install state");
    println!("  konnect skill <name>     Print skill content (for hooks)");
    println!("  konnect transaction status <project-dir>");
    println!("  konnect transaction recover <project-dir>");
    println!("  konnect transaction abandon <project-dir> <id> --force");
    println!("  konnect --config <path>  Start server with config file");
    println!("  konnect --document-type <pcb|schematic>  Bind KiCad plugin context");
    println!("  konnect --version        Print version");
    println!("  konnect --help           This message");
}

#[cfg(test)]
mod tests {
    use super::parse_document_context;
    use konnect_ipc::DocumentContext;

    fn args(values: &[&str]) -> Vec<String> {
        values.iter().map(|value| (*value).to_string()).collect()
    }

    #[test]
    fn document_context_requires_a_valid_single_value() {
        assert_eq!(
            parse_document_context(&args(&["konnect"])).unwrap(),
            DocumentContext::Auto
        );
        assert_eq!(
            parse_document_context(&args(&["konnect", "--document-type", "pcb"])).unwrap(),
            DocumentContext::Pcb
        );
        assert_eq!(
            parse_document_context(&args(&["konnect", "--document-type", "schematic"])).unwrap(),
            DocumentContext::Schematic
        );
        assert!(parse_document_context(&args(&["konnect", "--document-type"])).is_err());
        assert!(parse_document_context(&args(&[
            "konnect",
            "--document-type",
            "pcb",
            "--document-type"
        ]))
        .is_err());
        assert!(parse_document_context(&args(&["konnect", "--document-type", "unknown"])).is_err());
    }

    #[test]
    fn plugin_actions_pass_their_scoped_document_context() {
        let manifest: serde_json::Value =
            serde_json::from_str(include_str!("../../../plugin/plugin.json")).unwrap();
        let actions = manifest["actions"].as_array().unwrap();

        for (scope, document_type) in [("pcb", "pcb"), ("schematic", "schematic")] {
            let action = actions
                .iter()
                .find(|action| action["scopes"] == serde_json::json!([scope]))
                .unwrap_or_else(|| panic!("missing plugin action for {scope}"));
            assert_eq!(
                action["args"],
                serde_json::json!(["--document-type", document_type])
            );
        }
    }
}

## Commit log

2026-08-10 chore(lint): satisfy clippy --all-targets in schematic-editor tests
    Upstream CI runs `cargo clippy --workspace --locked -- -D warnings` without
    `--all-targets`, so test code has never been linted. Six lints fire the moment
    it is: five `assert_eq!` against a bool literal and one `len() > 0`.
    Purely mechanical, no behaviour change. The remaining `--all-targets` findings
    are `MutexGuard` held across an await in `sch_components.rs`; those are real
    correctness smells rather than style, they are inherited from upstream, and
    they are deferred to the hardening phase.
    Claude-Session: https://claude.ai/code/session_01MPeUf7Td6jPsasN5s6rAwa
2026-08-10 fix(library): resolve per-user KiCad installs, unify path discovery
    On a machine where KiCad came from `winget install KiCad.KiCad`, every symbol
    lookup failed:
    Library 'Device' not found in the installed KiCAD symbol libraries
    (lib_id 'Device:R'). Check the library name, the KiCAD install, or
    KICAD10_SYMBOL_DIR.
    winget installs "KiCad 10.0 (current user)" under
    `%LOCALAPPDATA%\Programs\KiCad\10.0`, and the search list only knew
    `C:\KiCad` and a hard-coded `C:\Program Files\KiCad`. Nothing resolved unless
    KiCad itself had launched the server and exported `KICAD10_SYMBOL_DIR`.
    The list was also written twice — `konnect-core::tools::kicad_share_roots` for
    symbols, footprints a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
2026-08-10 test(bench): golden-task harness with honest external-token accounting
    Six golden tasks, each starting from an empty temp directory, covering simple
    and hierarchical schematic authoring, template instantiation, the kicad-cli
    export path, and a recovery task where five wrong inputs must each fail loudly
    before the session builds a correct ERC-clean design.
    Design decisions worth knowing:
    - Success is never judged from a tool's prose. Assertions run KiCad's own ERC
    through kicad-cli or read the design back through query tools.
    - The client re-fetches `tools/list` on `notifications/tools/list_changed`,
    like a real client must. Skipping it undercounted the cost of `load_toolset`
    by rough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
2026-08-10 docs: Gate 0 decision, working log and measured benchmark
    plan.md carries the base-selection decision with the numbers behind it. Konnect
    wins on being the only Rust candidate, single-process, with progressive
    disclosure, transactions, atomic writes and observability already present and
    469 green tests. kicad-mcp-pro is the broader project and ten of its ideas are
    adopted, but its schematic writer depends on kicad-sch-api, which drops
    global_label nodes on save; its profiles are fixed at process start; and it
    needs three build systems. The legacy server is the TS -> Python -> SWIG chain
    Konnect exists to replace.
    Also recorded there, verified against KiCad 10.0 sources rather than from
    memo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
2026-08-10 feat(state): content revisions, idempotency ledger, rollback snapshots
    Phase D needs three guarantees a batch executor cannot fake: that the
    document still matches the plan, that a retried call does not apply twice,
    and that a batch failing halfway can be undone.
    Revisions are content-addressed rather than counted in memory, because the
    case they exist for is the user editing the file in KiCAD while an agent
    holds a plan -- a counter reports "unchanged" there, a hash cannot.
    Snapshots capture by directory, not by the paths named in the request: a
    tool that writes a hierarchical child or updates .kicad_pro as a side
    effect would otherwise survive the rollback and leave the project
    inconsist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
2026-08-10 feat(evidence): a batch says what it changed, not how many files it touched
    `ok: 3` and `3 files changed` are not reviewable answers. A batch now reports
    the domain difference between the before-image the rollback snapshot already
    held and what is on disk after: `symbol +2, wire +1`, or with `diff: "changes"`,
    `R1 moved: (100,80) -> (98,78)`.
    Two crates, split on the licence rule from plan.md D11:
    * `kam-evidence` is clean-room, MIT OR Apache-2.0, and knows nothing about
    KiCAD. A document reduces to an `ItemSet` — kind, stable key, label,
    attributes — and the diff matches by key before comparing attributes, so
    re-serialisation noise (reordered properties, reformatted floats) is r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
2026-08-11 feat(evidence): make a batch prove the design still holds, not only that it changed
    The semantic diff says what moved. It cannot say whether the board still
    passes, and this project's own error log says why that gap matters: Konnect's
    internal connectivity analysis reported zero single-pin nets on a schematic
    where `kicad-cli sch erc` reported six unconnected pins (E7). An internal
    check is not a validator.
    So `kicad_invoke` gains `verify: "auto"`, which runs KiCAD's own ERC/DRC on
    every document the batch changed:
    "validators": [{"check": "erc", "document": "ve.kicad_sch",
    "errors": 2, "warnings": 0, "fixed": 2}],
    "validators_evidence": "kicad://evidence/5"
    Three de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
2026-08-11 feat(plan): a plan the compiler can refuse before it starts
    The shape this replaces is a model in a loop: call a tool, read the result,
    decide the next call. Every arrow in that loop is an inference, which is the
    most expensive and least reliable step in the system. `kam-plan` collapses it
    to two moves — write the plan, run it — by giving the caller the two things
    the loop was really being used for.
    Expansion: one operation may become many tool calls, so a caller states an
    intent instead of enumerating and, worse, computing the calls that implement
    it. Arithmetic done in an expansion is arithmetic a model cannot get wrong.
    References: `${place.reference}` lets a later operation name an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
2026-08-11 feat(plan): describe a change once, and refuse one that cannot finish
    `kam-plan` gave the shape; this gives it a domain, a door and a number.
    konnect-core::plan is the operation library: `call`, `place`, `power`, `label`,
    `wire`, `connect`, `decouple`. Every coordinate an operation emits is snapped to
    the 1.27 mm grid before it reaches a tool, which makes E6 unreachable inside a
    plan — the same off-grid input that produced six ERC errors now produces none,
    asserted end to end against real kicad-cli rather than argued. `decouple` is the
    macro that justifies the machinery: four capacitors are one operation and nine
    tool calls, including eight power-symbol positions the caller never writes d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
2026-08-11 fix(taxonomy): put export_bom where its file lives, and record what the matrix cost
    E8, found by the capability matrix and fixed because the matrix would not stop
    saying it. `export_bom` reads a `.kicad_sch` and nothing else, and was registered
    in the `pcb_export` toolset, so it published as PARTIAL with its own misplacement
    as the stated limitation on every render.
    The registration moves to `sch_export` (7 tools; `pcb_export` 12), and the
    benchmark task that documented the workaround in a comment loses both the comment
    and the `pcb_export` entry from its toolset list.
    Measured in `toolsets` mode, the only mode that can see it: `manufacturing_exports`
    used to pay a 1 757-token catalogue pr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
2026-08-11 feat(plan): run the plan's own validators, and fail the batch when they fail
    `kam-plan`'s IR has carried a `validators` list since Phase G and nothing ran
    it: the verdict came from the enclosing `kicad_invoke(verify: "auto")`. It runs
    now, which is what turns a plan from something audited afterwards into something
    that can declare "this is only done if ERC is clean" and be held to it.
    Four names, two promises. `erc` / `drc` mean the plan introduced no new finding,
    compared by stable id against a baseline; `erc_clean` / `drc_clean` mean zero
    errors, absolutely. One name would have been ambiguous on a design that already
    has errors elsewhere — must the plan fix them, or merely not add to th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
2026-08-11 fix(geometry): snap every schematic coordinate in one place, not in most places
    E6: add_power_symbol wrote its coordinate verbatim while
    add_schematic_component snapped to the 1.27 mm grid. A power symbol placed
    at the same nominal coordinate as a resistor landed 0.33 mm off the pin and
    KiCad ERC reported "Pin not connected" for both. Nothing errored; the
    schematic was simply wrong.
    Fixing the one tool would have left the class. Every electrically
    meaningful (at x y) a schematic tool writes now goes through one
    snap_reporting() helper over konnect_sexp::geometry::snap_point, and the
    grid is a single SCHEMATIC_GRID_MM constant that plan::ops aliases rather
    than restates — two grid literals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
2026-08-11 docs(benchmark): record ProjectGraph, E6 and E7 — including the number that did not improve
    Three sections, one of which reports a result that is worse than the thing
    it replaces.
    ProjectGraph: 0 startup tokens, no movement on the golden suite, and the
    measurement the suite cannot make — an unfiltered graph_query costs 340
    tokens against 310 for the plain dump of the same six items, down from 525
    before the compact projection. It stays 10 % above, because the remainder
    is the UUID key that graph_neighbors takes as input. The win is filtering
    (109 against 310) and adjacency, and the tool description says so.
    E6: fixed as a class rather than as a symptom. Nine further tools had the
    same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
2026-08-11 feat(llm): a seam to swap local backends behind, and the ground truth to choose one
    Phase H's first two steps, and deliberately not its third. `kam-llm` is the
    provider abstraction and the hardware probe; it does not choose a model, rank
    backends, or route between them, because that decision depends on a model-fit
    benchmark that has not run yet (D31).
    * `provider` — the trait, and the message / tool / structured-output vocabulary
    it speaks. Object-safe on purpose (`async_trait`, not async-fn-in-trait): the
    router will hold `Box<dyn Provider>` and swap the backend without the caller
    changing. `ToolDef` deliberately mirrors the MCP tool-definition shape so a
    catalogue can be handed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
2026-08-17 @ J.2.2.2/J.2.2.3: author buses, and pin the stackup write as KiCADs gap
    Buses were the last MISSING row with real work behind it: the schematic
    engine handled wires and labels only, `bus` nodes rode through raw_other
    untouched, and a bus-based design could not be authored here at all.
    The engine now models bus segments, bus entries and bus aliases, and reads
    KiCADs bus-name syntax: DATA[0..7] is a vector, {SDA SCL} a group, MEM{A0 A1}
    joins with a dot, and a bare name may be an alias the sheet declares. A name
    that is none of these comes back `plain` and expands to itself, so a caller
    can hand over any label and read the kind.
    New `sch_buses` toolset: add_bus, add_bus_entry, add_bus_alias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
    [bus_two_resistors.kicad_sch]
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2026-08-17 J.3.3: commit the live fixture's named net — the via test needs one
    Run 32026034183 is clean of modals: the PCB Editor window is up, the API answers
    in 0.34s instead of polling for 60, and `moving_and_rotating_footprint_preserves_
    child_geometry` passes. The one failure is not about the runner at all —
    board has no named net to attach a via to
    `live_ipc.kicad_pcb` gained a `(net 1 "GND")` and a segment on it, and those two
    hunks were never committed, so the suite only ever passed against a working copy.
    A runner clones what is pushed. Committed as-is.
    Note for the record: this hunk predates this session's work — it was already in
    the working tree — and is published here becaus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
    [live_ipc.kicad_pcb]
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2026-08-17 K.1.2: a benchmark that can fail for the right reason
    The golden suite measured cost and correctness. It could not say that a task
    stayed inside its remit, because nothing in a task said what its remit was.
    Tasks may now declare `expected_tools`, `allowed_tools`, `forbidden_tools`, a
    `safety` tier and a `max_calls` budget, and the runner audits the executed
    path against them - not the task file. Judging the YAML against the YAML
    would make `forbidden_tools` and `missing_expected` unfalsifiable: a task
    cannot call a tool its own steps never named. In gateway mode the names come
    back out of `kicad_invoke`'s per-entry `tool` field, so what is audited is the
    server's account of what it ran.
    `s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
    [divider.kicad_sch]
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2026-08-18 D.8: loading a toolset stops meaning permission to mutate
    Effect::{Read,Write} has classified every tool since D58/D60 and nothing read it
    at execution time, so a context meant to be read-only could call any write tool.
    kam_state::OperatingMode + ModeGuard hold the mode. Clean-room per INV2: the
    crate has no idea what a tool or an effect is, and the mapping onto "may this
    call run" lives in capability::mode_allows, which needs Effect. Set once from
    KONNECT_MODE; an unrecognised value fails startup rather than falling back to
    the unrestricted default.
    D69: never elevable in-session. The guard's only public mutator is restrict_to,
    and more-restrictive-wins makes a less restrictive argument a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
    [main.rs]
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2026-08-24 P.2/P.3: preserve lib_name and every (paper ...) argument
    Backport of upstream Konnect #144 (merge 8dd54e8, fixing issue #143) and
    #209 (merge 1d31ad4), adapted rather than cherry-picked: this fork's
    ensure_lib_symbol has no SymbolLibrarySource parameter, SymbolInstance
    carries an extra unit field, and konnect-core had 22 lib_id resolution
    sites to route, not upstream's 19.
    The lib_name loss is not cosmetic. Measured with kicad-cli 10.0.3 on the
    new derived fixture: with lib_name preserved KiCad derives six named
    nets; with it dropped, four of them disappear and a generated
    Net-(C1-Pad??) takes their place. KiCad accepts both files without a
    single warning, which is why nothing caught this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
    [derived_lib_name.kicad_sch]
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2026-08-24 P.6.1: DRC reads all three of its report's categories, not one
    kicad-cli writes unrouted copper under `unconnected_items`, a sibling of
    `violations` this fork never read, so a board with open nets came back
    with zero errors and the evidence gate approved it. Measured before
    fixing: on a two-net unrouted board KiCad 10.0.3 puts both errors in that
    array and writes no violation-level `pos` at all, which is why every
    reported position was null — the field is on each item.
    `DrcReport` keeps the three arrays as Option, because an absent key is a
    pass that did not run and an empty one is a clean measurement; the
    evidence validator refuses the first rather than counting it as zero
    findings. Posi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
    [unrouted.kicad_pcb]
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2026-08-25 P.6.9.2: a pour names its net the way its own board does
    Two private find_net_id copies resolved a net name to an id by string
    offset. A KiCad 10 board has no net table and no ids, so both returned 0
    and every pour went out as (net 0) (net_name "GND") -- attached to the
    unconnected pseudo-net, an electrically orphaned copper pour reported as a
    success. The write-side counterpart of the read-side bug P.6.5 fixed, and
    the same silent-wrong shape.
    konnect_sexp::net now owns the write side too: NetRef, net_ref_for_write
    and NetRef::zone_tokens, sharing P.6.5's by-shape discriminant so read and
    write cannot disagree about which form a file is in. Both find_net_id
    copies are gone, and add_zone re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
    [kicad10_no_net_table.kicad_pcb]
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2026-08-25 P.6.8.1: a pin is resolved against the unit that actually declares it
    A multi-unit symbol places one SymbolInstance per unit under the same
    Reference. `batch_connect_to_net` looked its component up with
    `find(|i| i.reference == reference)` — always unit 1 — and every pin
    lookup went through the unit-blind `extract_lib_pins`, which superimposes
    every unit's pins onto that one placement. Asking for a pin that only
    exists on unit 2 therefore computed it against unit 1's transform and
    wrote the net label at the wrong coordinate. Wrong connectivity, not a
    wrong report.
    The lookup now collects every instance carrying the reference and keeps
    the one whose own unit declares the requested pin; a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
    [multiunit_lm2904.kicad_sch]
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2026-08-25 P.6.8.3: an orphan is what nothing meets, pins included
    `find_orphan_items` counted wire endpoints and label positions and nothing
    else, so it was wrong in both directions on any sheet with components: a
    wire drawn to a pin came back as a dangling end, and a pin with nothing on
    it was never reported at all, though the tool's description promised it.
    Far cheaper than the upstream port it was scheduled as: this fork already
    had the machinery. `find_isolated_pins`, behind `find_single_pin_nets`,
    already resolved pins per unit, honoured no_connect markers and asked the
    net graph. The fix is to use it. `placed_pins` is extracted as the one
    definition of "the pins this sheet really has", shared b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
    [orphan_items.kicad_sch]
2026-08-25 P.6.8.4: a review that looked at one sheet of twelve says so
    `run_design_review` ran its four schematic audits against the single
    `schematic` path and derived the verdict from finding counts, so "LOOKS
    GOOD — no critical issues found" was what a caller got when the audits
    found nothing because they had inspected one sheet of a hierarchy.
    The decision the task asked for first: the verdict stays in
    `design_review`, not in this fork's `evidence/` validators. The precedent
    was already in the same function — `drc_incomplete` turns a missing DRC
    pass into INCOMPLETE from evidence the handler gathered — and `evidence/`
    serves the gating validators, a different consumer.
    The four audits now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
    [hier_root.kicad_sch, hier_root_missing_sub.kicad_sch, hier_sub_clean.kicad_sch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]
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2026-08-26 R.7: the server finds KiCad where KiCad installs itself
    kicad_cli was a bare name resolved through PATH, and KiCad's Windows
    installer does not put its bin on PATH. Every kicad-cli-backed capability
    - ERC, DRC, every export, verify:"auto" - failed at first use on a stock
    per-user install. INV1 says the verdict is KiCad's; the server could not
    obtain it.
    Resolution is now a chain, shared by the server and install::detect_kicad
    so they can never point at different KiCads: explicit config, then PATH,
    then known install prefixes (now including %LOCALAPPDATA%\Programs\KiCad),
    then the registry (the per-user uninstall key's InstallLocation, not only
    HKLM\SOFTWARE\KiCad). Nothing found returns the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
    [main.rs]
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2026-08-26 R.8: the PCB half of the product finds its own socket
    ipc_address defaulted to KICAD_API_SOCKET, a variable KiCad sets only when
    it launches the plugin itself. A standalone MCP client - the configuration
    this project's own README documents - never has it, so every PCB tool
    failed until the user copied an ipc:// path out of KiCad's preferences.
    Resolution is now a chain, logged once at startup like R.7's: explicit
    config, then KICAD_API_SOCKET, then the platform default. Windows builds
    that default from std::env::temp_dir() and never existence-checks it, since
    an NNG ipc:// address there is a named pipe and the directory stays empty
    while KiCad is listening; macOS and Linux use /tmp/kicad/ap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
    [main.rs]
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2026-08-26 R.3.8: the demo's pre-state carries its own netlist, because nets come from a schematic
    Run 1 asked a board with no netlist to be routed. That is a closed path, not a
    slow one, so the task changes and the pre-state changes with it.
    examples/demo/ is now a real project: a schematic with U1 AP1117-33, C1 and C2
    10uF, footprints assigned, VIN/VOUT/GND labelled, two PWR_FLAGs - ERC 0 errors,
    0 warnings - pushed onto a 60x45 mm board once through KiCad's own Update PCB
    from Schematic. The board therefore starts the way a real layout starts: three
    footprints in a heap, five missing connections, and three real nets to close
    them with.
    The task becomes what a layout engineer does with that heap -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
    [konnect-demo.kicad_pcb, konnect-demo.kicad_sch]
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2026-08-26 R.9.1/R.9.2: two of the demo's findings fixed, and KiCad says what its default is
    F-16 - launch_kicad_ui could not find KiCad on the machine KiCad was installed
    on. Same defect shape as R.7, so the same chain (D149), applied to the GUI
    binary: find_kicad_binary scanned four hardcoded C:/D: roots and never looked
    at the per-user prefix the installer actually uses without admin rights. The
    resolver moved to konnect_core::kicad_locate, because konnect depends on
    konnect-core and not the other way round, so the installer's copy could not be
    reached from the tool that spawns the GUI. main.rs now resolves and logs
    kicad_binary at startup the way it does kicad_cli. Proved through the built
    binary w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
    [main.rs]
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2026-08-29 fix: route KiCad document context explicitly
    [main.rs]
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2026-09-09 X2-X3: make the required proof a property of the capability, and fix set_design_rules
    X2. coverage::Proof said how strongly a tool is exercised; nothing said how
    strongly it had to be, so a unit test — our code agreeing with our code — was
    enough for any claim. Capability::required_proof derives the bar from what the
    call can damage: reads and non-KiCAD writes settle internally, a written
    document needs KiCAD to load it back, a live-editor operation needs the session
    to be asked what it now holds. A proof weaker than the bar publishes UNPROVEN.
    Headline coverage on KiCAD domains falls 74.5% -> 21.2%, with 89 entries newly
    UNPROVEN. Nothing regressed: those mutations were never arbitrate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
    [clearance_pair.kicad_pcb]
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2026-09-09 X7-X9: arbitrated corpus, flip_component imported, schematic sync deferred
    X7. A small live corpus, judged by kicad-cli rather than by us. Four tests, one
    of which mutates nothing: the_oracle_can_fail drives 0.2 / 1.5 / 0.2 mm across
    the fixture's 0.75 mm gap and asserts none / one / none. Without it the other
    three would stay green if the arbiter had gone quiet — an oracle that cannot
    fail agrees with anything.
    gate.ps1 gains an "arbitrated" step, because these proofs ran nowhere: CI
    installs no KiCAD and the gate never passed --ignored. It skips loudly rather
    than silently when there is no kicad-cli, so a pass on a machine without KiCAD
    cannot be mistaken for having proved something.
    X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
    [flip_pair.kicad_pcb]
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2026-10-04 Z7: port update_pcb_from_schematic from Konnect v0.13.0, fix #779
    Selective import measured by the PCB live V2 benchmark: scenario A (sync)
    was missing in the fork, upstream passed 3/3. A copper zone now counts as
    routing only for the net it carries (CopperZoneSettings.net), so scenario C
    passes 3/3 where upstream v0.13.0 refuses. Final replay: fork functional 3/3
    on all five scenarios, no false success.
    [gr_poly_outline.kicad_pcb, specctra_two_resistors.kicad_pcb, structural_scans_kicad10.kicad_sch]

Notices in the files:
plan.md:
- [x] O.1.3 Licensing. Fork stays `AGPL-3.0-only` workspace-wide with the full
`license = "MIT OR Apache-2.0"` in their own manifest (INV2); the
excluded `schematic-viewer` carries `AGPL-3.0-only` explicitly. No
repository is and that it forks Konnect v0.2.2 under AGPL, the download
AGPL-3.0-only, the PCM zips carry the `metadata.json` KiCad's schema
